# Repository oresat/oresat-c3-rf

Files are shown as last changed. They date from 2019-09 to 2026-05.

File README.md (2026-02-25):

# oresat-c3-rf
RF Sub systems for the C3 board.  This includes the transeiver ICs and all front-end components for the uplink and downlink radios.

## [AxSem_Profiles](AxSem_Profiles)
These are a bunch of profiles that initialize the AxSem RadioLab configuration program for testing and experiments.

## [KiCad](KiCad)
Evaluation board schematics and layouts in KiCad. Some of the older Eagle CAD boards are here converted to KiCAD.

## [block-diagrams](block-diagrams)
Block diagrams of the L band receiver and UHF transceiver hardware.

## [bom](bom)
Inventory and bill-of-materials (BOMs) for evaluation boards.

## [eagle](eagle)
Evaluation board schematics and layouts in EAGLE CAD.

## [link-models](link-models)
Complete link models for command/engineering channels, telemetry/public channels, and bulk mission data channels.

## [measurements](measurements)
Evaluation board measurements using lab tools.

## [simulations](simulations)
Evaluation board simulations using ADS and/or HFSS.

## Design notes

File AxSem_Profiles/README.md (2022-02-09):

# AxSem_Profiles
These are a bunch of AxSem RadioLab profiles, and they all run on the DVK-2 motherboard.
* NB: All EDL packets are "MSB first", otherwise "LSB first"
* **Be sure to scroll right to see all of profile detail**

| Profile name | Target | Conversion | Modulation | Bitrate | Traffic | Comments |
| --- | --- | --- | --- | --- | --- | --- |
| [AX_C3_L_RX](AX_C3_L_RX) | C3 board AX5043 | L band receive through pinheader | FSK | 60k | **Rx** / L band receiver side of BER test | Created |
| [AX_Radio_Board_L_TX_Send_EDL_TXEN](AX_Radio_Board_L_TX_Send_EDL_TXEN) | AxSem daughter board| L band upconverter | FSK | 60k | **Tx** / EDL "TXEN" packet | |
| [AX_Radio_Board_RX](AX_Radio_Board_RX) | AxSem daughter board | Direct UHF | FSK | 96k | **Rx** / Receiver side of BER test | Created |
| [AX_Radio_Board_TX](AX_Radio_Board_TX) | AxSem daughter board | Direct UHF | FSK | 96k | **Tx** / Transmitter side of BER test | Created |
| [AX_Radio_Board_TX_9600](AX_Radio_Board_TX_9600) | AxSem daughter board | Direct UHF | FSK / G3RUH | 9600 | **Tx** / Transmit AX.25 Packet with payload "Hi" | Created, configuration confirmed, tested working, **used frequently** |
| [AX_Radio_Board_TX_Send_EDL_FILEUP](AX_Radio_Board_TX_Send_EDL_FILEUP) | AxSem daughter board | Direct UHF | FSK | 60k | **Tx** / EDL "FILE UPLOAD" | Created, configuration confirmed, tested working, **used frequently**, small file |
| [AX_Radio_Board_TX_Send_EDL_TXDIS](AX_Radio_Board_TX_Send_EDL_TXDIS) | AxSem daughter board | Direct UHF | FSK | 60k | **Tx** / EDL "TXDIS" | |
| [AX_Radio_Board_TX_Send_EDL_TXEN](AX_Radio_Board_TX_Send_EDL_TXEN) | AxSem daughter board | Direct UHF | FSK | 60k | **Tx** / EDL "TXEN" | Created, configuration confirmed, tested working, **First successful EDL test** |
| [AX_Vigely_Dev_Board_L_RX](AX_Vigely_Dev_Board_L_RX) | Vigely's AX5043 dev board | L band downconverter | MSK | 120k | **Rx** / L band receiver side of BER test | Created, configuration confirmed, tested working, **This was also used with C3 board using pinheader** |
| [AX_Vigely_Dev_Board_L_TX](AX_Vigely_Dev_Board_L_TX) | Vigely's AX5043 dev board | L band upconverter | MSK | 120k | **Tx** / Transmitter side of BER test | Created, configuration confirmed, tested working |
| [AX_Vigely_Dev_Board_L_TX_Send_EDL_BIG_DATA](AX_Vigely_Dev_Board_L_TX_Send_EDL_BIG_DATA) | Vigely's AX5043 dev board | L band upconverter | FSK | 60k | **Tx** / EDL "FILE UPLOAD | 1k file; Fails |
| [AX_Vigely_Dev_Board_L_TX_Send_EDL_BIG_DATA_2](AX_Vigely_Dev_Board_L_TX_Send_EDL_BIG_DATA_2) | Vigely's AX5043 dev board | L band upconverter | FSK | 60k | **Tx** / EDL "FILE UPLOAD" | 240 byte EDL frame |
| [AX_Vigely_Dev_Board_L_TX_Send_EDL_TXDIS](AX_Vigely_Dev_Board_L_TX_Send_EDL_TXDIS) | Vigely's AX5043 dev board | L band upconverter | FSK | 60k | **Tx** / EDL "TXDIS" | Created, configuration confirmed, tested working, **Only works with external synth ref** |
| [AX_Vigely_Dev_Board_L_TX_Send_EDL_TXEN](AX_Vigely_Dev_Board_L_TX_Send_EDL_TXEN) | Vigely's AX5043 dev board | L band upconverter | FSK | 60k | **Tx** / EDL "TXEN" | |

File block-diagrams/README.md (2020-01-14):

## Block diagrams for the C3 communications channels

- The primary L band receiver on the satellite.<br>___L-band-receiver-vX.X.pdf___
  - 1260 to 1270 MHz uplink engineering channel
  - 1575 MHz GPS receiver

- The primary UHF transmitter and secondary receiver on the satellite.<br>___70cm-transceiver-vX.X.pdf___
  - 435 to 438 MHz downlink engineering and public channel
  - 435 to 438 MHz uplink engineering channel

## Power budget estimations

Power budget for the C3 card radios. Includes front-end components, AX5043 IC transceiver, and supply losses.  See Excel spreadsheet for more details: ___power-budget-c3-rf.xlsx___

### Summary:
| | <br><br>Power (mW) |  <br><br>Duty Cycle (%)  | Effective<br>Current (mA)<br>@ 7.2V | <br>Energy/period<br>(mWh) |
|---|:---:|:---:|:---:|:---:|
| <strong>L band Rx</strong> | 163 | 100 | 22.6 | 244 |
| <strong>UHF Rx</strong> | 70 | 98 | 9.6 | 104 |
| <strong>UHF Tx C.W. Beacon</strong> | 1260 | 1 | 1.7 | 19 |
| <strong>UHF Tx AX.25 Beacon</strong> | 2118 | 1 | 2.9 | 32 |
| | | <strong>TOTALS:</strong> | <strong>36.9</strong> | <strong>399</strong> |

#### Notes:
- L band Rx excludes GPS receiver
- UHF Tx C.W. beacon estimated for 0.1W PA output
- UHF Tx AX.25 beacon estimated for 1.0W PA output
- Period = LEO Orbit ~ 90 min

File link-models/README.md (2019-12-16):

## Link Budget Models for the C3 Channels

The source of these link model spreadsheets are from Jan King and are located at the [AMSAT-UK IARU website](http://www.amsatuk.me.uk/iaru/spreadsheet.htm).  The spreadsheets have been customized from revision 2.5.5 which are signified by a suffix letter.  In addition, for OreSat protocol information please visit our [GitHub protocol page](https://github.com/oresat/oresat-design/tree/gh-pages/protocol).  For OreSat's bulk-data mission uplink and downlink models using 802.11b please visit our [GitHub DxWiFi page](https://github.com/oresat/oresat-dxwifi-hardware).

- The primary engineering uplink and downlink using UniClOGS (University Class Open Ground Station)
  - ___OreSat1_link_model_v2.5.5a_eng_primary.xlsx  ([PDF summary](OreSat1_link_model_v2.5.5a_eng_primary.pdf))___
  - L band 1265 MHz GMSK uplink and UHF 436.5 MHz GMSK downlink

- The secondary engineering uplink using UniClOGS (University Class Open Ground Station)
  - ___OreSat1_link_model_v2.5.5a_eng_secondary.xlsx  ([PDF summary](OreSat1_link_model_v2.5.5a_eng_secondary.pdf))___
  - UHF 436.5 MHz GMSK uplink

- The amateur radio packet beacon, APRS downlink
  - ___OreSat1_link_model_v2.5.5a_packet_beacon.xlsx  ([PDF summary](OreSat1_link_model_v2.5.5a_packet_beacon.pdf))___
  - UHF 436.5 MHz G3RUH FSK w/ AX.25

- The amateur radio CW beacon
  - ___OreSat1_link_model_v2.5.5a_CW_beacon.xlsx  ([PDF summary](OreSat1_link_model_v2.5.5a_CW_beacon.pdf))___
  - UHF 436.5 MHz 20 WPM CW in 100Hz bandwidth

Notes:
- The 'Transmitters' and 'Receivers' sheets have been customized
  - Block diagrams reflect correct design
  - System noise temperature is more precise
- The 'System Performance Summary' sheet has been customized
  - Power levels in dBm
  - More link details

## Friis formula calculators
___Friis_noise_temp_calculators.xlsx___

The noise temperature calculators for the spacecraft and ground station receivers based on Friis formula.  The link model spreadsheets include Friis formula for use with an antenna as the source.  The calculator spreadsheet includes the following tabs for comparison.

- General: [Friis formula](https://en.wikipedia.org/wiki/Friis_formulas_for_noise)
- SME: A modified formula used for systems with an antenna as the source.  [Wertz, J., Everett, D., Puschell, J. (2011). Space Mission Engineering: The New SMAD (pp. 477). Hawthorne, CA: Microcosm Press.](http://www.sme-smad.com/)
- King: Jan King's formula based on SME. Assumes the effective temperature of the feed and passives prior to the first LNA is referenced from T<sub>0</sub>
- Subtotal: The Friis formula subtotal section used in the link model spreadsheets; Receivers sheet, T<sub>ComRcvr</sub> cell. Excludes the source (antenna) and passives prior to the first LNA

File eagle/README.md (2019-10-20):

## EAGLE CAD
Evaluation boards for the C3 board radios.

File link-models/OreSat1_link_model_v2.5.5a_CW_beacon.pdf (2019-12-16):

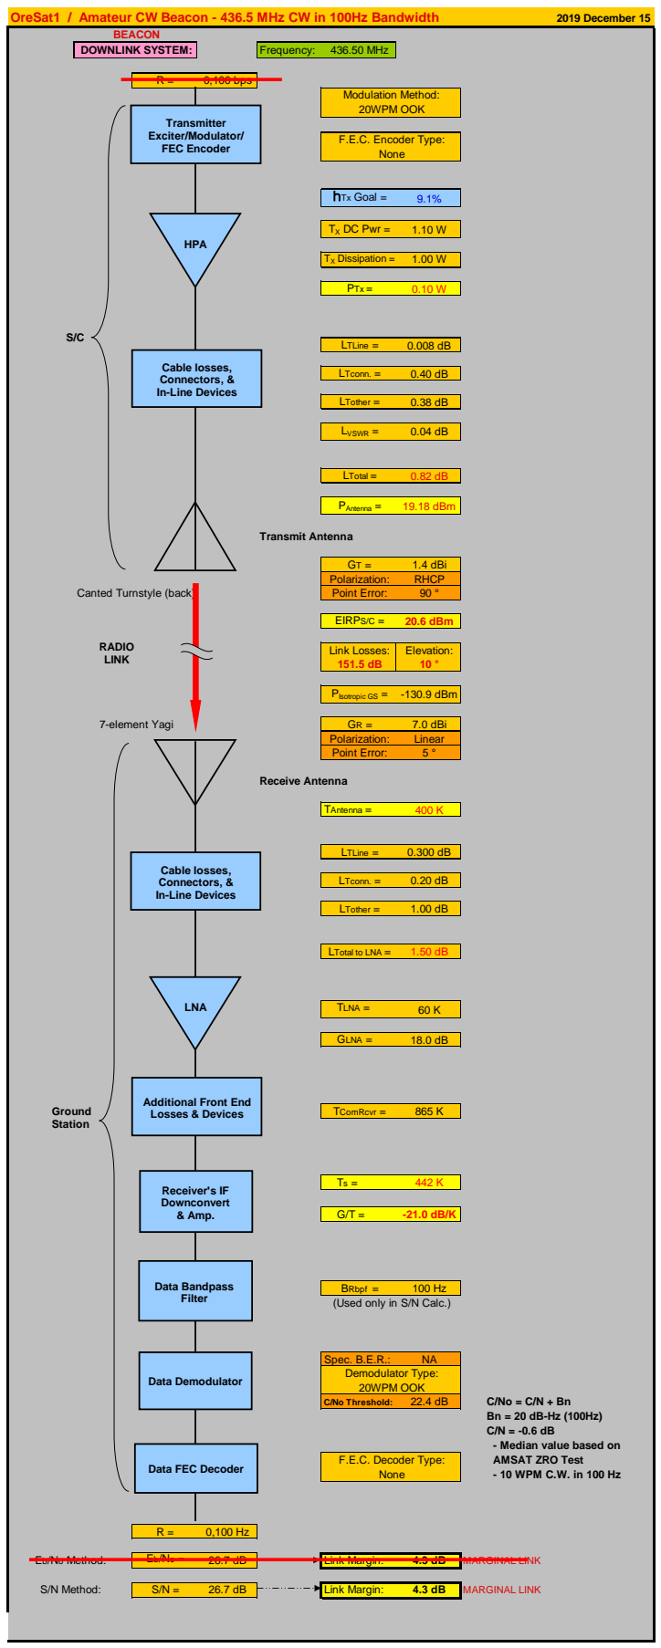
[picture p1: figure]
Frequency:; 436.50 MHz; 0,100 bps; hTx Goal =; TX DC Pwr =; TX Dissipation =; PTx =; LTLine =; LTconn. =; LTother =; LVSWR =; LTotal =; PAntenna =; 19.18 dBm; Transmit Antenna; 1.4 dBi; Polarization:; RHCP; Point Error:; EIRPS/C =; 20.6 dBm; Link Losses:; Elevation:; PIsotropic GS =; -130.9 dBm; 7.0 dBi; Linear; Receive Antenna; TAntenna =; LTotal to LNA =; TLNA =; GLNA =; TComRcvr =; BRbpf =; Spec. B.E.R.:; C/No Threshold:; Bn = 20 dB-Hz (100Hz) C/N = -0.6 dB - Median value based on AMSAT ZRO Test - 10 WPM C.W. in 100 Hz; Link Margin:; MARGINAL LINK; (Used only in S/N Calc.)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

OreSat1 / Amateur CW Beacon - 436.5 MHz CW in 100Hz Bandwidth | 2019 December 15

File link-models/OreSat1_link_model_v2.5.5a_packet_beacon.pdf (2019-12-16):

OreSat1 / Amateur Packet Beacon - 436.5 MHz G3RUH FSK via AX.25 | 2019 December 15
Frequency: | 436.50 MHz
R = | 9,600 bps
hTx Goal = | 51.3%
TX DC Pwr = | 1.95 W
TX Dissipation = | 0.95 W
PTx = | 1.00 W
LTLine = | 0.008 dB
LTconn. = | 0.40 dB
LTother = | 0.38 dB
LVSWR = | 0.04 dB
LTotal = | 0.82 dB
PAntenna = | 29.18 dBm

Transmit Antenna

GT = | 1.4 dBi
Polarization: | RHCP
Point Error: | 90 °
EIRPS/C = | 30.6 dBm
Link Losses: | Elevation:
152.4 dB | 10 °

PIsotropic GS = -120.9 dBm

GR = | 7.0 dBi
Polarization: | Linear
Point Error: | 20 °

Receive Antenna

TAntenna = | 400 K
LTLine = | 0.300 dB
LTconn. = | 0.20 dB
LTother = | 1.00 dB
LTotal to LNA = | 1.50 dB
TLNA = | 60 K
GLNA = | 18.0 dB
TComRcvr = | 865 K
Ts = | 442 K
G/T = | -21.0 dB/K
BRbpf = | 14400 Hz
Spec. B.E.R.: | 1.00E-04
Eb/No Threshold: | 10.7 dB
R = | 9,600 Hz
Eb/No = | 16.0 dB | Link Margin: | 5.3 dB | MARGINAL LINK
S/N = | 14.2 dB | Link Margin: | 3.5 dB | MARGINAL LINK

FSK, h=0.625, R.C.

BEACON
DOWNLINK SYSTEM:

Modulation Method:

F.E.C. Encoder Type:
None

Canted Turnstyle (back)

7-element Yagi

(Used only in S/N Calc.)

Demodulator Type:

S/N Method:

F.E.C. Decoder Type:
None

Eb/No Method:

FSK, h=0.625, R.C.

Ground
Station

S/C

RADIO
LINK

HPA

Transmitter
Exciter/Modulator/
FEC Encoder

Cable losses,
Connectors, &
In-Line Devices

Data FEC Decoder

Data Demodulator

Data Bandpass
Filter

LNA

Receiver's IF
Downconvert
& Amp.

Cable losses,
Connectors, &
In-Line | Devices
Additional | Front End
Losses & Devices

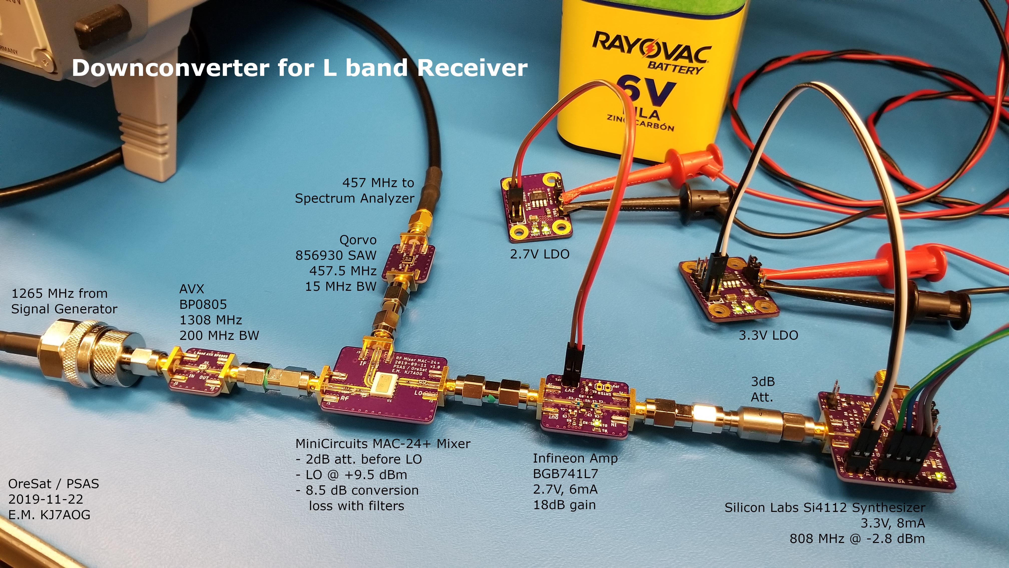
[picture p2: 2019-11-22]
photos/L-band-Downconverter.jpg

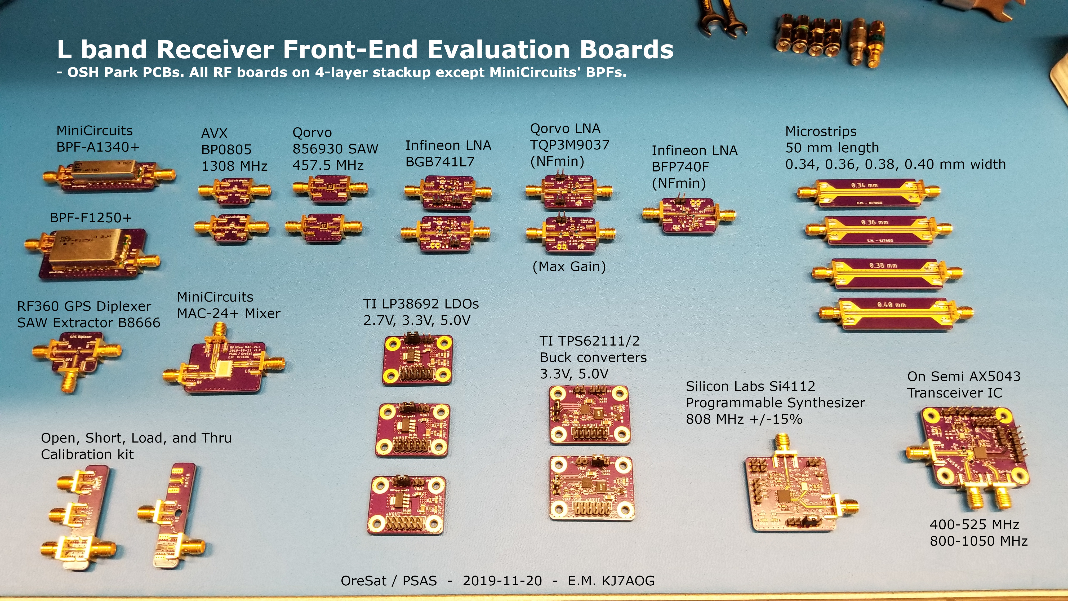
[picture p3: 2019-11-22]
photos/L-band-Eval-Boards.jpg

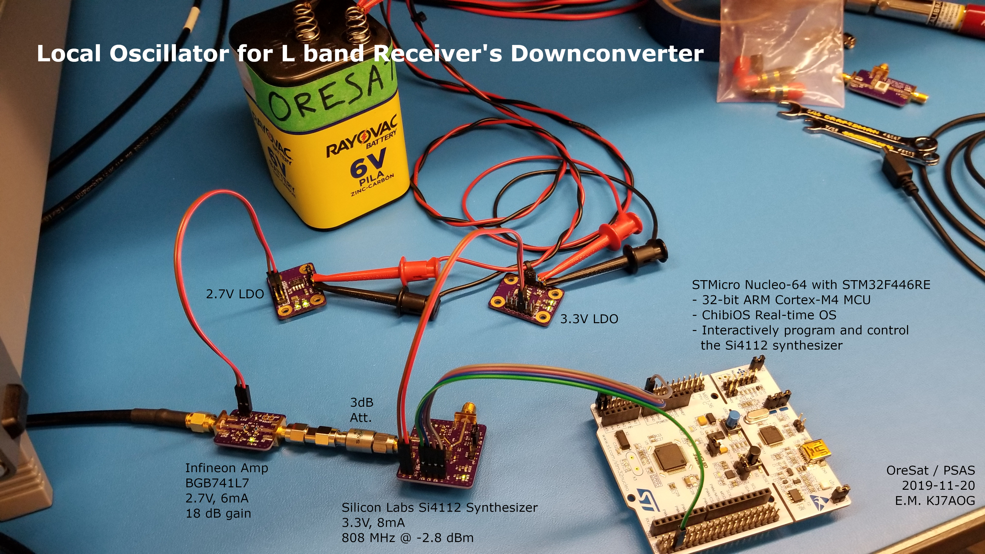
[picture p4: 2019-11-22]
photos/L-band-LO.jpg

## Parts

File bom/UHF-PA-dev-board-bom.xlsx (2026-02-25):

Bill Of Materials for OreSat UHF PA Evaluation Board
source file: amp-PA-GRF5504-with-detect.sch
Last modified: 02/24/2026
PCB version: 1.0 |  |  | P/DNP = | Place/Do Not Place (DNP is for final production boards)
BOM revision: 1 |  |  | Generic = | Any generic part with the same characteristics are OK (e.g., bypass cap)
Cnt | Part References | P/DNP | Mfg | Mfg PN | Description | Generic | Dist | Dist Part Number
1 | AT1 | P | Susumu | PAT1220-C-10DB-T5 | AT, 0805, 100mW, 10dB | N | Digikey | PAT1210CT-ND
3 | AT2, AT3, AT4 | P | Susumu | PAT0816-C-10DB-T5 | AT, 0603, 64mW, 10dB | N | Digikey | 408-2208-1-ND
3 | C12, C13 | DNP |  |  | C - 0603 | Y
2 | C9 | P | Samsung | CL10B104KA8NNNC | C - 0603, 100n, 25V, X7R | Y | Digikey | 1276-1006-1-ND
2 | C10 | P | Yageo | CC0603JRNPO9BN101 | C - 0603, 100p, 50V, C0G | Y | Digikey | 311-1069-1-ND
2 | C11 | P | Samsung | CL05C102JB5NNNC | C - 0402, 1n, C0G, 50V | Y | Digikey | 1276-1635-1-ND
1 | C16 | P | Murata | GJM1555C1H200FB01D | C - 0402, 20pF, | N | Digikey
1 | C17 | P | Murata | GJM1555C1H220FB01D | C - 0402, 22pF | N | Digikey
1 | C18 | P | Murata | GJM1555C1H3R0CB01J | C - 0402, 3pF, 50V | N | Digikey
2 | C19, C20 | P | Murata | GRM1555C1H101JA01J | C - 0402, 100pF, 50V | N | Digikey
2 | C21, C22 | P | Murata | GRM155R70J104KA01D | C - 0402, 0.1uF, 6.3V | Y | Digikey
1 | D1 | P | ROHM Semi. | SML-D13M8WT86 | LED - 0603, GREEN, Diffused | Y | Digikey | ‎846-1198-1-ND‎
2 | J1, J2 | P | Cinch | 142-0701-851 | SMA Jack Conn, 50ohm, edge mount | N | Mouser | 530-142-0701-851
1 | JP1, JP2, JP3, JP4, JP5 (1x14 req.) | P | Harwin | M20-9994045 | 2.54mm header, vertical strip, 1x40 | Y | Digikey | 952-3307-ND
1 | L1 | P | Murata | LQG15HS8N2J02D | L - 0402, 8.2nH, 5%, 550mA | N | Digikey
1 | L2 | P | Coilcraft | 0603DC-2N7XJRW | L - 0603, 2.7nH, 5%, 3.34A | N | Digikey
1 | L3 | P | Coilcraft | 0908SQ-23NJLC | L - 23n, 5%, 4.4A | N | Mouser
1 | L4 | P | Delta Electronics | 0402HP-5N6EHTS | L - 0402, 5.6nH, 3%, 1.6A | N | Digikey
1 | Q1 | P | Diodes Inc. | DMP2120U-7 | MOSFET, P-Chan, 20V, SOT23 | Y | Digikey | DMP2120U-7DICT-ND
1 | Q2 | P | Diodes Inc. | DMG2302UK-7 | MOSFET, N-Chan, 20V, SOT23 | Y | Digikey | DMG2302UK-7DICT-ND
1 | R1 | P | Stackpole | RMCF0603FT5K60 | R - 0603, 5.6k, 1%, 100ppm | Y | Digikey | RMCF0603FT5K60CT-ND
1 | R2 | P | Yageo | RC0402JR-073K3L | R - 0402, 4.4k, 5%, 100ppm | Y | Digikey
3 | R7, R8, R10 | P | Stackpole | RMCF0402FT47K0‎ | R - 0402, 47k, 1%, 100ppm | Y | Digikey | ‎RMCF0402FT47K0CT-ND‎
1 | R11 | P | Yageo | RC0402JR-076K8L | R - 0402, 6.8k, 5%, 100ppm | Y | Digikey
2 | R3, R4 | P | Stackpole | RNCF0402DTE47R0 | R - 0402, 47, 0.5%, 25ppm | Y | Digikey | RNCF0402DTE47R0CT-ND
3 | R5, R6, JP6 | P | Stackpole | RMCF0603ZT0R00‎ | R - 0603, 0, jumper | Y | Digikey | RMCF0603ZT0R00CT-ND‎
1 | U1 | P | Guerrilla | GRF5504 | PA -100 - 500MHz, 3.5W | N | Mouser
1 | U2 | P | Mini-Circuits | BDCN-20-13+ | Coupler - Bi-directional | N | Mouser | 139-BDCN-20-13
2 | U3, U4 | P | Analog Devices | LT5534ESC6#TRPBF | IC, RF Detect, 50MHz-3GHz | N | Digikey | LT5534ESC6#TRPBFCT-ND
VERSION INFO
Rev | Date | Notes
2 | 2026-02-24

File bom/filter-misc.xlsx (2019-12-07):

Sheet: bpf-L-band-BPF-F1250+
Bill Of Materials
Source: bpf-L-band-F1250+.sch |  |  | P/DNP = | Place/Do Not Place (DNP is for final production boards)
Modified: 2019-09-25 |  |  | Generic = | Any generic part with the same characteristics are OK (e.g., bypass cap)
Revision: 1
Cnt | Status | Part References | P/DNP | Mfg | Mfg PN | Description | Distributor | Dist. PN | Generic | Notes | URL
2 | USED | J1, J2 | P | Cinch | 142-0701-851 | SMA Jack Conn, 50ohm, edge mount | Dig / Mou | J658-ND / 530-142-0701-851 | N
1 | USED | U1 | P | Mini-Circuits | BPF-F1250+ | Filter - BPF, 1050 - 1450 MHz | Mini-Circuits |  | N
Revision History
Rev | Date | Notes
1 | 2019-09-25 | Initial BOM.
 | 2019-10-26 | Assembled 1x board

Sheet: bpf-L-band-BPF-A1340+
Bill Of Materials
Source: bpf-L-band-A1340+.sch |  |  | P/DNP = | Place/Do Not Place (DNP is for final production boards)
Modified: 2019-09-25 |  |  | Generic = | Any generic part with the same characteristics are OK (e.g., bypass cap)
Revision: 1
Cnt | Status | Part References | P/DNP | Mfg | Mfg PN | Description | Distributor | Dist. PN | Generic | Notes | URL
2 | USED | J1, J2 | P | Cinch | 142-0701-851 | SMA Jack Conn, 50ohm, edge mount | Dig / Mou | J658-ND / 530-142-0701-851 | N
1 | USED | U1 | P | Mini-Circuits | BPF-A1340+ | Filter - BPF, 1000 - 1800 MHz | Mini-Circuits |  | N
Revision History
Rev | Date | Notes
1 | 2019-09-25 | Initial BOM.
 | 2019-11-01 | Assembled 1x board

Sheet: bpf-IF-SAW-856930
Bill Of Materials
Source: bpf-IF-SAW-856930.sch |  |  | P/DNP = | Place/Do Not Place (DNP is for final production boards)
Modified: 2019-09-25 |  |  | Generic = | Any generic part with the same characteristics are OK (e.g., bypass cap)
Revision: 1
Cnt | Status | Part References | P/DNP | Mfg | Mfg PN | Description | Distributor | Dist. PN | Generic | Notes | URL
4 | USED | J1, J2 | P | Cinch | 142-0701-851 | SMA Jack Conn, 50ohm, edge mount | Dig / Mou | J658-ND / 530-142-0701-851 | N
2 | USED | U1 | P | Qorvo | 856930 | Filter - SAW, 457.5 MHz, 15 MHz | Mouser | 772-856930 | N | EOL
Revision History
Rev | Date | Notes
1 | 2019-09-25 | Initial BOM.
 | 2019-10-02 | Assembled 1x board
 | 2019-11-13 | Assembled 1x board

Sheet: bpf-L-band-BP0805
Bill Of Materials
Source: bpf-L-band-BP0805.sch |  |  | P/DNP = | Place/Do Not Place (DNP is for final production boards)
Modified: 2019-09-25 |  |  | Generic = | Any generic part with the same characteristics are OK (e.g., bypass cap)
Revision: 1
Cnt | Status | Part References | P/DNP | Mfg | Mfg PN | Description | Distributor | Dist. PN | Generic | Notes | URL
4 | USED | J1, J2 | P | Cinch | 142-0701-851 | SMA Jack Conn, 50ohm, edge mount | Dig / Mou | J658-ND / 530-142-0701-851 | N
2 | USED | U1 | P | AVX Corp | BP0805A1308ASTR | Filter, thin-film 0805, 1220 - 1420 MHz | Digikey | 478-12187-1-ND | N
Revision History
Rev | Date | Notes
1 | 2019-09-25 | Initial BOM.
 | 2019-10-19 | Assembled 1x board
 | 2019-10-26 | Assembled 1x board
 | 2019-12-06 | Assembled 1x board

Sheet: diplexer-GPS-RF360-B8666
Bill Of Materials
Source: diplexer-GPS-RF360-B8666.sch |  |  | P/DNP = | Place/Do Not Place (DNP is for final production boards)
Modified: 2019-09-25 |  |  | Generic = | Any generic part with the same characteristics are OK (e.g., bypass cap)
Revision: 1
Cnt | Status | Part References | P/DNP | Mfg | Mfg PN | Description | Distributor | Dist. PN | Generic | Notes | URL
3 | USED | J1, J2, J3 | P | Cinch | 142-0701-851 | SMA Jack Conn, 50ohm, edge mount | Dig / Mou | J658-ND / 530-142-0701-851 | N
1 | USED | U1 | P | RF360 | B39162B8666L210 | Diplexer, GPS SAW extractor | Digikey | B39162B8666L210CT-ND | N
Revision History
Rev | Date | Notes
1 | 2019-09-25 | Initial BOM.
 | 2019-10-19 | Assembled 1x board

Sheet: mixer-MAC-24+
Bill Of Materials
Source: mixer-MAC-24+.sch |  |  | P/DNP = | Place/Do Not Place (DNP is for final production boards)
Modified: 2019-09-25 |  |  | Generic = | Any generic part with the same characteristics are OK (e.g., bypass cap)
Revision: 1
Cnt | Status | Part References | P/DNP | Mfg | Mfg PN | Description | Distributor | Dist. PN | Generic | Notes | URL
3 | USED | J1, J2, J3 | P | Cinch | 142-0701-851 | SMA Jack Conn, 50ohm, edge mount | Dig / Mou | J658-ND / 530-142-0701-851 | N
1 | USED | U1 | P | Mini-Circuits | MAC-24+ | Mixer - double balanced | Mini-Circuits |  | N
1 | USED | AT1, AT2, AT3 | DNP | Susumu | PAT1220-C-2DB-T5 | AT, 0805, 100mW, 2dB | Digikey | PAT122CT-ND | Y | On LO
3 | USED | Z1, Z2, Z3 | P | Stackpole | RMCF0402ZT0R00‎ | R - 0402, 0, jumper | Digikey | RMCF0402ZT0R00CT-ND‎ | Y
3 | USED | AT1, AT2, AT3 | P | Stackpole | RMCF0603ZT0R00‎ | R - 0603, 0, jumper | Digikey | RMCF0603ZT0R00CT-ND‎ | Y
Revision History
Rev | Date | Notes
1 | 2019-09-25 | Initial BOM.
 | 2019-09-30 | Assembled 1x board w/ all 0 ohm
 | 2019-10-26 | Added 2dB att to LO
 | 2019-12-06 | Assembled 1x board w/ matching networks

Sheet: quad-hybrid-QCN-xxx+
Bill Of Materials
Source: quad-hybrid-QCN-xxx+.sch |  |  | P/DNP = | Place/Do Not Place (DNP is for final production boards)
Modified: 2019-11-10 |  |  | Generic = | Any generic part with the same characteristics are OK (e.g., bypass cap)
Revision: 1
Cnt | Status | Part References | P/DNP | Mfg | Mfg PN | Description | Distributor | Dist. PN | Generic | Notes | URL
3 | INV | J1, J2, J3 | P | Cinch | 142-0701-851 | SMA Jack Conn, 50ohm, edge mount | Dig / Mou | J658-ND / 530-142-0701-851 | N
 | - | J4 | DNP | Cinch | 142-0701-851 | SMA Jack Conn, 50ohm, edge mount | Dig / Mou | J658-ND / 530-142-0701-851 | N
2 | INV | R1, R2 | P | Yageo | RT0402BRD07100RL | R - 0402, 100, 0.1%, 25ppm | Digikey | YAG2301CT-ND | Y | Precision 100 ohm resistor
Revision History
Rev | Date | Notes
1 | 2019-11-10 | Initial BOM.

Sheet: template
Bill Of Materials
Source: schematic-name.sch |  |  | P/DNP = | Place/Do Not Place (DNP is for final production boards)
Modified: yyyy-mm-dd |  |  | Generic = | Any generic part with the same characteristics are OK (e.g., bypass cap)
Revision: 1
Cnt | Status | Part References | P/DNP | Mfg | Mfg PN | Description | Distributor | Dist. PN | Generic | Notes | URL
Revision History
Rev | Date | Notes
1 | yyyy-mm-dd | Initial BOM.

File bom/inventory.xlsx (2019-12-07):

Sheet: Inventory
Inventory of parts for all boards
Cnt | Status | Mfg | Mfg PN | Description | Distributor | Dist. PN | Notes
0 | C3-RF Box | Harwin | M20-9980645 | 2.54mm header, vertical strip, 12 pos (2x6) | Digikey | 952-2125-ND
69 | C3-RF Box | Harwin | M20-9994045 | 2.54mm header, vertical strip, 1x40 (by x1) | Digikey | 952-3307-ND
24 | C3-RF Box | Harwin | M20-1060200 | 2.54mm housing, 2 position | Digikey | 952-2227-ND
9 | C3-RF Box | Harwin | M20-1060400 | 2.54mm housing, 4 position | Digikey | 952-2229-ND
4 | C3-RF Box | Susumu | PAT1220-C-2DB-T5 | AT, 0805, 100mW, 2dB | Digikey | PAT122CT-ND
1 | C3-RF Box | Susumu | PAT1220-C-4DB-T5 | AT, 0805, 100mW, 4dB | Digikey | PAT124CT-ND
2 | C3-RF Box | Susumu | PAT1220-C-6DB-T5 | AT, 0805, 100mW, 6dB | Digikey | PAT126CT-ND
2 | C3-RF Box | Susumu | PAT1220-C-8DB-T5 | AT, 0805, 100mW, 8dB | Digikey | PAT128CT-ND
1 | C3-RF Box | MPD | SBH431-1AS | Battery holder, 3x AAA, cover, 6" leads, switch | Digikey | SBH431-1AS-ND
1 | C3-RF Box | TI | TPS62112RSAR | Buck Reg, 5.0V, 1.5A | Digikey | ‎296-39444-1-ND‎
6 | C3-RF Box | Samsung | CL05C8R2CB5NNNC | C - 0402 8.2p, C0G, 50V | Digikey | ‎1276-1729-1-ND
6 | C3-RF Box | Samsung | CL05C102JB5NNNC | C - 0402, 1n, C0G, 50V | Digikey | 1276-1635-1-ND
10 | C3-RF Box | Kemet | C0402C222J3GACTU | C - 0402, 2.2n, C0G, 25V | Digikey | 399-8957-1-ND
88 | C3-RF Box | Samsung | CL05C220JB5NNNC‎ | C - 0402, 22p, C0G, 50V | Digikey | ‎1276-1116-1-ND
96 | C3-RF Box | Samsung | CL05C561JB5NNNC | C - 0402, 560p, C0G, 50V | Digikey | 1276-1709-1-ND
8 | C3-RF Box | Samsung | CL05C060CB5NNNC | C - 0402, 6.0p, C0G, 50V | Digikey | 1276-1607-1-ND
6 | C3-RF Box | Samsung | CL05C820JB5NNNC | C - 0402, 82p, C0G, 50V | Digikey | ‎1276-1726-1-ND
8 | C3-RF Box | Samsung | CL10C103JA8NNNC | C - 0603, 10n, C0G, 25V | Digikey | 1276-2172-1-ND
86 | C3-RF Box | Samsung | CL10A105KA8NNNC | C - 0603, 1u, X5R, 25V | Digikey | 1276-1102-1-ND
87 | C3-RF Box | Samsung | CL10B223KA8NNNC | C - 0603, 22n, X7R, 25V | Digikey | 1276-1999-1-ND
6 | C3-RF Box | Samsung | CL10A475KO8NNNC | C - 0603, 4.7u, X5R, 16V | Digikey | 1276-1784-1-ND
92 | C3-RF Box | Samsung | CL10B473KB8NNNC | C - 0603, 47n, X7R, 50V | Digikey | 1276-1063-1-ND
95 | C3-RF Box | Samsung | CL21A106KOQNNNG | C - 0805, 10u, X5R, 16V | Digikey | 1276-6455-1-ND
3 | C3-RF Box | Samsung | CL31A226KOHNNNE | C - 1206, 22u, X5R, 16V | Digikey | 1276-3048-1-ND
1+ | Glenn? | Mini-Circuits | BDCN-20-13+ | Coupler - Bi-directional | Mini-Circuits
1 | C3-RF Box | On Semi | BAS16XV2T1G | Diode, Gen Purp, 200mA, SOD523 | Digikey | BAS16XV2T1GOSCT-ND
1 | C3-RF Box | RF360 | B39162B8666L210 | Diplexer, GPS SAW extractor | Digikey | B39162B8666L210CT-ND
0 | C3-RF Box | Mini-Circuits | BPF-A1340+ | Filter - BPF, 1000 - 1800 MHz | Mini-Circuits
2 | C3-RF Box | Mini-Circuits | BPF-F1250+ | Filter - BPF, 1050 - 1450 MHz | Mini-Circuits
6 | C3-RF Box | Mini-Circuits | BPF-C450+ | Filter - BPF, 400 - 510 MHz | Mini-Circuits
8 | C3-RF Box | Qorvo | 856930 | Filter - SAW, 457.5 MHz, 15 MHz | Mouser | 772-856930 | EOL
0 | C3-RF Box | AVX Corp | BP0805A1308ASTR | Filter, thin-film 0805, 1220 - 1420 MHz | Digikey | 478-12187-1-ND
2 | C3-RF Box | Coilcraft | 0402CS-1N8XGL | L - 0402, 1.8n | Mouser | 994-0402CS-1N8XGLU
0 | C3-RF Box | Coilcraft | 0402HP-18NXGL | L - 0402, 18n | Mouser | 994-0402HP-18NXGLU
1 | C3-RF Box | Coilcraft | 0402CS-2N0XGL | L - 0402, 2.0n | Mouser | 994-0402CS-2N0XGLW
1 | C3-RF Box | Coilcraft | 0402CS-3N9XGL | L - 0402, 3.9n | Mouser | 994-0402CS-3N9XGLW
6 | C3-RF Box | Murata | LQW15AN43NG8ZD | L - 0402, 43n, 515mA, 516mohm, +/-2% | Digikey | 490-15447-1-ND
2 | C3-RF Box | Coilcraft | 0402HP-47NXGL | L - 0402, 47n | Mouser | 994-0402HP-47NXGLU
5 | C3-RF Box | Murata | LQW18AN10NG00D‎ | L - 0603, 10n, 650mA, 110mohm, +/-2% | Digikey | 490-6856-1-ND
0 | C3-RF Box | Murata | LQW18AN27NG00D | L - 0603, 27n, 440mA, 210mohm, +/-2% | Digikey | 490-6879-1-ND
5 | C3-RF Box | Murata | LQW18AN91NG8ZD | L - 0603, 91n, 520mA, 540mohm, +/-2% | Digikey | 490-15756-1-ND
8 | C3-RF Box | TI | LP2985IM5-1.8/NOPB | LDO Voltage Regulator, 150mA, EN, 1.8V Fixed | Digikey | LP2985IM5-1.8/NOPBCT-ND
1 | C3-RF Box | TI | LP38692MP-3.3/NOPB | LDO Voltage Regulator, 1A, EN, 3.3V Fixed | Digikey | LP38692MP-3.3/NOPBCT-ND
2 | C3-RF Box | TI | LP38692MP-5.0/NOPB | LDO Voltage Regulator, 1A, EN, 5.0V Fixed | Digikey | ‎LP38692MP-5.0/NOPBCT-ND
2 | C3-RF Box | TI | LP38692MP-ADJ/NOPB | LDO Voltage Regulator, 1A, EN, Adjustable | Digikey | LP38692MP-ADJ/NOPBCT-ND
10 | C3-RF Box | ROHM Semi. | SML-D13M8WT86 | LED - 0603, GREEN, Diffused | Digikey | ‎846-1198-1-ND‎
5 | C3-RF Box | ROHM Semi. | SML-D12U8WT86‎ | LED - 0603, RED, Diffused | Digikey | 511-1580-1-ND‎
4 | C3-RF Box | Infineon | BGB707L7ESDE6327XTSA1 | LNA, general purpose | Mouser | 726-SP000531308
1 | C3-RF Box | Infineon | BGB741L7ESDE6327XTSA1‎ | LNA, general purpose | Digikey | ‎BGB741L7ESDE6327XTSA1CT-ND
4 | C3-RF Box | Qorvo | TQP3M9036 | LNA, high performance | Mouser | 772-TQP3M9036
1 | C3-RF Box | Qorvo | TQP3M9037 | LNA, high performance | Mouser | 772-TQP3M9037
0 | C3-RF Box | Infineon | BFP740FH6327XTSA1 | LNA, RF Transistor, NPN, 42GHz, TSFP4 | Digikey | BFP740FH6327XTSA1CT-ND
1 | C3-RF Box | Mini-Circuits | MAC-24+ | Mixer - double balanced | Mini-Circuits
5 | C3-RF Box | Diodes Inc. | DMP2120U-7 | MOSFET, P-Chan, 20V, SOT23 | Digikey | DMP2120U-7DICT-ND
3 | C3-RF Box | Qorvo | TQP7M9105 | PA, 50 - 1500 MHz, 1W, 5V | Mouser | 772-TQP7M9105
3 | C3-RF Box | Silicon Labs | SI4123-D-GM | PLL RF Synthesizer, dual out, RF1 & IF | Mouser | 634-SI4123-D-GM
2 | C3-RF Box | Silicon Labs | SI4112-D-GM | PLL RF Synthesizer, single out, IF | Mouser | 634-SI4112-D-GM
3 | C3-RF Box | Mini-Circuits | QCN-19+ | Quadrature hybrid, 1100 - 1925 MHz | Mini-Circuits
107 | C3-RF Box | Stackpole | RMCF0402ZT0R00‎ | R - 0402, 0, jumper | Digikey | RMCF0402ZT0R00CT-ND‎
9 | C3-RF Box | Stackpole | RMCF0402FT1K00CT-ND | R - 0402, 1.0k, 1%, 100ppm | Digikey | RMCF0402FT1K00CT-ND
10 | C3-RF Box | Yageo | RT0402BRD07100RL | R - 0402, 100, 0.1%, 25ppm | Digikey | YAG2301CT-ND
2 | C3-RF Box | Yageo | RT0402BRD0711K8L‎ | R - 0402, 11.8k, 0.1%, 25ppm | Digikey | ‎YAG4166CT-ND‎
2 | C3-RF Box | Yageo | RT0402BRD0713K7L‎ | R - 0402, 13.7k, 0.1%, 25ppm | Digikey | ‎YAG4172CT-ND
83 | C3-RF Box | Stackpole | RMCF0402FT47K0‎ | R - 0402, 47k, 1%, 100ppm | Digikey | ‎RMCF0402FT47K0CT-ND‎
79 | C3-RF Box | Stackpole | RMCF0603ZT0R00‎ | R - 0603, 0, jumper | Digikey | RMCF0603ZT0R00CT-ND‎
4 | C3-RF Box | Stackpole | RMCF0603FT1K50‎ | R - 0603, 1.5k, 1%, 100ppm | Digikey | ‎RMCF0603FT1K50CT-ND
8 | C3-RF Box | Stackpole | RMCF0603FT10K0‎ | R - 0603, 10k, 1%, 100ppm | Digikey | ‎RMCF0603FT10K0CT-ND
90 | C3-RF Box | Stackpole | RMCF0603FT2K70‎ | R - 0603, 2.7k, 1%, 100ppm | Digikey | RMCF0603FT2K70CT-ND‎
9 | C3-RF Box | Stackpole | RMCF0603FT220R | R - 0603, 220, 1%, 100ppm | Digikey | RMCF0603FT220RCT-ND
9 | C3-RF Box | Stackpole | RMCF0603FT27R0 | R - 0603, 27, 1%, 100ppm | Digikey | RMCF0603FT27R0CT-ND
8 | C3-RF Box | Stackpole | RMCF0603FT27K0‎ | R - 0603, 27k, 1%, 100ppm | Digikey | RMCF0603FT27K0CT-ND
9 | C3-RF Box | Stackpole | RMCF0603FT39R0 | R - 0603, 39, 1%, 100ppm | Digikey | RMCF0603FT39R0CT-ND
9 | C3-RF Box | Stackpole | RMCF0603FT45K3 | R - 0603, 45.3k, 1%, 100ppm | Digikey | RMCF0603FT45K3CT-ND
3 | C3-RF Box | Stackpole | RMCF0603FT5K60 | R - 0603, 5.6k, 1%, 100ppm | Digikey | RMCF0603FT5K60CT-ND
8 | C3-RF Box | On Semi | AX5043-1-TW30 | RF Transceiver, 1GHz max | Digikey | AX5043-1-TW30OSCT-ND
11 | C3-RF Box | Cinch | 142-0701-851 | SMA Jack Conn, 50ohm, edge mount | Digikey/Mouser | J658-ND / 530-142-0701-851
10 | C3-RF Box | Amphenol | 132360 | SMA Male Terminator, 50 ohm | Digikey | ACX1251-ND
94 | C3-RF Box | Harwin | M20-1160042 | Socket contact, gold, crimp, 22-30 AWG | Digikey | 952-2157-1-ND
8 | C3-RF Box | Taitien | TYKTBLSANF-16.000000 | TCXO, 16.000 MHz, 1.8V, Clipped SW, 1ppm | Digikey | 1664-1323-1-ND
7 | C3-RF Box | ECS | ECS-TXO-3225-160-TR | TCXO, 16.000 MHz, 3.3V, HCMOS, 2.5ppm | Mouser | 520-TXO-3225-16.0T
History
Date | Notes
- | Initial Inventory
2019-07-29 | Assembled 2x microstrip-test-4-layer-sma-34-40
2019-08-23 | Assembled 1x synthesizer-Si4123
2019-09-30 | Assembled 1x mixer-MAC-24+ w/ all 0 ohm
2019-10-02 | Assembled 1x LP38692-adj-2.7, LP38692-3.3, and SAW-856930 boards
2019-10-04 | Assembled 1x TPS62111-3.3, and 2x microstrip-text-4-layer-sma-36-38
2019-10-05 | Assembled 1x TPS62112-5.0, and LP38692-5.0
2019-10-06 | Assembled 1x sythesizer-Si4112
2019-10-07 | Assembled 1x LNA-TQP3M9037
2019-10-19 | Assembled 1x Diplexer-B8666, 1x AVX BPF BP0805, and 1x LNA-BGB741L7ESD
2019-10-26 | Assembled 1x AVX BPF BP0805, and added 2dB att to mixer LO
2019-10-26 | Assembled 1x BPF-F1250+
2019-11-01 | Received MiniCircuits samples, 1x BPF-A1340+, 2x MAC-24+
2019-11-01 | Assembled 1x BPF-A1340+
2019-11-13 | Assembled 1x SAW-856930, 1x LNA-TQP3M9037, 1x LNA-BGB741L7ESD
2019-11-17 | Assembled 1x transceiver-AX5043
2019-11-18 | Assembled 1x LNA-BFP740F
2019-12-06 | Assembled 1x synthesizer-Si4112, transceiver-AX5043, mixer-MAC-24+ w/ matching, AVX BPF BP0805

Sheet: Boards
Inventory of evaluation boards
Name | Board | Available | Assembled | Stencil | BOM | BOM File | Notes
amp-LNA-BFP740Fxxx | RCVD | 2 | 1 | REORD ? | RCVD | amps | Stencil fixed tCream on BFP7xxF
amp-LNA-BGB741L7ESD | RCVD | 1 | 2 | RCVD | RCVD | amps
amp-LNA-L-band-TQP3M9037 | RCVD | 3 |  | RCVD |  | amps
amp-LNA-S-band-TQP3M9037 | RCVD | 1 | 2 | RCVD | RCVD | amps | Used for L and S band; new name amp-LNA-TQP3M9037
amp-LNA-UHF-TQP3M9036 | RCVD | 3 |  | RCVD |  | amps
bpf-IF-SAW-856930 | RCVD | 1 | 2 | RCVD | RCVD | filter-misc
bpf-L-band-BP0805 | RCVD | 0 | 3 | RCVD | RCVD | filter-misc
bpf-L-band-BPF-A1340+ | RCVD | 2 | 1 | NA | RCVD | filter-misc
bpf-L-band-BPF-F1250+ | RCVD | 2 | 1 | NA | RCVD | filter-misc
diplexer-GPS-RF360-B8666 | RCVD | 2 | 1 | RCVD | RCVD | filter-misc
microstrip-test-4-layer-sma-34-40 | RCVD | 1 | 2 | NA | RCVD | test-boards
microstrip-test-4-layer-sma-36-38 | RCVD | 2 | 2 | NA | RCVD | test-boards
mixer-MAC-24+ | RCVD | 2 | 1 | REORD ? | RCVD | filter-misc | Stencil fixed tCream on MAC-24+
power-linear-LP38692 | RCVD | 0 | 3 | RCVD | RCVD | power | Variations: 3.3V fix, 2.7V adj, 5.0V fix
power-switching-TPS6211x | RCVD | 1 | 2 | RCVD | RCVD | power | Variations: 3.3V fix, 5.0V fix
quad-hybrid-QCN-xxx+ | ORDRD |  |  | RCVD | RCVD | filter-misc
synthesizer-IF-Si4112 | RCVD | 1 | 2 | RCVD | RCVD | synthesizers
synthesizer-RF-Si4123 | RCVD | 2 | 1 | RCVD | RCVD | synthesizers
transceiver-AX5043 | RCVD | 4 | 2 | RCVD | RCVD | radio
calibration-thru-reflect-match-sma | RCVD | 1 | 2 | NA | RCVD | test-boards | microstrip-test-38 used for line standard, thru can be cut for open standard

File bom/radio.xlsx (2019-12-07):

Bill Of Materials
Source: transceiver-AX5043.sch |  |  | P/DNP = | Place/Do Not Place (DNP is for final production boards)
Modified: 2019-11-10 |  |  | Generic = | Any generic part with the same characteristics are OK (e.g., bypass cap)
Revision: 1
Cnt | Status | Part References | P/DNP | Mfg | Mfg PN | Description | Distributor | Dist. PN | Generic | Notes | URL
2 | USED | JP1, JP5 |  | Harwin | M20-9994045 | 2.54mm header, vertical strip, 1x40 (by x1) | Digikey | 952-3307-ND
2 | USED | JP2, JP6 |  | Harwin | M20-9994045 | 2.54mm header, vertical strip, 1x40 (by x1) | Digikey | 952-3307-ND
1 | USED | JP3 |  | Harwin | M20-9994045 | 2.54mm header, vertical strip, 1x40 (by x1) | Digikey | 952-3307-ND
1 | USED | JP4 |  | Harwin | M20-9994045 | 2.54mm header, vertical strip, 1x40 (by x1) | Digikey | 952-3307-ND
2 | USED | C1, C2 |  | Samsung | CL05C8R2CB5NNNC | C - 0402 8.2p, C0G, 50V | Digikey | ‎1276-1729-1-ND
2 | USED | C3, C4 |  | Samsung | CL05C102JB5NNNC | C - 0402, 1n, C0G, 50V | Digikey | 1276-1635-1-ND
2 | USED | C7, C8 |  | Samsung | CL05C220JB5NNNC‎ | C - 0402, 22p, C0G, 50V | Digikey | ‎1276-1116-1-ND
2 | USED | C5, C6 |  | Samsung | CL05C820JB5NNNC | C - 0402, 82p, C0G, 50V | Digikey | ‎1276-1726-1-ND
3 | - | C9, C11, C14 | NP |  |  | C - 0603
1 | USED | C16 |  | Samsung | CL10C103JA8NNNC | C - 0603, 10n, C0G, 25V | Digikey | 1276-2172-1-ND
1 | USED | C17 |  | Samsung | CL10A105KA8NNNC | C - 0603, 1u, X5R, 25V | Digikey | 1276-1102-1-ND
2 | USED | C10, C13 |  | Samsung | CL10B223KA8NNNC | C - 0603, 22n, X7R, 25V | Digikey | 1276-1999-1-ND
2 | USED | C12, C15 |  | Samsung | CL10A475KO8NNNC | C - 0603, 4.7u, X5R, 16V | Digikey | 1276-1784-1-ND
2 | USED | L1, L2 |  | Murata | LQW15AN43NG8ZD | L - 0402, 43n, 515mA, 516mohm, +/-2% | Digikey | 490-15447-1-ND
2 | USED | L3, L4 |  | Murata | LQW18AN91NG8ZD | L - 0603, 91n, 520mA, 540mohm, +/-2% | Digikey | 490-15756-1-ND
1 | USED | U2 |  | TI | LP2985IM5-1.8/NOPB | LDO Voltage Regulator, 150mA, EN, 1.8V Fixed | Digikey | LP2985IM5-1.8/NOPBCT-ND | Y
1 | USED | D1 |  | ROHM Semi. | SML-D13M8WT86 | LED - 0603, GREEN, Diffused | Digikey | ‎846-1198-1-ND‎
1 | - | R3 | NP |  |  | R - 0402
3 | USED | R2, R8, R9 |  | Stackpole | RMCF0402ZT0R00‎ | R - 0402, 0, jumper | Digikey | RMCF0402ZT0R00CT-ND‎
1 | USED | R1 |  | Stackpole | ?? | R - 0402, 150 ohm | Digikey | ?? |  | Updated to 150 ohm from 1k
2 | - | R4, R5 | NP |  |  | R - 0603
1 | USED | R7 |  | Stackpole | RMCF0603ZT0R00‎ | R - 0603, 0, jumper | Digikey | RMCF0603ZT0R00CT-ND‎
1 | USED | R6 |  | Stackpole | RMCF0603FT1K50‎ | R - 0603, 1.5k, 1%, 100ppm | Digikey | ‎RMCF0603FT1K50CT-ND
1 | USED | U1 |  | On Semi | AX5043-1-TW30 | RF Transceiver, 1GHz max | Digikey | AX5043-1-TW30OSCT-ND
3 | USED | J1, J2, J3 |  | Cinch | 142-0701-851 | SMA Jack Conn, 50ohm, edge mount | Digikey/Mouser | J658-ND / 530-142-0701-851
1 | USED | X1 |  | Taitien | TYKTBLSANF-16.000000 | TCXO, 16.000 MHz, 1.8V, Clipped SW, 1ppm | Digikey | 1664-1323-1-ND | N
Revision History
Rev | Date | Notes
1 | 2019-11-10 | Initial BOM.
 | 2019-11-17 | Assembled 1x transceiver-AX5043
 | 2019-12-06 | Assembled 1x transceiver-AX5043

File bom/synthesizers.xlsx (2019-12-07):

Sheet: synthesizer-IF-Si4112
Bill Of Materials
Source: synthesizer-IF-Si4112.sch |  |  | P/DNP = | Place/Do Not Place
Modified: 2019-09-25 |  |  | Generic = | Any generic part with the same characteristics
Revision: 1
Cnt | Status | Part References | P/DNP | Mfg | Mfg PN | Description | Distributor | Dist. PN | Generic | Notes | URL
4 | USED | JP1, JP3, JP4, JP7 | P | Harwin | M20-9994045 | 2.54mm header, vertical strip, 2 pos (1x40) | Digikey | 952-3307-ND | Y | 1x40 strip
1 | USED | JP2 | P | Harwin | M20-9994045 | 2.54mm header, vertical strip, 3 pos (1x40) | Digikey | 952-3307-ND | Y | 1x40 strip
1 | USED | JP5 | P | Harwin | M20-9994045 | 2.54mm header, vertical strip, 4 pos (1x40) | Digikey | 952-3307-ND | Y | 1x40 strip
1 | USED | C5 | P | Samsung | CL05C561JB5NNNC | C - 0402, 560p, C0G, 50V | Digikey | 1276-1709-1-ND | Y
- | - | C2, C3, C6, C7, C9 | DNP |  |  | C - 0603
2 | USED | C8, C10 | P | Samsung | CL10A105KA8NNNC | C - 0603, 1u, X5R, 25V | Digikey | 1276-1102-1-ND | Y
3 | USED | C1, C4, C7 | P | Samsung | CL10B223KA8NNNC | C - 0603, 22n, X7R, 25V | Digikey | 1276-1999-1-ND | Y
1 | USED | D3 | P | On Semi | BAS16XV2T1G | Diode, Gen Purp, 200mA, SOD523 | Digikey | BAS16XV2T1GOSCT-ND | Y
1 | USED | L2 | P | Coilcraft | 0402HP-18NXGL | L - 0402, 18n | Mouser | 994-0402HP-18NXGLU | N | U or W packaging
1 | USED | L1 | P | Coilcraft | 0402CS-3N9XGL | L - 0402, 3.9n | Mouser | 994-0402CS-3N9XGLW | N | U or W packaging
1 | USED | D1 | P | ROHM Semi. | SML-D13M8WT86 | LED - 0603, GREEN, Diffused | Digikey | ‎846-1198-1-ND‎ | Y
1 | USED | D2 | P | ROHM Semi. | SML-D12U8WT86‎ | LED - 0603, RED, Diffused | Digikey | 511-1580-1-ND‎ | Y
1 | USED | Q1 | P | Diodes Inc. | DMP2120U-7 | MOSFET, P-Chan, 20V, SOT23 | Digikey | DMP2120U-7DICT-ND | Y
1 | USED | U1 | P | Silicon Labs | SI4112-D-GM | PLL RF Synthesizer, single out, IF | Mouser | 634-SI4112-D-GM | N
- | - | R11 | DNP |  |  | R - 0402
1 | USED | JP6 | P | Stackpole | RMCF0402ZT0R00‎ | R - 0402, 0, jumper | Digikey | RMCF0402ZT0R00CT-ND‎ | N
5 | USED | R3, R4, R5, R6, R10 | P | Stackpole | RMCF0402FT47K0‎ | R - 0402, 47k, 1%, 100ppm | Digikey | ‎RMCF0402FT47K0CT-ND‎ | Y
- | - | R7, R8 | DNP |  |  | R - 0603
2 | USED | R2, R9 | P | Stackpole | RMCF0603ZT0R00‎ | R - 0603, 0, jumper | Digikey | RMCF0603ZT0R00CT-ND‎ | Y
2 | USED | R1, R12 | P | Stackpole | RMCF0603FT2K70‎ | R - 0603, 2.7k, 1%, 100ppm | Digikey | RMCF0603FT2K70CT-ND‎ | Y
2 | USED | J1, J3 | P | Cinch | 142-0701-851 | SMA Jack Conn, 50ohm, edge mount | Dig / Mou | J658-ND / 530-142-0701-851 | N
1 | USED | X1 | P | ECS | ECS-TXO-3225-160-TR | TCXO, 16.000 MHz, 3.3V, HCMOS, 2.5ppm | Mouser | 520-TXO-3225-16.0T | N
Revision History
Rev | Date | Notes
1 | 2019-09-25 | Initial BOM.
 | 2019-10-06 | Assembled 1x sythesizer-Si4112
 | 2019-12-06 | Assembled 1x sythesizer-Si4112

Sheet: synthesizer-RF-Si4123
Bill Of Materials
Source: synthesizer-RF-Si4123.sch |  |  | P/DNP = | Place/Do Not Place
Modified: 2019-08-01 |  |  | Generic = | Any generic part with the same characteristics
Revision: 1
Cnt | Status | Part References | P/DNP | Mfg | Mfg PN | Description | Distributor | Dist. PN | Generic | Notes | URL
3 | USED | JP1-4, 6 | P | Harwin | M20-9994045 | 2.54mm header, vertical strip, 2 pos (1x40) | Digikey | 952-3307-ND | Y | 1x40 strip
1 | USED | JP5 | P | Harwin | M20-9994045 | 2.54mm header, vertical strip, 4 pos (1x40) | Digikey | 952-3307-ND | Y | 1x40 strip
1 | USED | JP6 | P | Harwin | M20-1060200 | 2.54mm housing, 2 position | Digikey | 952-2227-ND | Y | only battery
1 | USED | JP5 | P | Harwin | M20-1060400 | 2.54mm housing, 4 position | Digikey | 952-2229-ND | Y
1 | USED | JP6 | P | MPD | SBH431-1AS | Battery holder, 3x AAA, cover, 6" leads, switch | Digikey | SBH431-1AS-ND | Y
2 | USED | C8, C9 | P | Samsung | CL05C561JB5NNNC | C - 0402, 560p, C0G, 50V | Digikey | 1276-1709-1-ND | Y
- | - | C1, C2, C5, C6, C11, C12, C16 | DNP |  |  | C - 0603
2 | USED | C10, C14 | P | Samsung | CL10A105KA8NNNC | C - 0603, 1u, X5R, 25V | Digikey | 1276-1102-1-ND | Y
3 | USED | C3, C4, C7 | P | Samsung | CL10B223KA8NNNC | C - 0603, 22n, X7R, 25V | Digikey | 1276-1999-1-ND | Y
1 | USED | C13 | P | Samsung | CL21A106KOQNNNG | C - 0805, 10u, X5R, 16V | Digikey | 1276-6455-1-ND | Y
1 | USED | L1 | P | Coilcraft | 0402CS-1N8XGL | L - 0402, 1.8n | Mouser | 994-0402CS-1N8XGLU | N | U or W packaging
1 | USED | L2 | P | Coilcraft | 0402HP-18NXGL | L - 0402, 18n | Mouser | 994-0402HP-18NXGLU | N | U or W packaging
1 | USED | L3 | P | Coilcraft | 0402CS-2N0XGL | L - 0402, 2.0n | Mouser | 994-0402CS-2N0XGLW | N | U or W packaging
1 | USED | L4 | P | Coilcraft | 0402HP-47NXGL | L - 0402, 47n | Mouser | 994-0402HP-47NXGLU | N | U or W packaging
1 | USED | U1 | P | TI | LP38692MP-3.3/NOPB | LDO Voltage Regulator, 1A, EN, 3.3V Fixed | Digikey | LP38692MP-3.3/NOPBCT-ND | N
1 | USED | D1 | P | ROHM Semi. | SML-D13M8WT86 | LED - 0603, GREEN, Diffused | Digikey | ‎846-1198-1-ND‎ | Y
1 | USED | D2 | P | ROHM Semi. | SML-D12U8WT86‎ | LED - 0603, RED, Diffused | Digikey | 511-1580-1-ND‎ | Y
1 | USED | U2 | P | Silicon Labs | SI4123-D-GM | PLL RF Synthesizer, dual out, RF1 & IF | Mouser | 634-SI4123-D-GM | N
2 | USED | R9, R10 | P | Stackpole | RMCF0402ZT0R00‎ | R - 0402, 0, jumper | Digikey | RMCF0402ZT0R00CT-ND‎ | N
4 | USED | R3, R4, R5, R6 | P | Stackpole | RMCF0402FT47K0‎ | R - 0402, 47k, 1%, 100ppm | Digikey | ‎RMCF0402FT47K0CT-ND‎ | Y
- | - | R7, R8 | DNP |  |  | R - 0603
4 | USED | R1, R2, R13, JMP1 | P | Stackpole | RMCF0603ZT0R00‎ | R - 0603, 0, jumper | Digikey | RMCF0603ZT0R00CT-ND‎ | Y | JMP1 can be 0805 too
2 | USED | R11, R12 | P | Stackpole | RMCF0603FT2K70‎ | R - 0603, 2.7k, 1%, 100ppm | Digikey | RMCF0603FT2K70CT-ND‎ | Y
2 | USED | J1, J2, J3 | P | Cinch | 142-0701-851 | SMA Jack Conn, 50ohm, edge mount | Dig / Mou | J658-ND / 530-142-0701-851 | N | J3 (ref-in) not required
6 | USED | JP5, JP6 | P | Harwin | M20-1160042 | Socket contact, gold, crimp, 22-30 AWG | Digikey | 952-2157-1-ND | Y
1 | USED | X1 | P | ECS | ECS-TXO-3225-160-TR | TCXO, 16.000 MHz, 3.3V, HCMOS, 2.5ppm | Mouser | 520-TXO-3225-16.0T | N
Revision History
Rev | Date | Notes
1 | 2019-08-01 | Initial BOM for 3x boards, excludes some connectors
2 | 2019-08-23 | Assembled 1x dual-synthesizer

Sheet: template
Bill Of Materials
Source: schematic-name.sch |  |  | P/DNP = | Place/Do Not Place
Modified: yyyy-mm-dd |  |  | Generic = | Any generic part with the same characteristics
Revision: 1
Cnt | Status | Part References | P/DNP | Mfg | Mfg PN | Description | Distributor | Dist. PN | Generic | Notes | URL
Revision History
Rev | Date | Notes
1 | yyyy-mm-dd | Initial BOM.

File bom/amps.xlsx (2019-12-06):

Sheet: amp-LNA-BFP740Fxxx
Bill Of Materials
Source: amp-LNA-BFP740Fxxx.sch |  |  | P/DNP = | Place/Do Not Place (DNP is for final production boards)
Modified: 2019-11-10 |  |  | Generic = | Any generic part with the same characteristics are OK (e.g., bypass cap)
Revision: 1
Cnt | Status | Part References | P/DNP | Mfg | Mfg PN | Description | Distributor | Dist. PN | Generic | Notes | URL
2 | USED | JP1, JP2 |  | Harwin | M20-9994045 | 2.54mm header, vertical strip, 2 pos, 1x40 (by x1) | Digikey | 952-3307-ND
1 | - | C6 | NP |  |  | C - 0402
2 | USED | C1, C2 |  | Samsung | CL05C220JB5NNNC‎ | C - 0402, 22p, C0G, 50V | Digikey | ‎1276-1116-1-ND
1 | - | C3 | NP |  |  | C - 0603
1 | USED | C5 |  | Samsung | CL10A105KA8NNNC | C - 0603, 1u, X5R, 25V | Digikey | 1276-1102-1-ND
2 | USED | C4, C8 |  | Samsung | CL10B473KB8NNNC | C - 0603, 47n, X7R, 50V | Digikey | 1276-1063-1-ND
1 | USED | L3 |  | Murata | LQW15 | L - 0402, 1.8n (around) |  |  |  | 2.0n used
1 | USED | L2 |  | Murata | LQW18AN10NG00D‎ | L - 0603, 10n, 650mA, 110mohm, +/-2% | Digikey | 490-6856-1-ND
1 | USED | L1 |  | Murata | LQW18AN47NG00D | L - 0603, 47n, 380mA, 290mohm, +/-2% | Digikey | 490-6894-1-ND |  | 91n used
1 | USED | D1 |  | ROHM Semi. | SML-D13M8WT86 | LED - 0603, GREEN, Diffused | Digikey | ‎846-1198-1-ND‎
1 | USED | Q2 |  | Infineon | BFP740FH6327XTSA1 | LNA, RF Transistor, NPN, 42GHz, TSFP4 | Digikey | BFP740FH6327XTSA1CT-ND
1 |  | Q1 | NP | Diodes Inc. | DMP2120U-7 | MOSFET, P-Chan, 20V, SOT23 | Digikey | DMP2120U-7DICT-ND |  | 0 ohm placed
1 |  | R3 | NP | Stackpole | RMCF0402FT47K0‎ | R - 0402, 47k, 1%, 100ppm | Digikey | ‎RMCF0402FT47K0CT-ND‎
1 | USED | R1 |  | Stackpole | RMCF0603FT1K50‎ | R - 0603, 1.5k, 1%, 100ppm | Digikey | ‎RMCF0603FT1K50CT-ND
1 | USED | R6 |  | Stackpole | RMCF0603FT220R | R - 0603, 220, 1%, 100ppm | Digikey | RMCF0603FT220RCT-ND
1 | USED | R5 |  | Stackpole | RMCF0603FT27R0 | R - 0603, 27, 1%, 100ppm | Digikey | RMCF0603FT27R0CT-ND
1 | USED | R4 |  | Stackpole | RMCF0603FT39R0 | R - 0603, 39, 1%, 100ppm | Digikey | RMCF0603FT39R0CT-ND
1 | USED | R2 |  | Stackpole | RMCF0603FT45K3 | R - 0603, 45.3k, 1%, 100ppm | Digikey | RMCF0603FT45K3CT-ND
2 | USED | J1, J2 |  | Cinch | 142-0701-851 | SMA Jack Conn, 50ohm, edge mount | Digikey/Mouser | J658-ND / 530-142-0701-851
Revision History
Rev | Date | Notes
1 | 2019-11-10 | Initial BOM.
 | 2019-11-18 | Assembled 1x LNA-BFP740F, 0603 jumper placed for Q1

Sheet: amp-LNA-BGB741L7ESD
Bill Of Materials
Source: amp-LNA-BGB741L7ESD.sch |  |  | P/DNP = | Place/Do Not Place (DNP is for final production boards)
Modified: 2019-09-28 |  |  | Generic = | Any generic part with the same characteristics are OK (e.g., bypass cap)
Revision: 1
Cnt | Status | Part References | P/DNP | Mfg | Mfg PN | Description | Distributor | Dist. PN | Generic | Notes | URL
3 | USED | JP1, JP2 | P | Harwin | M20-9994045 | 2.54mm header, vertical strip, 2 pos (1x40) | Digikey | 952-3307-ND | Y | 1x40 strip
4 | USED | C1, C2 | P | Samsung | CL05C220JB5NNNC‎ | C - 0402, 22p, C0G, 50V | Digikey | ‎1276-1116-1-ND | Y
- | - | C4 | DNP |  |  | C - 0603
2 | USED | C5 | P | Samsung | CL10A105KA8NNNC | C - 0603, 1u, X5R, 25V | Digikey | 1276-1102-1-ND | Y
4 | USED | C3, C6 | P | Samsung | CL10B473KB8NNNC | C - 0603, 47n, X7R, 50V | Digikey | 1276-1063-1-ND | Y
4 | USED | L1, L2 | P | Murata | LQW18AN27NG00D | L - 0603, 27n, 440mA, 210mohm, +/-2% | Digikey | 490-6879-1-ND | N
2 | USED | D1 | P | ROHM Semi. | SML-D13M8WT86 | LED - 0603, GREEN, Diffused | Digikey | ‎846-1198-1-ND‎ | Y
2 | USED | U1 | P | Infineon | BGB741L7ESDE6327XTSA1‎ | MMIC LNA, General purpose | Digikey | ‎BGB741L7ESDE6327XTSA1CT-ND | N
1 | USED | Q1 | P | Diodes Inc. | DMP2120U-7 | MOSFET, P-Chan, 20V, SOT23 | Digikey | DMP2120U-7DICT-ND | Y
1 | USED | R3 | P | Stackpole | RMCF0402FT47K0‎ | R - 0402, 47k, 1%, 100ppm | Digikey | ‎RMCF0402FT47K0CT-ND‎ | Y
3 | USED | R5 | P | Stackpole | RMCF0603ZT0R00‎ | R - 0603, 0, jumper | Digikey | RMCF0603ZT0R00CT-ND‎ | Y
2 | USED | R1 | P | Stackpole | RMCF0603FT1K50‎ | R - 0603, 1.5k, 1%, 100ppm | Digikey | ‎RMCF0603FT1K50CT-ND | Y
2 | USED | R2 | P | Stackpole | RMCF0603FT27K0‎ | R - 0603, 27k, 1%, 100ppm | Digikey | RMCF0603FT27K0CT-ND | Y
4 | USED | J1, J2 | P | Cinch | 142-0701-851 | SMA Jack Conn, 50ohm, edge mount | Digikey | J658-ND | N
Revision History
Rev | Date | Notes
1 | 2019-09-28 | Initial BOM.
 | 2019-10-19 | Assembled 1x board
 | 2019-11-13 | Assembled 1x board, 0603 jumper for Q1, NP R3, NP JP2

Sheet: amp-LNA-TQP3M9037
Bill Of Materials
Source: amp-LNA-TQP3M9037.sch |  |  | P/DNP = | Place/Do Not Place (DNP is for final production boards)
Modified: 2019-09-30 |  |  | Generic = | Any generic part with the same characteristics are OK (e.g., bypass cap)
Revision: 1
Cnt | Status | Part References | P/DNP | Mfg | Mfg PN | Description | Distributor | Dist. PN | Generic | Notes | URL
3 | USED | JP1, JP2 | P | Harwin | M20-9994045 | 2.54mm header, vertical strip, 2 pos (1x40) | Digikey | 952-3307-ND | Y | 1x40 strip
2 | USED | C1 | P | Samsung | CL05C220JB5NNNC‎ | C - 0402, 22p, C0G, 50V | Digikey | ‎1276-1116-1-ND | Y
2 | USED | C2 | P | Samsung | CL05C060CB5NNNC | C - 0402, 6.0p, C0G, 50V | Digikey | 1276-1607-1-ND | Y
- | - | C3, C5 | DNP |  |  | C - 0603
2 | USED | C6 | P | Samsung | CL10A105KA8NNNC | C - 0603, 1u, X5R, 25V | Digikey | 1276-1102-1-ND | Y
2 | USED | C4 | P | Samsung | CL10B473KB8NNNC | C - 0603, 47n, X7R, 50V | Digikey | 1276-1063-1-ND | Y
3 | USED | L1, L2 | P | Murata | LQW18AN10NG00D‎ | L - 0603, 10n, 650mA, 110mohm, +/-2% | Digikey | 490-6856-1-ND | N
2 | USED | D1 | P | ROHM Semi. | SML-D13M8WT86 | LED - 0603, GREEN, Diffused | Digikey | ‎846-1198-1-ND‎ | Y
2 | USED | U1 | P | Qorvo | TQP3M9037 | MMIC LNA, High performance | Mouser | 772-TQP3M9037 | N
- | - | R3, R4 | DNP |  |  | R - 0603
2 | USED | R2 | P | Stackpole | RMCF0603ZT0R00‎ | R - 0603, 0, jumper | Digikey | RMCF0603ZT0R00CT-ND‎ | Y
2 | USED | R1 | P | Stackpole | RMCF0603FT5K60 | R - 0603, 5.6k, 1%, 100ppm | Digikey | RMCF0603FT5K60CT-ND | Y
4 | USED | J1, J2 | P | Cinch | 142-0701-851 | SMA Jack Conn, 50ohm, edge mount | Digikey | J658-ND | N
Revision History
Rev | Date | Notes
1 | 2019-09-30 | Initial BOM. Input matching for NFmin and output matching for L and S band (wideband).
 | 2019-10-07 | Assembled 1x board for min NF
 | 2019-11-13 | Assembled 1x board, NP JP2, L1 placed for max gain

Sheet: template
Bill Of Materials
Source: schematic-name.sch |  |  | P/DNP = | Place/Do Not Place (DNP is for final production boards)
Modified: yyyy-mm-dd |  |  | Generic = | Any generic part with the same characteristics are OK (e.g., bypass cap)
Revision: 1
Cnt | Status | Part References | P/DNP | Mfg | Mfg PN | Description | Distributor | Dist. PN | Generic | Notes | URL
Revision History
Rev | Date | Notes
1 | yyyy-mm-dd | Initial BOM.

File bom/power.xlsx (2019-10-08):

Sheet: power-linear-LP38692-2.7V-adj
Bill Of Materials
Source: power-linear-LP38692.sch |  |  | P/DNP = | Place/Do Not Place
Modified: 2019-09-26 |  |  | Generic = | Any generic part with the same characteristics
Revision: 1
Cnt | Status | Part References | P/DNP | Mfg | Mfg PN | Description | Distributor | Dist. PN | Generic | Notes | URL
1 | USED | JP2 | P | Harwin | M20-9980645 | 2.54mm header, vertical strip, 12 pos (2x6) | Digikey | 952-2125-ND | Y
1 | USED | JP1 | P | Harwin | M20-9994045 | 2.54mm header, vertical strip, 2 pos (1x40) | Digikey | 952-3307-ND | Y | 1x40 strip
1 | USED | JP3 | P | Harwin | M20-9994045 | 2.54mm header, vertical strip, 3 pos (1x40) | Digikey | 952-3307-ND | Y | 1x40 strip
1 | USED | C1 | P | Samsung | CL21A106KOQNNNG | C - 0805, 10u, X5R, 16V | Digikey | 1276-6455-1-ND | Y
1 | USED | C2 | P | Samsung | CL31A226KOHNNNE | C - 1206, 22u, X5R, 16V | Digikey | 1276-3048-1-ND | Y
1 | USED | U1 | P | TI | LP38692MP-ADJ/NOPB | LDO Voltage Regulator, 1A, EN, Adjustable | Digikey | LP38692MP-ADJ/NOPBCT-ND | N
2 | USED | D1, D2 | P | ROHM Semi. | SML-D13M8WT86 | LED - 0603, GREEN, Diffused | Digikey | ‎846-1198-1-ND‎ | Y
- | - | R3, R4 | DNP |  |  | R - 0402
1 | USED | R6 | P | Yageo | RT0402BRD0711K8L‎ | R - 0402, 11.8k, 0.1%, 25ppm | Digikey | ‎YAG4166CT-ND‎ | Y | for Vadj
1 | USED | R5 | P | Yageo | RT0402BRD0713K7L‎ | R - 0402, 13.7k, 0.1%, 25ppm | Digikey | ‎YAG4172CT-ND | Y | for Vadj
1 | USED | R2 | P | Stackpole | RMCF0603FT1K50‎ | R - 0603, 1.5k, 1%, 100ppm | Digikey | ‎RMCF0603FT1K50CT-ND | Y
1 | USED | R1 | P | Stackpole | RMCF0603FT2K70‎ | R - 0603, 2.7k, 1%, 100ppm | Digikey | RMCF0603FT2K70CT-ND‎ | Y
Revision History
Rev | Date | Notes
1 | 2019-09-26 | Initial BOM.
 | 2019-10-02 | Assembled 1x board

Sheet: power-linear-LP38692-3.3V-fix
Bill Of Materials
Source: power-linear-LP38692.sch |  |  | P/DNP = | Place/Do Not Place
Modified: 2019-09-26 |  |  | Generic = | Any generic part with the same characteristics
Revision: 1
Cnt | Status | Part References | P/DNP | Mfg | Mfg PN | Description | Distributor | Dist. PN | Generic | Notes | URL
1 | USED | JP2 | P | Harwin | M20-9980645 | 2.54mm header, vertical strip, 12 pos (2x6) | Digikey | 952-2125-ND | Y
1 | USED | JP1 | P | Harwin | M20-9994045 | 2.54mm header, vertical strip, 2 pos (1x40) | Digikey | 952-3307-ND | Y | 1x40 strip
1 | USED | JP3 | P | Harwin | M20-9994045 | 2.54mm header, vertical strip, 3 pos (1x40) | Digikey | 952-3307-ND | Y | 1x40 strip
1 | USED | C1 | P | Samsung | CL21A106KOQNNNG | C - 0805, 10u, X5R, 16V | Digikey | 1276-6455-1-ND | Y
1 | USED | C2 | P | Samsung | CL31A226KOHNNNE | C - 1206, 22u, X5R, 16V | Digikey | 1276-3048-1-ND | Y
1 | USED | U1 | P | TI | LP38692MP-3.3/NOPB | LDO Voltage Regulator, 1A, EN, 3.3V Fixed | Digikey | LP38692MP-3.3/NOPBCT-ND | N
2 | USED | D1, D2 | P | ROHM Semi. | SML-D13M8WT86 | LED - 0603, GREEN, Diffused | Digikey | ‎846-1198-1-ND‎ | Y
- | - | R3, R4, R5, R6 | DNP |  |  | R - 0402
1 | USED | R2 | P | Stackpole | RMCF0603FT2K70‎ | R - 0603, 2.7k, 1%, 100ppm | Digikey | RMCF0603FT2K70CT-ND‎ | Y
1 | USED | R1 | P | Stackpole | RMCF0603FT5K60 | R - 0603, 5.6k, 1%, 100ppm | Digikey | RMCF0603FT5K60CT-ND | Y
Revision History
Rev | Date | Notes
1 | 2019-09-26 | Initial BOM.
 | 2019-10-02 | Assembled 1x board

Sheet: power-linear-LP38692-5.0V-fix
Bill Of Materials
Source: power-linear-LP38692.sch |  |  | P/DNP = | Place/Do Not Place
Modified: 2019-09-26 |  |  | Generic = | Any generic part with the same characteristics
Revision: 1
Cnt | Status | Part References | P/DNP | Mfg | Mfg PN | Description | Distributor | Dist. PN | Generic | Notes | URL
1 | USED | JP2 | P | Harwin | M20-9980645 | 2.54mm header, vertical strip, 12 pos (2x6) | Digikey | 952-2125-ND | Y
1 | USED | JP1 | P | Harwin | M20-9994045 | 2.54mm header, vertical strip, 2 pos (1x40) | Digikey | 952-3307-ND | Y | 1x40 strip
1 | USED | JP3 | P | Harwin | M20-9994045 | 2.54mm header, vertical strip, 3 pos (1x40) | Digikey | 952-3307-ND | Y | 1x40 strip
1 | USED | C1 | P | Samsung | CL21A106KOQNNNG | C - 0805, 10u, X5R, 16V | Digikey | 1276-6455-1-ND | Y
1 | USED | C2 | P | Samsung | CL31A226KOHNNNE | C - 1206, 22u, X5R, 16V | Digikey | 1276-3048-1-ND | Y
1 | USED | U1 | P | TI | LP38692MP-5.0/NOPB | LDO Voltage Regulator, 1A, EN, 5.0V Fixed | Digikey | ‎LP38692MP-5.0/NOPBCT-ND | N
2 | USED | D1, D2 | P | ROHM Semi. | SML-D13M8WT86 | LED - 0603, GREEN, Diffused | Digikey | ‎846-1198-1-ND‎ | Y
- | - | R3, R4, R5, R6 | DNP |  |  | R - 0402
1 | USED | R1 | P | Stackpole | RMCF0603FT10K0‎ | R - 0603, 10k, 1%, 100ppm | Digikey | ‎RMCF0603FT10K0CT-ND | Y
1 | USED | R2 | P | Stackpole | RMCF0603FT5K60 | R - 0603, 5.6k, 1%, 100ppm | Digikey | RMCF0603FT5K60CT-ND | Y
Revision History
Rev | Date | Notes
1 | 2019-09-26 | Initial BOM.
 | 2019-10-05 | Assembled 1x board

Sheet: power-switching-TPS62111-3.3V
Bill Of Materials
Source: power-switching-TPS6211x.sch |  |  | P/DNP = | Place/Do Not Place
Modified: 2019-09-26 |  |  | Generic = | Any generic part with the same characteristics
Revision: 1
Cnt | Status | Part References | P/DNP | Mfg | Mfg PN | Description | Distributor | Dist. PN | Generic | Notes | URL
1 | USED | JP2 | P | Harwin | M20-9980645 | 2.54mm header, vertical strip, 12 pos (2x6) | Digikey | 952-2125-ND | Y
1 | USED | JP1 | P | Harwin | M20-9994045 | 2.54mm header, vertical strip, 2 pos (1x40) | Digikey | 952-3307-ND | Y | 1x40 strip
2 | USED | JP3, JP4 | P | Harwin | M20-9994045 | 2.54mm header, vertical strip, 3 pos (1x40) | Digikey | 952-3307-ND | Y | 1x40 strip
1 | USED | U1 | P | TI | TPS62111RSAR | Buck Reg, 3.3V, 1.5A | Digikey | 296-37681-1-ND | Y
1 | USED | C2 | P | Samsung | CL10A105KA8NNNC | C - 0603, 1u, X5R, 25V | Digikey | 1276-1102-1-ND | Y
2 | USED | C1, C3 | P | Samsung | CL31A226KOHNNNE | C - 1206, 22u, X5R, 16V | Digikey | 1276-3048-1-ND | Y
1 | USED | L1 | P | ECS Inc. | ECS-MPI4040R4-6R8-R | L - 6.8u, 2.4A, 91mohm, smd | Digikey | XC2337CT-ND | N
2 | USED | D1, D2 | P | ROHM Semi. | SML-D13M8WT86 | LED - 0603, GREEN, Diffused | Digikey | ‎846-1198-1-ND‎ | Y
1 | USED | D3 | P | ROHM Semi. | SML-D12U8WT86‎ | LED - 0603, RED, Diffused | Digikey | 511-1580-1-ND‎ | Y
1 | USED | Q1 | P | Diodes Inc. | DMP2120U-7 | MOSFET, P-Chan, 20V, SOT23 | Digikey | DMP2120U-7DICT-ND | Y
- | - | R3, R4, R6 | DNP |  |  | R - 0402
1 | USED | R5 | P | Stackpole | RMCF0402ZT0R00‎ | R - 0402, 0, jumper | Digikey | RMCF0402ZT0R00CT-ND‎ | Y
1 | USED | R7 | P | Stackpole | RMCF0402FT47K0‎ | R - 0402, 47k, 1%, 100ppm | Digikey | ‎RMCF0402FT47K0CT-ND‎ | Y
2 | USED | R2, R8 | P | Stackpole | RMCF0603FT2K70‎ | R - 0603, 2.7k, 1%, 100ppm | Digikey | RMCF0603FT2K70CT-ND‎ | Y
1 | USED | R1 | P | Stackpole | RMCF0603FT5K60 | R - 0603, 5.6k, 1%, 100ppm | Digikey | RMCF0603FT5K60CT-ND | Y
Revision History
Rev | Date | Notes
1 | 2019-09-26 | Initial BOM.
 | 2019-10-04 | Assembled 1x board

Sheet: power-switching-TPS62112-5.0
Bill Of Materials
Source: power-switching-TPS6211x.sch |  |  | P/DNP = | Place/Do Not Place
Modified: 2019-09-26 |  |  | Generic = | Any generic part with the same characteristics
Revision: 1
Cnt | Status | Part References | P/DNP | Mfg | Mfg PN | Description | Distributor | Dist. PN | Generic | Notes | URL
1 | USED | JP2 | P | Harwin | M20-9980645 | 2.54mm header, vertical strip, 12 pos (2x6) | Digikey | 952-2125-ND | Y
1 | USED | JP1 | P | Harwin | M20-9994045 | 2.54mm header, vertical strip, 2 pos (1x40) | Digikey | 952-3307-ND | Y | 1x40 strip
2 | USED | JP3, JP4 | P | Harwin | M20-9994045 | 2.54mm header, vertical strip, 3 pos (1x40) | Digikey | 952-3307-ND | Y | 1x40 strip
1 | USED | U1 | P | TI | TPS62112RSAR | Buck Reg, 5.0V, 1.5A | Digikey | ‎296-39444-1-ND‎ | Y
1 | USED | C2 | P | Samsung | CL10A105KA8NNNC | C - 0603, 1u, X5R, 25V | Digikey | 1276-1102-1-ND | Y
2 | USED | C1, C3 | P | Samsung | CL31A226KOHNNNE | C - 1206, 22u, X5R, 16V | Digikey | 1276-3048-1-ND | Y
1 | USED | L1 | P | ECS Inc. | ECS-MPI4040R4-6R8-R | L - 6.8u, 2.4A, 91mohm, smd | Digikey | XC2337CT-ND | N
2 | USED | D1, D2 | P | ROHM Semi. | SML-D13M8WT86 | LED - 0603, GREEN, Diffused | Digikey | ‎846-1198-1-ND‎ | Y
1 | USED | D3 | P | ROHM Semi. | SML-D12U8WT86‎ | LED - 0603, RED, Diffused | Digikey | 511-1580-1-ND‎ | Y
1 | USED | Q1 | P | Diodes Inc. | DMP2120U-7 | MOSFET, P-Chan, 20V, SOT23 | Digikey | DMP2120U-7DICT-ND | Y
- | - | R3, R4, R6 | DNP |  |  | R - 0402
1 | USED | R5 | P | Stackpole | RMCF0402ZT0R00‎ | R - 0402, 0, jumper | Digikey | RMCF0402ZT0R00CT-ND‎ | Y
1 | USED | R7 | P | Stackpole | RMCF0402FT47K0‎ | R - 0402, 47k, 1%, 100ppm | Digikey | ‎RMCF0402FT47K0CT-ND‎ | Y
2 | USED | R2, R8 | P | Stackpole | RMCF0603FT5K60 | R - 0603, 5.6k, 1%, 100ppm | Digikey | RMCF0603FT5K60CT-ND | Y
1 | USED | R1 | P | Stackpole | RMCF0603FT10K0‎ | R - 0603, 10k, 1%, 100ppm | Digikey | ‎RMCF0603FT10K0CT-ND | Y
Revision History
Rev | Date | Notes
1 | 2019-09-26 | Initial BOM.
 | 2019-10-05 | Assembled 1x board

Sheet: template
Bill Of Materials
Source: schematic-name.sch |  |  | P/DNP = | Place/Do Not Place
Modified: yyyy-mm-dd |  |  | Generic = | Any generic part with the same characteristics
Revision: 1
Cnt | Status | Part References | P/DNP | Mfg | Mfg PN | Description | Distributor | Dist. PN | Generic | Notes | URL
Revision History
Rev | Date | Notes
1 | yyyy-mm-dd | Initial BOM.

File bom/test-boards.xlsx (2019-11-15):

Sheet: cal-thru-reflect-match-sma
Bill Of Materials
Source: calibration-thru-reflect-match-sma.sch |  |  | P/DNP = | Place/Do Not Place (DNP is for final production boards)
Modified: 2019-07-29 |  |  | Generic = | Any generic part with the same characteristics are OK (e.g., bypass cap)
Revision: 1
Cnt | Status | Part References | P/DNP | Mfg | Mfg PN | Description | Distributor | Dist. PN | Generic | Notes | URL
6 | USED | J1, J2, J3, J4 | P | Cinch | 142-0701-851 | SMA Jack Conn, 50ohm, edge mount | Digikey/Mouser | J658-ND / 530-142-0701-851 | N
2 | USED | R1, R2 | P | Yageo | RT0402BRD07100RL | R - 0402, 100, 0.1%, 25ppm | Digikey | YAG2301CT-ND | Y | Precision 100 ohm resistor
Revision History
Rev | Date | Notes
1 | 2019-11-09 | Assembled 1x all SMAs
 | 2019-11-09 | Assembled 1x only J2/3 SMAs, no R1/2

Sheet: microstrip-test-4-layer-sma
Bill Of Materials
Source: microstrip-test-4-layer-sma-xx-xx.sch |  |  | P/DNP = | Place/Do Not Place (DNP is for final production boards)
Modified: 2019-07-29 |  |  | Generic = | Any generic part with the same characteristics are OK (e.g., bypass cap)
Revision: 1
Cnt | Status | Part References | P/DNP | Mfg | Mfg PN | Description | Distributor | Dist. PN | Generic | Notes | URL
8 | USED | J1, J2 | P | Cinch | 142-0701-851 | SMA Jack Conn, 50ohm, edge mount | Digikey/Mouser | J658-ND / 530-142-0701-851 | N
Revision History
Rev | Date | Notes
1 | 2019-07-29 | Initial BOM. Assembled 2x boards for 34-40
 | 2019-10-04 | Assembled 2x boards for 36-38

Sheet: template
Bill Of Materials
Source: schematic-name.sch |  |  | P/DNP = | Place/Do Not Place (DNP is for final production boards)
Modified: yyyy-mm-dd |  |  | Generic = | Any generic part with the same characteristics are OK (e.g., bypass cap)
Revision: 1
Cnt | Status | Part References | P/DNP | Mfg | Mfg PN | Description | Distributor | Dist. PN | Generic | Notes | URL
Revision History
Rev | Date | Notes
1 | yyyy-mm-dd | Initial BOM.

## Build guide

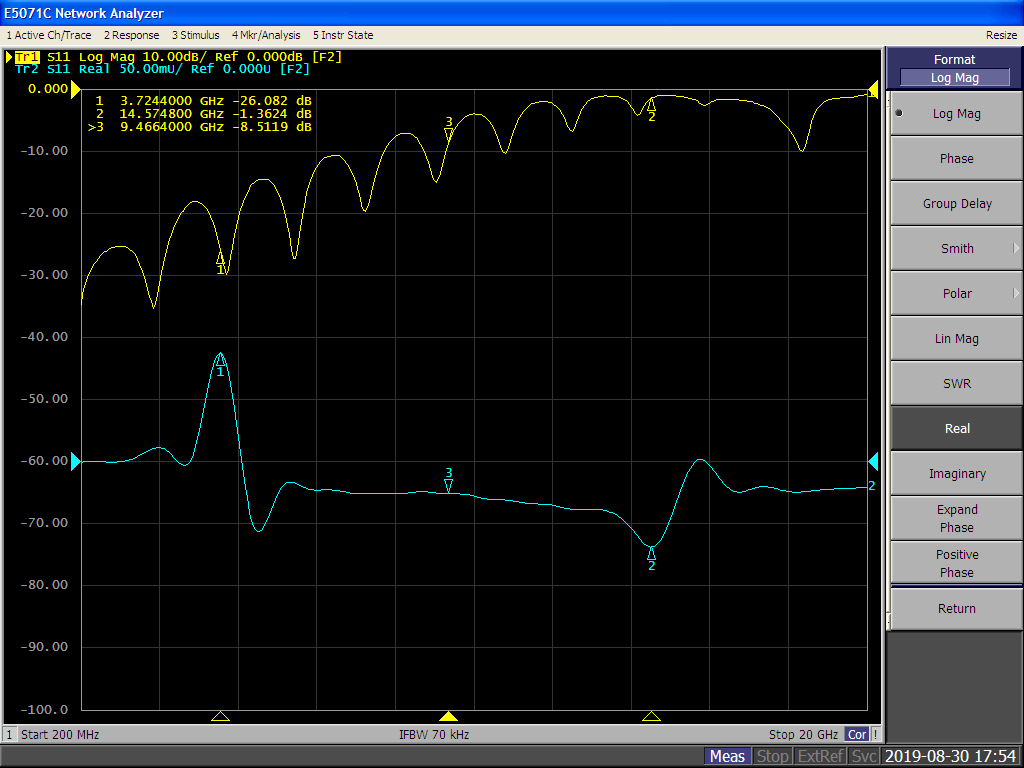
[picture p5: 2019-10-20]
measurements/microstrips/2019-08-30_E5071C-ENA/microstrip_0.40_TDR_STEP.PNG

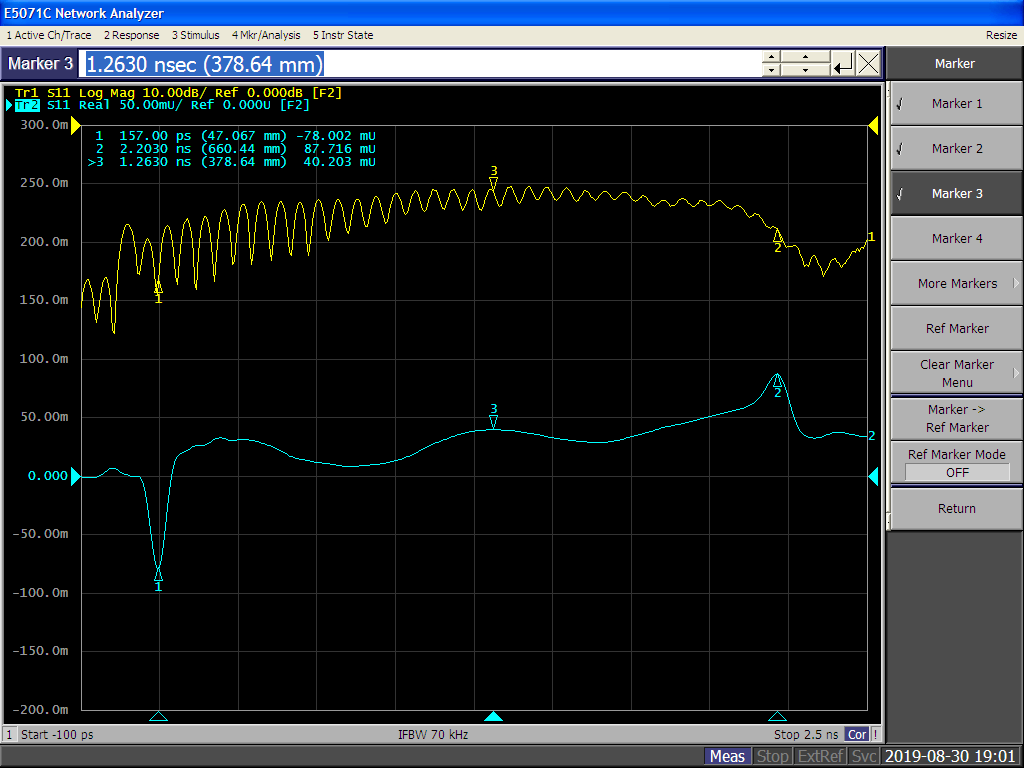
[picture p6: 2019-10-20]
measurements/microstrips/2019-08-30_E5071C-ENA/backplane_2-20_0.38_TDR_STEP.PNG

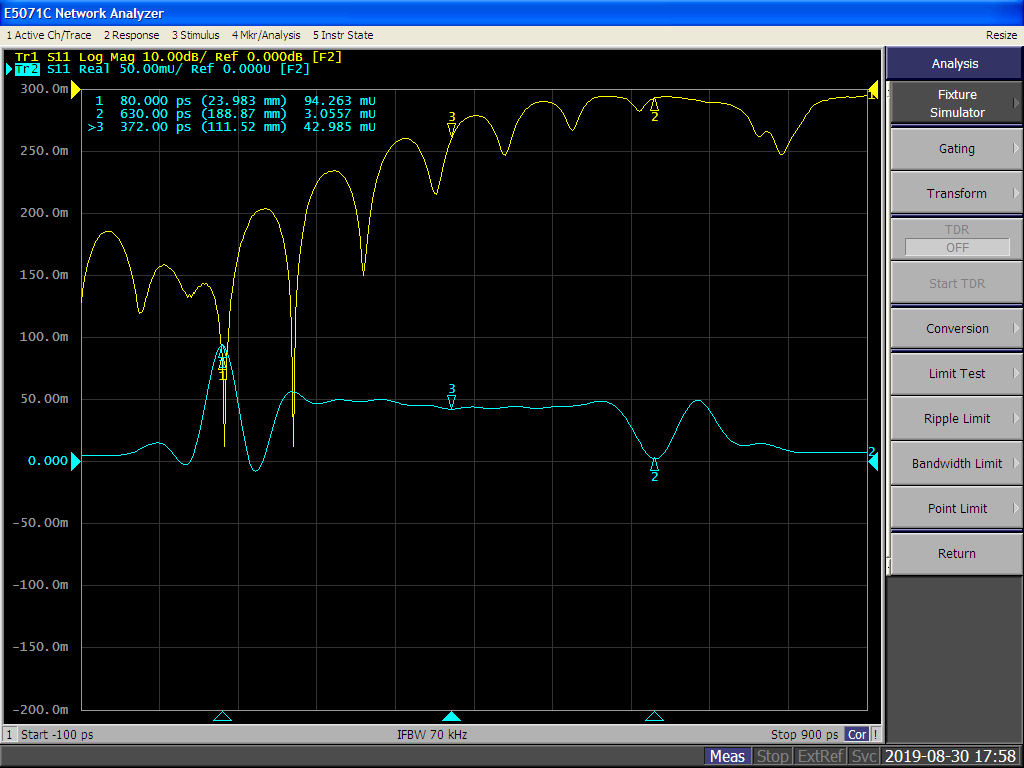
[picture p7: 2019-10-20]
measurements/microstrips/2019-08-30_E5071C-ENA/microstrip_0.34_TDR_STEP.PNG

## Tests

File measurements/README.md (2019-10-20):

## Measurements of Evaluation Boards

### [microstrips](microstrips)
Microstrip evaluation boards to determine the 50 ohm microstrip width using OSH Park's 4-layer stackup.

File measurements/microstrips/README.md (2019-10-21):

## Microstrip Boards

Microstrip evaluation boards to determine the 50 ohm microstrip width using OSH Park's 4-layer stackup for sub 3 GHz use.  Four 50 mm long microstrip boards with end-launch SMA connectors were designed; 0.34, 0.36, 0.38, and 0.40 mm widths.  The calculated 50 ohm width should be around 0.34 mm, however, the measured 50 ohm width is around 0.38 mm.  Phase velocity and effecitve permittivity was also measured using a very long microstrip on [OreSat's backplane](https://github.com/oresat/oresat-backplane).

### [EAGLE CAD Files](../../eagle/test/)
Four varying widths on two physical boards.  Two variations on each board; top and bottom.  OSH Park always ships a minimum of 3 boards per design.

    oresat-c3-rf/eagle/test/
      microstrip-test-4-layer-sma-34-40
      microstrip-test-4-layer-sma-36-38

### [2019-10-19 E5071C-ENA](2019-10-19_E5071C-ENA)
Measure and determine correct microstrip width for 50 ohm impedance on OSH Park's 4-layer stackup operating below 3 GHz.  Four 50 mm long microstrip test boards were measured; 0.34, 0.36, 0.38, and 0.40 mm.

### [2019-08-30 E5071C-ENA](2019-08-30_E5071C-ENA)
Measure and determine correct microstrip width for 50 ohm impedance on OSH Park's 4-layer stackup operating below 3 GHz.  Two 50 mm long microstrip test boards were measured with 0.34, and 0.40 mm widths, and a 180 mm long 0.38 mm width.  Phase velocity was also measured and effective permittivity was calculated by inducing discontinuties across the 180 mm long microstrip.

### References
- [OSH Park 4-layer stackup](https://docs.oshpark.com/services/four-layer/)

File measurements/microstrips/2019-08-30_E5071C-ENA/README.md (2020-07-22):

## 2019-08-30 E5071C-ENA
Measure and determine correct microstrip width for 50 ohm impedance on OSH Park's 4-layer stackup operating below 3 GHz.  Two 50 mm long microstrip test boards were measured with 0.34, and 0.40 mm widths, and a 180 mm long 0.38 mm width.  Phase velocity was also measured and effective permittivity was calculated by inducing discontinuties across the 180 mm long microstrip.

---

### Procedure

    1) Measure S11 and S21 for each board
    2) Analyze TDR from transformed S11
    3) Measure phase velocity and calculate effective permittivity

#### Equipment

    DUTs:
      - 50 mm long microstrip test boards; 0.34, 0.36, 0.38, and 0.40 mm widths
      - 180 mm long, 0.38 mm wide microstrip on OreSat's backplane
    VNA: Agilent E5071C ENA

#### Sweep Setup

    Start: 200 MHz
    Stop: 20 GHz
    Points: 401

#### Calibration

    Type: Full 2-port (open, short, load, thru)
    Kit:

#### TDR Setup
Simulated TDR based on the frequency domain transformation to time domain.  Time-domain reflectometry (TDR) uses input return loss scattering parameters (S11) in real format.

    Type: Low-pass mode
    Response: Step
    Window: Normal

#### Phase Velocity
The phase velocity of the microstrip can be calculated by using TDR to measure the time difference between two known discontinuties, and the physical difference distance.  From phase velocity the effective permittivity can be calculated.

    v_p = Δl / Δt = c / sqrt(ε_eff)
    ε_eff = ( Δt * c / Δl )^2

---

### Results

#### Impedance
- [TDR screen shot comparison](microstrips_TDR_compare.pdf)

#### Phase Velocity

The very long 0.38 mm wide microstrip on the backplane was used to measure the phase velocity.  Pieces of copper wire where placed over the microstrip to induce two known discontinuties.  While monitoring the TDR in real-time and pressing lightly on the copper pieces, markers were placed precisely on the induced discontinuties.

    Δl = 145.15 mm (avg)
    Δt = 795.5 ps

    v_p = 182.5e6 m/s
    ε_eff = 2.700

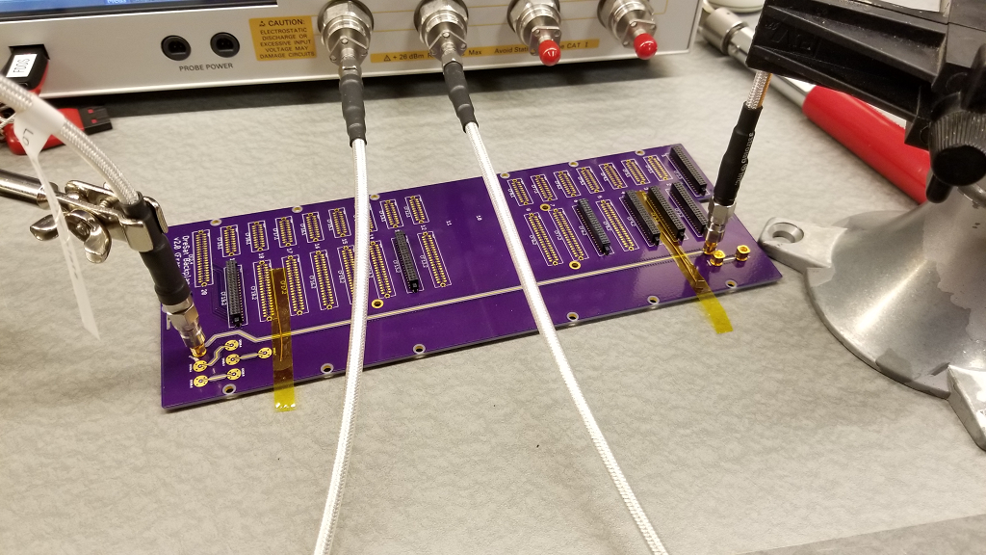
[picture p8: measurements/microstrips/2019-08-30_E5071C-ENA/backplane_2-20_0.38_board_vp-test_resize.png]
Backplane with discontinuties

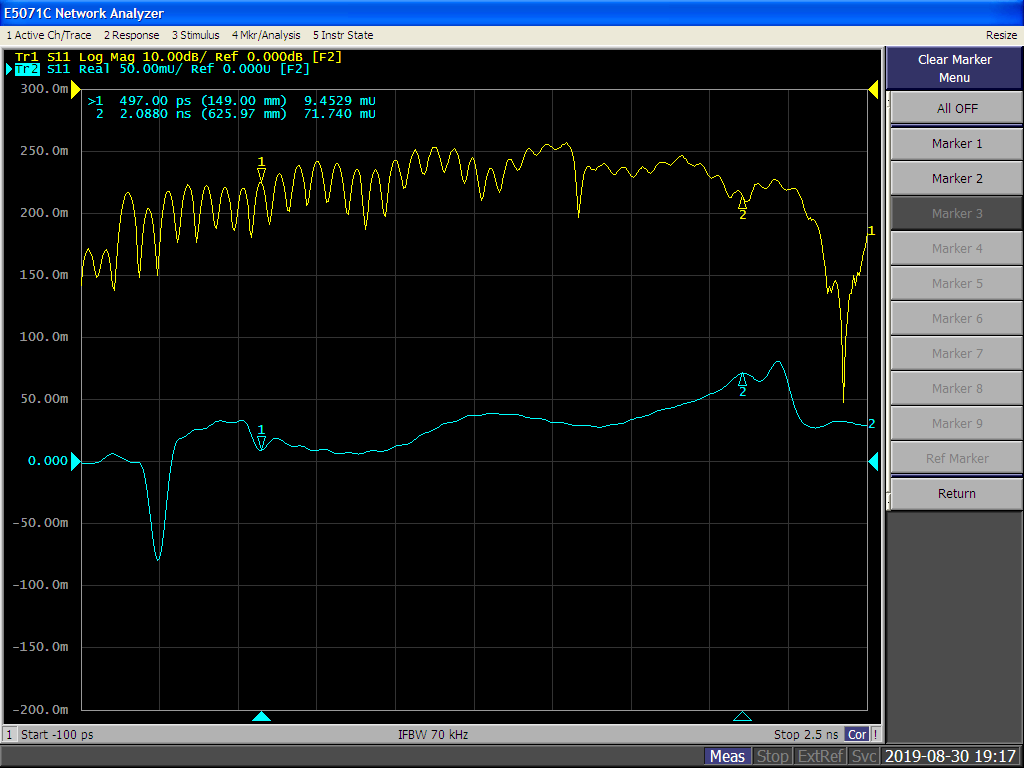
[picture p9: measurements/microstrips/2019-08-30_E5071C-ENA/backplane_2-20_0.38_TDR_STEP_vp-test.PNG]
TDR of backplane with discontinuties


---

### Conclusion
The correct 50 ohm microstrip impedance may be 0.38 mm for below 3 GHz operation on OSH Park's 4-layer stackup.  The phase velocity of a 0.38 mm wide microstrip is 182.5e6 m/s, and the effective permittivity is 2.700.

---

### Reference
- [Agilent E5071C Manual](http://ena.support.keysight.com/e5071c/manuals/webhelp/eng/index.htm)

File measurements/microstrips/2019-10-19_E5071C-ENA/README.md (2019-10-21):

## 2019-10-19 E5071C-ENA
Measure and determine correct microstrip width for 50 ohm impedance on OSH Park's 4-layer stackup operating below 3 GHz.  Four 50 mm long microstrip test boards were measured; 0.34, 0.36, 0.38, and 0.40 mm.

---

### Procedure

    1) Measure S11 and S21 for each board
    2) Analyze TDR from transformed S11

#### Equipment

    DUTs: 50 mm long microstrip test boards; 0.34, 0.36, 0.38, and 0.40 mm widths
    VNA: Agilent E5071C ENA

#### Sweep Setup

    Start: 200 MHz
    Stop: 20 GHz
    Points: 401

#### Calibration

    Type: Full 2-port (open, short, load, thru)
    Kit:

#### TDR Setup
Simulated TDR based on the frequency domain transformation to time domain.  Time-domain reflectometry (TDR) uses input return loss scattering parameters (S11) in real format.

    Type: Low-pass mode
    Response: Step
    Window: Normal

---

### Results
- [ADS schematic of imported S parameter data](microstrips_schematic.pdf)
- [S11 and S21, 200 MHz to 20 GHz](microstrips_S11_S21_200M-20G.pdf)
- [S11 and S21, 400 MHz to 4 GHz](microstrips_S11_S21_400M-4G.pdf)
- [TDR screen shot comparison](microstrips_TDR_compare.pdf)

---

### Conclusion
The correct 50 ohm microstrip impedance is 0.38 mm for below 3 GHz operation on OSH Park's 4-layer stackup.

---

### Reference
- [Agilent E5071C Manual](http://ena.support.keysight.com/e5071c/manuals/webhelp/eng/index.htm)

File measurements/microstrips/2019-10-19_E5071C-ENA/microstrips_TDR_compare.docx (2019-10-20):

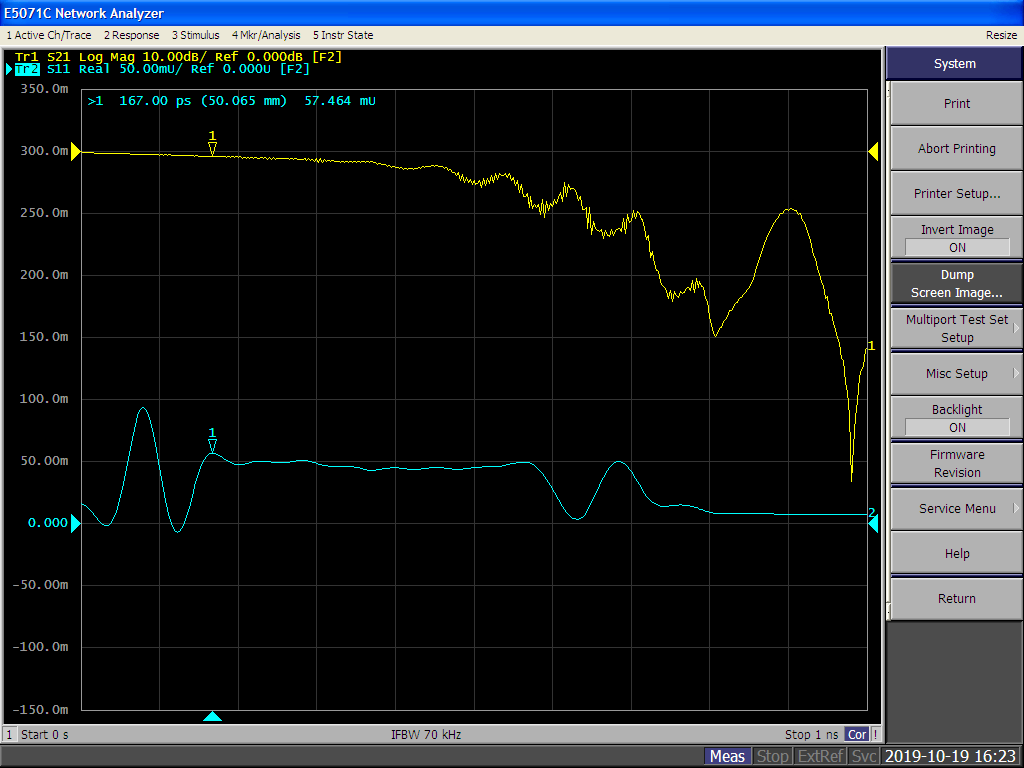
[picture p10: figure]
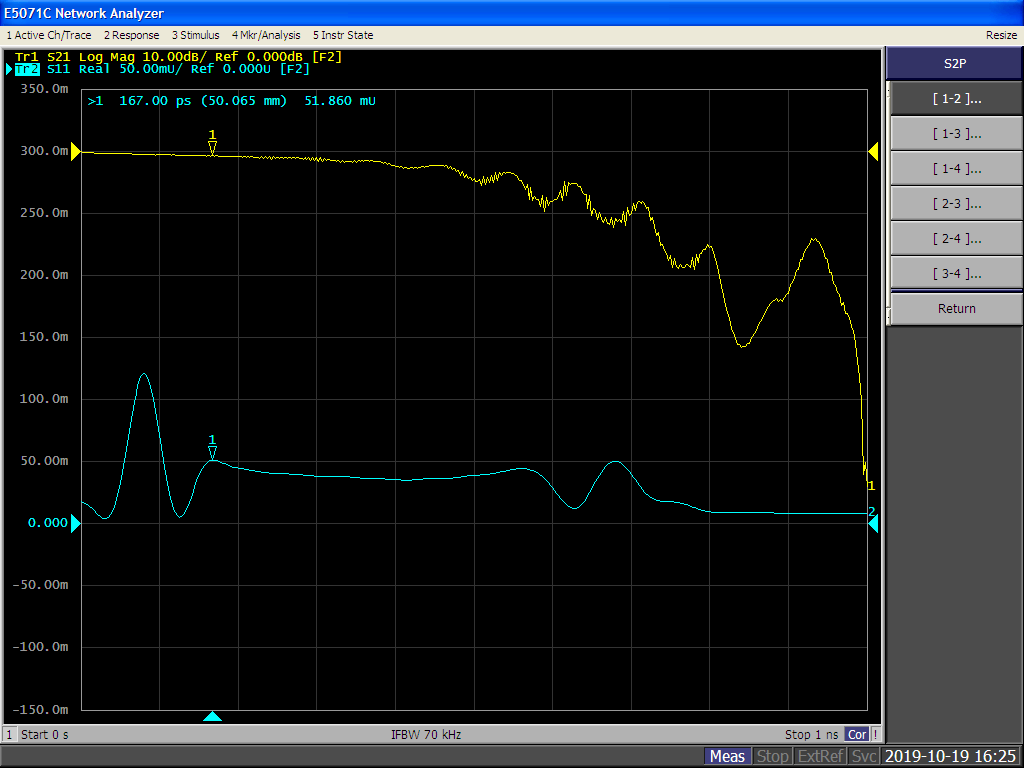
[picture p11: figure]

0.36 mm

0.34 mm

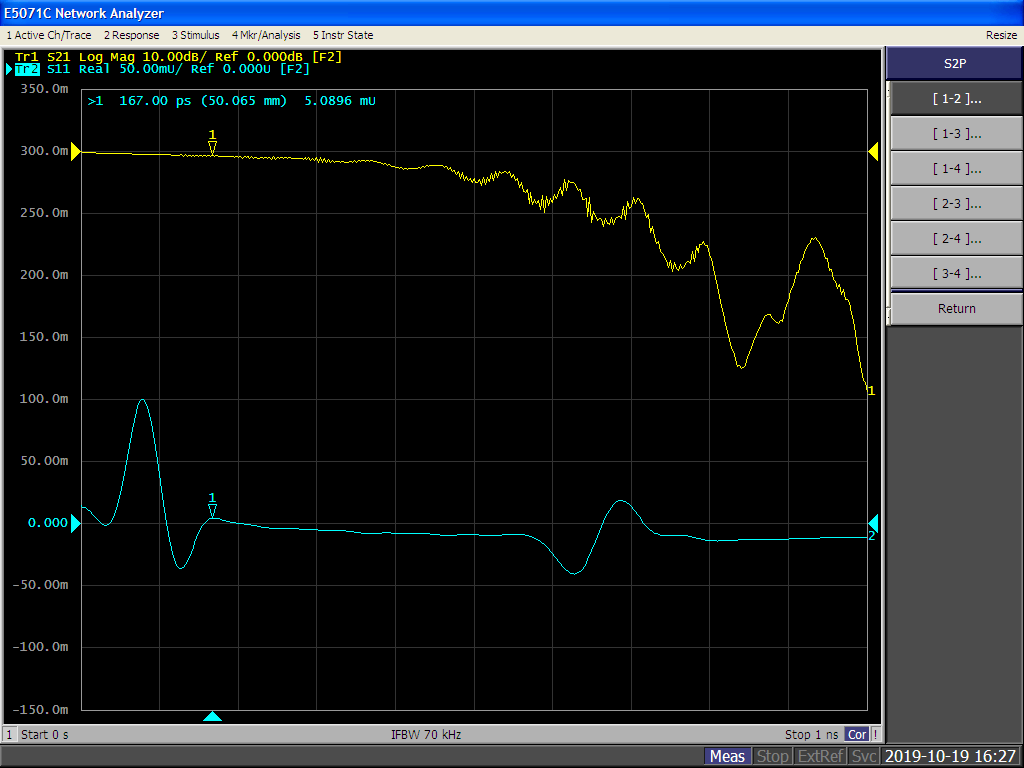
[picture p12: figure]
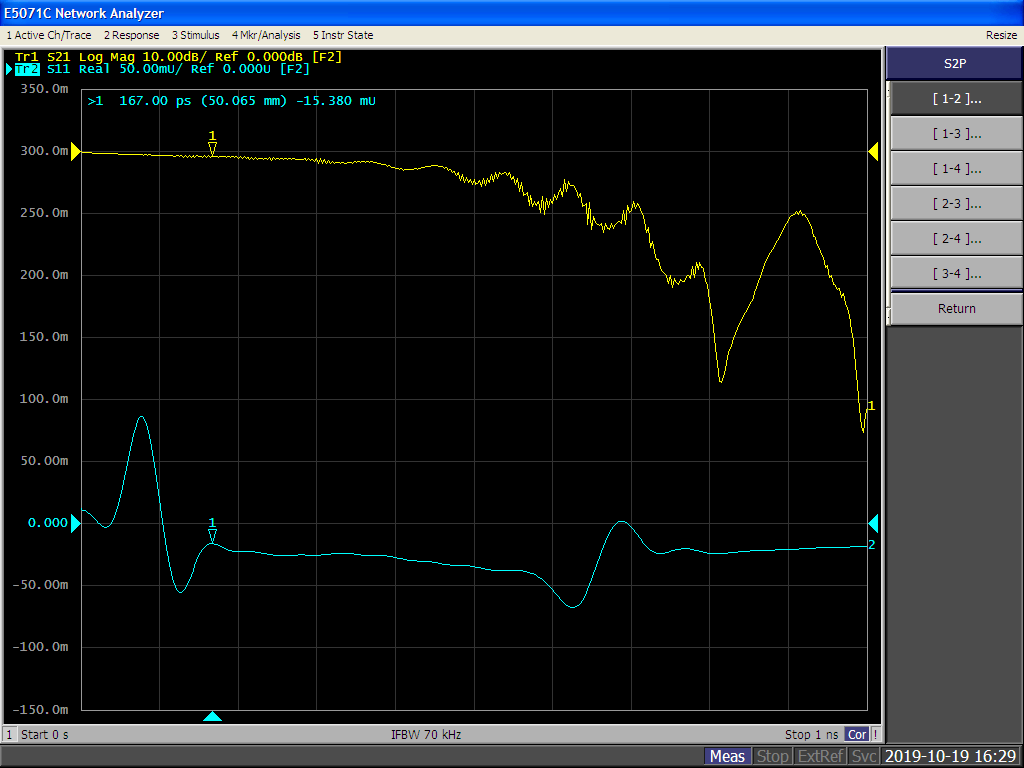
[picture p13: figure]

0.40 mm

0.38 mm


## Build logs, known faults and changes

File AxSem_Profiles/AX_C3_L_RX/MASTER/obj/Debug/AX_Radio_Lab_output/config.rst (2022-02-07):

                                      1 ;--------------------------------------------------------
                                      2 ; File Created by SDCC : free open source ANSI-C Compiler
                                      3 ; Version 3.6.0 #9615 (MINGW64)
                                      4 ;--------------------------------------------------------
                                      5 	.module config
                                      6 	.optsdcc -mmcs51 --model-small
                                      7 	
                                      8 ;--------------------------------------------------------
                                      9 ; Public variables in this module
                                     10 ;--------------------------------------------------------
                                     11 	.globl _axradio_fxtal
                                     12 	.globl _axradio_lposckfiltmax
                                     13 	.globl _axradio_sync_slave_rxtimeout
                                     14 	.globl _axradio_sync_slave_rxwindow
                                     15 	.globl _axradio_sync_slave_rxadvance
                                     16 	.globl _axradio_sync_slave_nrrx
                                     17 	.globl _axradio_sync_slave_resyncloss
                                     18 	.globl _axradio_sync_slave_maxperiod
                                     19 	.globl _axradio_sync_slave_syncpause
                                     20 	.globl _axradio_sync_slave_initialsyncwindow
                                     21 	.globl _axradio_sync_slave_syncwindow
                                     22 	.globl _axradio_sync_xoscstartup
                                     23 	.globl _axradio_sync_period
                                     24 	.globl _axradio_wor_period
                                     25 	.globl _axradio_framing_minpayloadlen
                                     26 	.globl _axradio_framing_ack_seqnrpos
                                     27 	.globl _axradio_framing_ack_retransmissions
                                     28 	.globl _axradio_framing_ack_delay
                                     29 	.globl _axradio_framing_ack_timeout
                                     30 	.globl _axradio_framing_enable_sfdcallback
                                     31 	.globl _axradio_framing_syncflags
                                     32 	.globl _axradio_framing_syncword
                                     33 	.globl _axradio_framing_synclen
                                     34 	.globl _axradio_framing_swcrclen
                                     35 	.globl _axradio_framing_lenmask
                                     36 	.globl _axradio_framing_lenoffs
                                     37 	.globl _axradio_framing_lenpos
                                     38 	.globl _axradio_framing_sourceaddrpos
                                     39 	.globl _axradio_framing_destaddrpos
                                     40 	.globl _axradio_framing_addrlen
                                     41 	.globl _axradio_framing_maclen
                                     42 	.globl _axradio_phy_preamble_appendpattern
                                     43 	.globl _axradio_phy_preamble_appendbits
                                     44 	.globl _axradio_phy_preamble_flags
                                     45 	.globl _axradio_phy_preamble_byte
                                     46 	.globl _axradio_phy_preamble_len
                                     47 	.globl _axradio_phy_preamble_longlen
                                     48 	.globl _axradio_phy_preamble_wor_len
                                     49 	.globl _axradio_phy_preamble_wor_longlen
                                     50 	.globl _axradio_phy_lbt_forcetx
                                     51 	.globl _axradio_phy_lbt_retries
                                     52 	.globl _axradio_phy_cs_enabled
                                     53 	.globl _axradio_phy_cs_period
                                     54 	.globl _axradio_phy_channelbusy
                                     55 	.globl _axradio_phy_rssireference
                                     56 	.globl _axradio_phy_rssioffset
                                     57 	.globl _axradio_phy_maxfreqoffset
                                     58 	.globl _axradio_phy_vcocalib
                                     59 	.globl _axradio_phy_chanvcoiinit
                                     60 	.globl _axradio_phy_chanpllrnginit
                                     61 	.globl _axradio_phy_chanfreq
                                     62 	.globl _axradio_phy_nrchannels
                                     63 	.globl _axradio_phy_pn9
                                     64 	.globl _axradio_phy_innerfreqloop
                                     65 	.globl _axradio_byteconv_buffer
                                     66 	.globl _axradio_byteconv
                                     67 	.globl _crc_ccitt
                                     68 	.globl _PORTC_7
                                     69 	.globl _PORTC_6
                                     70 	.globl _PORTC_5
                                     71 	.globl _PORTC_4
                                     72 	.globl _PORTC_3
                                     73 	.globl _PORTC_2
                                     74 	.globl _PORTC_1
                                     75 	.globl _PORTC_0
                                     76 	.globl _PORTB_7
                                     77 	.globl _PORTB_6
                                     78 	.globl _PORTB_5
                                     79 	.globl _PORTB_4
                                     80 	.globl _PORTB_3
                                     81 	.globl _PORTB_2
                                     82 	.globl _PORTB_1
                                     83 	.globl _PORTB_0
                                     84 	.globl _PORTA_7
                                     85 	.globl _PORTA_6
                                     86 	.globl _PORTA_5
                                     87 	.globl _PORTA_4
                                     88 	.globl _PORTA_3
                                     89 	.globl _PORTA_2
                                     90 	.globl _PORTA_1
                                     91 	.globl _PORTA_0
                                     92 	.globl _PINC_7
                                     93 	.globl _PINC_6
                                     94 	.globl _PINC_5
                                     95 	.globl _PINC_4
                                     96 	.globl _PINC_3
                                     97 	.globl _PINC_2
                                     98 	.globl _PINC_1
                                     99 	.globl _PINC_0
                                    100 	.globl _PINB_7
                                    101 	.globl _PINB_6
                                    102 	.globl _PINB_5
                                    103 	.globl _PINB_4
                                    104 	.globl _PINB_3
                                    105 	.globl _PINB_2
                                    106 	.globl _PINB_1
                                    107 	.globl _PINB_0
                                    108 	.globl _PINA_7
                                    109 	.globl _PINA_6
                                    110 	.globl _PINA_5
                                    111 	.globl _PINA_4
                                    112 	.globl _PINA_3
                                    113 	.globl _PINA_2
                                    114 	.globl _PINA_1
                                    115 	.globl _PINA_0
                                    116 	.globl _CY
                                    117 	.globl _AC
                                    118 	.globl _F0
                                    119 	.globl _RS1
                                    120 	.globl _RS0
                                    121 	.globl _OV
                                    122 	.globl _F1
                                    123 	.globl _P
                                    124 	.globl _IP_7
                                    125 	.globl _IP_6
                                    126 	.globl _IP_5
                                    127 	.globl _IP_4
                                    128 	.globl _IP_3
                                    129 	.globl _IP_2
                                    130 	.globl _IP_1
                                    131 	.globl _IP_0
                                    132 	.globl _EA
                                    133 	.globl _IE_7
                                    134 	.globl _IE_6
                                    135 	.globl _IE_5
                                    136 	.globl _IE_4
                                    137 	.globl _IE_3
                                    138 	.globl _IE_2
                                    139 	.globl _IE_1
                                    140 	.globl _IE_0
                                    141 	.globl _EIP_7
                                    142 	.globl _EIP_6
                                    143 	.globl _EIP_5
                                    144 	.globl _EIP_4
                                    145 	.globl _EIP_3
                                    146 	.globl _EIP_2
                                    147 	.globl _EIP_1
                                    148 	.globl _EIP_0
                                    149 	.globl _EIE_7
                                    150 	.globl _EIE_6
                                    151 	.globl _EIE_5
                                    152 	.globl _EIE_4
                                    153 	.globl _EIE_3
                                    154 	.globl _EIE_2
                                    155 	.globl _EIE_1
                                    156 	.globl _EIE_0
                                    157 	.globl _E2IP_7
                                    158 	.globl _E2IP_6
                                    159 	.globl _E2IP_5
                                    160 	.globl _E2IP_4
                                    161 	.globl _E2IP_3
                                    162 	.globl _E2IP_2
                                    163 	.globl _E2IP_1
                                    164 	.globl _E2IP_0
                                    165 	.globl _E2IE_7
                                    166 	.globl _E2IE_6
                                    167 	.globl _E2IE_5
                                    168 	.globl _E2IE_4
                                    169 	.globl _E2IE_3
                                    170 	.globl _E2IE_2
                                    171 	.globl _E2IE_1
                                    172 	.globl _E2IE_0
                                    173 	.globl _B_7
                                    174 	.globl _B_6
                                    175 	.globl _B_5
                                    176 	.globl _B_4
                                    177 	.globl _B_3
                                    178 	.globl _B_2
                                    179 	.globl _B_1
                                    180 	.globl _B_0
                                    181 	.globl _ACC_7
                                    182 	.globl _ACC_6
                                    183 	.globl _ACC_5
                                    184 	.globl _ACC_4
                                    185 	.globl _ACC_3
                                    186 	.globl _ACC_2
                                    187 	.globl _ACC_1
                                    188 	.globl _ACC_0
                                    189 	.globl _WTSTAT
                                    190 	.globl _WTIRQEN
                                    191 	.globl _WTEVTD
                                    192 	.globl _WTEVTD1
                                    193 	.globl _WTEVTD0
                                    194 	.globl _WTEVTC
                                    195 	.globl _WTEVTC1
                                    196 	.globl _WTEVTC0
                                    197 	.globl _WTEVTB
                                    198 	.globl _WTEVTB1
                                    199 	.globl _WTEVTB0
                                    200 	.globl _WTEVTA
                                    201 	.globl _WTEVTA1
                                    202 	.globl _WTEVTA0
                                    203 	.globl _WTCNTR1
                                    204 	.globl _WTCNTB
                                    205 	.globl _WTCNTB1
                                    206 	.globl _WTCNTB0
                                    207 	.globl _WTCNTA
                                    208 	.globl _WTCNTA1
                                    209 	.globl _WTCNTA0
                                    210 	.globl _WTCFGB
                                    211 	.globl _WTCFGA
                                    212 	.globl _WDTRESET
                                    213 	.globl _WDTCFG
                                    214 	.globl _U1STATUS
                                    215 	.globl _U1SHREG
                                    216 	.globl _U1MODE
                                    217 	.globl _U1CTRL
                                    218 	.globl _U0STATUS
                                    219 	.globl _U0SHREG
                                    220 	.globl _U0MODE
                                    221 	.globl _U0CTRL
                                    222 	.globl _T2STATUS
                                    223 	.globl _T2PERIOD
                                    224 	.globl _T2PERIOD1
                                    225 	.globl _T2PERIOD0
                                    226 	.globl _T2MODE
                                    227 	.globl _T2CNT
                                    228 	.globl _T2CNT1
                                    229 	.globl _T2CNT0
                                    230 	.globl _T2CLKSRC
                                    231 	.globl _T1STATUS
                                    232 	.globl _T1PERIOD
                                    233 	.globl _T1PERIOD1
                                    234 	.globl _T1PERIOD0
                                    235 	.globl _T1MODE
                                    236 	.globl _T1CNT
                                    237 	.globl _T1CNT1
                                    238 	.globl _T1CNT0
                                    239 	.globl _T1CLKSRC
                                    240 	.globl _T0STATUS
                                    241 	.globl _T0PERIOD
                                    242 	.globl _T0PERIOD1
                                    243 	.globl _T0PERIOD0
                                    244 	.globl _T0MODE
                                    245 	.globl _T0CNT
                                    246 	.globl _T0CNT1
                                    247 	.globl _T0CNT0
                                    248 	.globl _T0CLKSRC
                                    249 	.globl _SPSTATUS
                                    250 	.globl _SPSHREG
                                    251 	.globl _SPMODE
                                    252 	.globl _SPCLKSRC
                                    253 	.globl _RADIOSTAT
                                    254 	.globl _RADIOSTAT1
                                    255 	.globl _RADIOSTAT0
                                    256 	.globl _RADIODATA
                                    257 	.globl _RADIODATA3
                                    258 	.globl _RADIODATA2
                                    259 	.globl _RADIODATA1
                                    260 	.globl _RADIODATA0
                                    261 	.globl _RADIOADDR
                                    262 	.globl _RADIOADDR1
                                    263 	.globl _RADIOADDR0
                                    264 	.globl _RADIOACC
                                    265 	.globl _OC1STATUS
                                    266 	.globl _OC1PIN
                                    267 	.globl _OC1MODE
                                    268 	.globl _OC1COMP
                                    269 	.globl _OC1COMP1
                                    270 	.globl _OC1COMP0
                                    271 	.globl _OC0STATUS
                                    272 	.globl _OC0PIN
                                    273 	.globl _OC0MODE
                                    274 	.globl _OC0COMP
                                    275 	.globl _OC0COMP1
                                    276 	.globl _OC0COMP0
                                    277 	.globl _NVSTATUS
                                    278 	.globl _NVKEY
                                    279 	.globl _NVDATA
                                    280 	.globl _NVDATA1
                                    281 	.globl _NVDATA0
                                    282 	.globl _NVADDR
                                    283 	.globl _NVADDR1
                                    284 	.globl _NVADDR0
                                    285 	.globl _IC1STATUS
                                    286 	.globl _IC1MODE
                                    287 	.globl _IC1CAPT
                                    288 	.globl _IC1CAPT1
                                    289 	.globl _IC1CAPT0
                                    290 	.globl _IC0STATUS
                                    291 	.globl _IC0MODE
                                    292 	.globl _IC0CAPT
                                    293 	.globl _IC0CAPT1
                                    294 	.globl _IC0CAPT0
                                    295 	.globl _PORTR
                                    296 	.globl _PORTC
                                    297 	.globl _PORTB
                                    298 	.globl _PORTA
                                    299 	.globl _PINR
                                    300 	.globl _PINC
                                    301 	.globl _PINB
                                    302 	.globl _PINA
                                    303 	.globl _DIRR
                                    304 	.globl _DIRC
                                    305 	.globl _DIRB
                                    306 	.globl _DIRA
                                    307 	.globl _DBGLNKSTAT
                                    308 	.globl _DBGLNKBUF
                                    309 	.globl _CODECONFIG
                                    310 	.globl _CLKSTAT
                                    311 	.globl _CLKCON
                                    312 	.globl _ANALOGCOMP
                                    313 	.globl _ADCCONV
                                    314 	.globl _ADCCLKSRC
                                    315 	.globl _ADCCH3CONFIG
                                    316 	.globl _ADCCH2CONFIG
                                    317 	.globl _ADCCH1CONFIG
                                    318 	.globl _ADCCH0CONFIG
                                    319 	.globl __XPAGE
                                    320 	.globl _XPAGE
                                    321 	.globl _SP
                                    322 	.globl _PSW
                                    323 	.globl _PCON
                                    324 	.globl _IP
                                    325 	.globl _IE
                                    326 	.globl _EIP
                                    327 	.globl _EIE
                                    328 	.globl _E2IP
                                    329 	.globl _E2IE
                                    330 	.globl _DPS
                                    331 	.globl _DPTR1
                                    332 	.globl _DPTR0
                                    333 	.globl _DPL1
                                    334 	.globl _DPL
                                    335 	.globl _DPH1
                                    336 	.globl _DPH
                                    337 	.globl _B
                                    338 	.globl _ACC
                                    339 	.globl _axradio_phy_chanvcoi
                                    340 	.globl _axradio_phy_chanpllrng
                                    341 	.globl _AX5043_TIMEGAIN3NB
                                    342 	.globl _AX5043_TIMEGAIN2NB
                                    343 	.globl _AX5043_TIMEGAIN1NB
                                    344 	.globl _AX5043_TIMEGAIN0NB
                                    345 	.globl _AX5043_RXPARAMSETSNB
                                    346 	.globl _AX5043_RXPARAMCURSETNB
                                    347 	.globl _AX5043_PKTMAXLENNB
                                    348 	.globl _AX5043_PKTLENOFFSETNB
                                    349 	.globl _AX5043_PKTLENCFGNB
                                    350 	.globl _AX5043_PKTADDRMASK3NB
                                    351 	.globl _AX5043_PKTADDRMASK2NB
                                    352 	.globl _AX5043_PKTADDRMASK1NB
                                    353 	.globl _AX5043_PKTADDRMASK0NB
                                    354 	.globl _AX5043_PKTADDRCFGNB
                                    355 	.globl _AX5043_PKTADDR3NB
                                    356 	.globl _AX5043_PKTADDR2NB
                                    357 	.globl _AX5043_PKTADDR1NB
                                    358 	.globl _AX5043_PKTADDR0NB
                                    359 	.globl _AX5043_PHASEGAIN3NB
                                    360 	.globl _AX5043_PHASEGAIN2NB
                                    361 	.globl _AX5043_PHASEGAIN1NB
                                    362 	.globl _AX5043_PHASEGAIN0NB
                                    363 	.globl _AX5043_FREQUENCYLEAKNB
                                    364 	.globl _AX5043_FREQUENCYGAIND3NB
                                    365 	.globl _AX5043_FREQUENCYGAIND2NB
                                    366 	.globl _AX5043_FREQUENCYGAIND1NB
                                    367 	.globl _AX5043_FREQUENCYGAIND0NB
                                    368 	.globl _AX5043_FREQUENCYGAINC3NB
                                    369 	.globl _AX5043_FREQUENCYGAINC2NB
                                    370 	.globl _AX5043_FREQUENCYGAINC1NB
                                    371 	.globl _AX5043_FREQUENCYGAINC0NB
                                    372 	.globl _AX5043_FREQUENCYGAINB3NB
                                    373 	.globl _AX5043_FREQUENCYGAINB2NB
                                    374 	.globl _AX5043_FREQUENCYGAINB1NB
                                    375 	.globl _AX5043_FREQUENCYGAINB0NB
                                    376 	.globl _AX5043_FREQUENCYGAINA3NB
                                    377 	.globl _AX5043_FREQUENCYGAINA2NB
                                    378 	.globl _AX5043_FREQUENCYGAINA1NB
                                    379 	.globl _AX5043_FREQUENCYGAINA0NB
                                    380 	.globl _AX5043_FREQDEV13NB
                                    381 	.globl _AX5043_FREQDEV12NB
                                    382 	.globl _AX5043_FREQDEV11NB
                                    383 	.globl _AX5043_FREQDEV10NB
                                    384 	.globl _AX5043_FREQDEV03NB
                                    385 	.globl _AX5043_FREQDEV02NB
                                    386 	.globl _AX5043_FREQDEV01NB
                                    387 	.globl _AX5043_FREQDEV00NB
                                    388 	.globl _AX5043_FOURFSK3NB
                                    389 	.globl _AX5043_FOURFSK2NB
                                    390 	.globl _AX5043_FOURFSK1NB
                                    391 	.globl _AX5043_FOURFSK0NB
                                    392 	.globl _AX5043_DRGAIN3NB
                                    393 	.globl _AX5043_DRGAIN2NB
                                    394 	.globl _AX5043_DRGAIN1NB
                                    395 	.globl _AX5043_DRGAIN0NB
                                    396 	.globl _AX5043_BBOFFSRES3NB
                                    397 	.globl _AX5043_BBOFFSRES2NB
                                    398 	.globl _AX5043_BBOFFSRES1NB
                                    399 	.globl _AX5043_BBOFFSRES0NB
                                    400 	.globl _AX5043_AMPLITUDEGAIN3NB
                                    401 	.globl _AX5043_AMPLITUDEGAIN2NB
                                    402 	.globl _AX5043_AMPLITUDEGAIN1NB
                                    403 	.globl _AX5043_AMPLITUDEGAIN0NB
                                    404 	.globl _AX5043_AGCTARGET3NB
                                    405 	.globl _AX5043_AGCTARGET2NB
                                    406 	.globl _AX5043_AGCTARGET1NB
                                    407 	.globl _AX5043_AGCTARGET0NB
                                    408 	.globl _AX5043_AGCMINMAX3NB
                                    409 	.globl _AX5043_AGCMINMAX2NB
                                    410 	.globl _AX5043_AGCMINMAX1NB
                                    411 	.globl _AX5043_AGCMINMAX0NB
                                    412 	.globl _AX5043_AGCGAIN3NB
                                    413 	.globl _AX5043_AGCGAIN2NB
                                    414 	.globl _AX5043_AGCGAIN1NB
                                    415 	.globl _AX5043_AGCGAIN0NB
                                    416 	.globl _AX5043_AGCAHYST3NB
                                    417 	.globl _AX5043_AGCAHYST2NB
                                    418 	.globl _AX5043_AGCAHYST1NB
                                    419 	.globl _AX5043_AGCAHYST0NB
                                    420 	.globl _AX5043_0xF44NB
                                    421 	.globl _AX5043_0xF35NB
                                    422 	.globl _AX5043_0xF34NB
                                    423 	.globl _AX5043_0xF33NB
                                    424 	.globl _AX5043_0xF32NB
                                    425 	.globl _AX5043_0xF31NB
                                    426 	.globl _AX5043_0xF30NB
                                    427 	.globl _AX5043_0xF26NB
                                    428 	.globl _AX5043_0xF23NB
                                    429 	.globl _AX5043_0xF22NB
                                    430 	.globl _AX5043_0xF21NB
                                    431 	.globl _AX5043_0xF1CNB
                                    432 	.globl _AX5043_0xF18NB
                                    433 	.globl _AX5043_0xF0CNB
                                    434 	.globl _AX5043_0xF00NB
                                    435 	.globl _AX5043_XTALSTATUSNB
                                    436 	.globl _AX5043_XTALOSCNB
                                    437 	.globl _AX5043_XTALCAPNB
                                    438 	.globl _AX5043_XTALAMPLNB
                                    439 	.globl _AX5043_WAKEUPXOEARLYNB
                                    440 	.globl _AX5043_WAKEUPTIMER1NB
                                    441 	.globl _AX5043_WAKEUPTIMER0NB
                                    442 	.globl _AX5043_WAKEUPFREQ1NB
                                    443 	.globl _AX5043_WAKEUPFREQ0NB
                                    444 	.globl _AX5043_WAKEUP1NB
                                    445 	.globl _AX5043_WAKEUP0NB
                                    446 	.globl _AX5043_TXRATE2NB
                                    447 	.globl _AX5043_TXRATE1NB
                                    448 	.globl _AX5043_TXRATE0NB
                                    449 	.globl _AX5043_TXPWRCOEFFE1NB
                                    450 	.globl _AX5043_TXPWRCOEFFE0NB
                                    451 	.globl _AX5043_TXPWRCOEFFD1NB
                                    452 	.globl _AX5043_TXPWRCOEFFD0NB
                                    453 	.globl _AX5043_TXPWRCOEFFC1NB
                                    454 	.globl _AX5043_TXPWRCOEFFC0NB
                                    455 	.globl _AX5043_TXPWRCOEFFB1NB
                                    456 	.globl _AX5043_TXPWRCOEFFB0NB
                                    457 	.globl _AX5043_TXPWRCOEFFA1NB
                                    458 	.globl _AX5043_TXPWRCOEFFA0NB
                                    459 	.globl _AX5043_TRKRFFREQ2NB
                                    460 	.globl _AX5043_TRKRFFREQ1NB
                                    461 	.globl _AX5043_TRKRFFREQ0NB
                                    462 	.globl _AX5043_TRKPHASE1NB
                                    463 	.globl _AX5043_TRKPHASE0NB
                                    464 	.globl _AX5043_TRKFSKDEMOD1NB
                                    465 	.globl _AX5043_TRKFSKDEMOD0NB
                                    466 	.globl _AX5043_TRKFREQ1NB
                                    467 	.globl _AX5043_TRKFREQ0NB
                                    468 	.globl _AX5043_TRKDATARATE2NB
                                    469 	.globl _AX5043_TRKDATARATE1NB
                                    470 	.globl _AX5043_TRKDATARATE0NB
                                    471 	.globl _AX5043_TRKAMPLITUDE1NB
                                    472 	.globl _AX5043_TRKAMPLITUDE0NB
                                    473 	.globl _AX5043_TRKAFSKDEMOD1NB
                                    474 	.globl _AX5043_TRKAFSKDEMOD0NB
                                    475 	.globl _AX5043_TMGTXSETTLENB
                                    476 	.globl _AX5043_TMGTXBOOSTNB
                                    477 	.globl _AX5043_TMGRXSETTLENB
                                    478 	.globl _AX5043_TMGRXRSSINB
                                    479 	.globl _AX5043_TMGRXPREAMBLE3NB
                                    480 	.globl _AX5043_TMGRXPREAMBLE2NB
                                    481 	.globl _AX5043_TMGRXPREAMBLE1NB
                                    482 	.globl _AX5043_TMGRXOFFSACQNB
                                    483 	.globl _AX5043_TMGRXCOARSEAGCNB
                                    484 	.globl _AX5043_TMGRXBOOSTNB
                                    485 	.globl _AX5043_TMGRXAGCNB
                                    486 	.globl _AX5043_TIMER2NB
                                    487 	.globl _AX5043_TIMER1NB
                                    488 	.globl _AX5043_TIMER0NB
                                    489 	.globl _AX5043_SILICONREVISIONNB
                                    490 	.globl _AX5043_SCRATCHNB
                                    491 	.globl _AX5043_RXDATARATE2NB
                                    492 	.globl _AX5043_RXDATARATE1NB
                                    493 	.globl _AX5043_RXDATARATE0NB
                                    494 	.globl _AX5043_RSSIREFERENCENB
                                    495 	.globl _AX5043_RSSIABSTHRNB
                                    496 	.globl _AX5043_RSSINB
                                    497 	.globl _AX5043_REFNB
                                    498 	.globl _AX5043_RADIOSTATENB
                                    499 	.globl _AX5043_RADIOEVENTREQ1NB
                                    500 	.globl _AX5043_RADIOEVENTREQ0NB
                                    501 	.globl _AX5043_RADIOEVENTMASK1NB
                                    502 	.globl _AX5043_RADIOEVENTMASK0NB
                                    503 	.globl _AX5043_PWRMODENB
                                    504 	.globl _AX5043_PWRAMPNB
                                    505 	.globl _AX5043_POWSTICKYSTATNB
                                    506 	.globl _AX5043_POWSTATNB
                                    507 	.globl _AX5043_POWIRQMASKNB
                                    508 	.globl _AX5043_POWCTRL1NB
                                    509 	.globl _AX5043_PLLVCOIRNB
                                    510 	.globl _AX5043_PLLVCOINB
                                    511 	.globl _AX5043_PLLVCODIVNB
                                    512 	.globl _AX5043_PLLRNGCLKNB
                                    513 	.globl _AX5043_PLLRANGINGBNB
                                    514 	.globl _AX5043_PLLRANGINGANB
                                    515 	.globl _AX5043_PLLLOOPBOOSTNB
                                    516 	.globl _AX5043_PLLLOOPNB
                                    517 	.globl _AX5043_PLLLOCKDETNB
                                    518 	.globl _AX5043_PLLCPIBOOSTNB
                                    519 	.globl _AX5043_PLLCPINB
                                    520 	.globl _AX5043_PKTSTOREFLAGSNB
                                    521 	.globl _AX5043_PKTMISCFLAGSNB
                                    522 	.globl _AX5043_PKTCHUNKSIZENB
                                    523 	.globl _AX5043_PKTACCEPTFLAGSNB
                                    524 	.globl _AX5043_PINSTATENB
                                    525 	.globl _AX5043_PINFUNCSYSCLKNB
                                    526 	.globl _AX5043_PINFUNCPWRAMPNB
                                    527 	.globl _AX5043_PINFUNCIRQNB
                                    528 	.globl _AX5043_PINFUNCDCLKNB
                                    529 	.globl _AX5043_PINFUNCDATANB
                                    530 	.globl _AX5043_PINFUNCANTSELNB
                                    531 	.globl _AX5043_MODULATIONNB
                                    532 	.globl _AX5043_MODCFGPNB
                                    533 	.globl _AX5043_MODCFGFNB
                                    534 	.globl _AX5043_MODCFGANB
                                    535 	.globl _AX5043_MAXRFOFFSET2NB
                                    536 	.globl _AX5043_MAXRFOFFSET1NB
                                    537 	.globl _AX5043_MAXRFOFFSET0NB
                                    538 	.globl _AX5043_MAXDROFFSET2NB
                                    539 	.globl _AX5043_MAXDROFFSET1NB
                                    540 	.globl _AX5043_MAXDROFFSET0NB
                                    541 	.globl _AX5043_MATCH1PAT1NB
                                    542 	.globl _AX5043_MATCH1PAT0NB
                                    543 	.globl _AX5043_MATCH1MINNB
                                    544 	.globl _AX5043_MATCH1MAXNB
                                    545 	.globl _AX5043_MATCH1LENNB
                                    546 	.globl _AX5043_MATCH0PAT3NB
                                    547 	.globl _AX5043_MATCH0PAT2NB
                                    548 	.globl _AX5043_MATCH0PAT1NB
                                    549 	.globl _AX5043_MATCH0PAT0NB
                                    550 	.globl _AX5043_MATCH0MINNB
                                    551 	.globl _AX5043_MATCH0MAXNB
                                    552 	.globl _AX5043_MATCH0LENNB
                                    553 	.globl _AX5043_LPOSCSTATUSNB
                                    554 	.globl _AX5043_LPOSCREF1NB
                                    555 	.globl _AX5043_LPOSCREF0NB
                                    556 	.globl _AX5043_LPOSCPER1NB
                                    557 	.globl _AX5043_LPOSCPER0NB
                                    558 	.globl _AX5043_LPOSCKFILT1NB
                                    559 	.globl _AX5043_LPOSCKFILT0NB
                                    560 	.globl _AX5043_LPOSCFREQ1NB
                                    561 	.globl _AX5043_LPOSCFREQ0NB
                                    562 	.globl _AX5043_LPOSCCONFIGNB
                                    563 	.globl _AX5043_IRQREQUEST1NB
                                    564 	.globl _AX5043_IRQREQUEST0NB
                                    565 	.globl _AX5043_IRQMASK1NB
                                    566 	.globl _AX5043_IRQMASK0NB
                                    567 	.globl _AX5043_IRQINVERSION1NB
                                    568 	.globl _AX5043_IRQINVERSION0NB
                                    569 	.globl _AX5043_IFFREQ1NB
                                    570 	.globl _AX5043_IFFREQ0NB
                                    571 	.globl _AX5043_GPADCPERIODNB
                                    572 	.globl _AX5043_GPADCCTRLNB
                                    573 	.globl _AX5043_GPADC13VALUE1NB
                                    574 	.globl _AX5043_GPADC13VALUE0NB
                                    575 	.globl _AX5043_FSKDMIN1NB
                                    576 	.globl _AX5043_FSKDMIN0NB
                                    577 	.globl _AX5043_FSKDMAX1NB
                                    578 	.globl _AX5043_FSKDMAX0NB
                                    579 	.globl _AX5043_FSKDEV2NB
                                    580 	.globl _AX5043_FSKDEV1NB
                                    581 	.globl _AX5043_FSKDEV0NB
                                    582 	.globl _AX5043_FREQB3NB
                                    583 	.globl _AX5043_FREQB2NB
                                    584 	.globl _AX5043_FREQB1NB
                                    585 	.globl _AX5043_FREQB0NB
                                    586 	.globl _AX5043_FREQA3NB
                                    587 	.globl _AX5043_FREQA2NB
                                    588 	.globl _AX5043_FREQA1NB
                                    589 	.globl _AX5043_FREQA0NB
                                    590 	.globl _AX5043_FRAMINGNB
                                    591 	.globl _AX5043_FIFOTHRESH1NB
                                    592 	.globl _AX5043_FIFOTHRESH0NB
                                    593 	.globl _AX5043_FIFOSTATNB
                                    594 	.globl _AX5043_FIFOFREE1NB
                                    595 	.globl _AX5043_FIFOFREE0NB
                                    596 	.globl _AX5043_FIFODATANB
                                    597 	.globl _AX5043_FIFOCOUNT1NB
                                    598 	.globl _AX5043_FIFOCOUNT0NB
                                    599 	.globl _AX5043_FECSYNCNB
                                    600 	.globl _AX5043_FECSTATUSNB
                                    601 	.globl _AX5043_FECNB
                                    602 	.globl _AX5043_ENCODINGNB
                                    603 	.globl _AX5043_DIVERSITYNB
                                    604 	.globl _AX5043_DECIMATIONNB
                                    605 	.globl _AX5043_DACVALUE1NB
                                    606 	.globl _AX5043_DACVALUE0NB
                                    607 	.globl _AX5043_DACCONFIGNB
                                    608 	.globl _AX5043_CRCINIT3NB
                                    609 	.globl _AX5043_CRCINIT2NB
                                    610 	.globl _AX5043_CRCINIT1NB
                                    611 	.globl _AX5043_CRCINIT0NB
                                    612 	.globl _AX5043_BGNDRSSITHRNB
                                    613 	.globl _AX5043_BGNDRSSIGAINNB
                                    614 	.globl _AX5043_BGNDRSSINB
                                    615 	.globl _AX5043_BBTUNENB
                                    616 	.globl _AX5043_BBOFFSCAPNB
                                    617 	.globl _AX5043_AMPLFILTERNB
                                    618 	.globl _AX5043_AGCCOUNTERNB
                                    619 	.globl _AX5043_AFSKSPACE1NB
                                    620 	.globl _AX5043_AFSKSPACE0NB
                                    621 	.globl _AX5043_AFSKMARK1NB
                                    622 	.globl _AX5043_AFSKMARK0NB
                                    623 	.globl _AX5043_AFSKCTRLNB
                                    624 	.globl _AX5043_TIMEGAIN3
                                    625 	.globl _AX5043_TIMEGAIN2
                                    626 	.globl _AX5043_TIMEGAIN1
                                    627 	.globl _AX5043_TIMEGAIN0
                                    628 	.globl _AX5043_RXPARAMSETS
                                    629 	.globl _AX5043_RXPARAMCURSET
                                    630 	.globl _AX5043_PKTMAXLEN
                                    631 	.globl _AX5043_PKTLENOFFSET
                                    632 	.globl _AX5043_PKTLENCFG
                                    633 	.globl _AX5043_PKTADDRMASK3
                                    634 	.globl _AX5043_PKTADDRMASK2
                                    635 	.globl _AX5043_PKTADDRMASK1
                                    636 	.globl _AX5043_PKTADDRMASK0
                                    637 	.globl _AX5043_PKTADDRCFG
                                    638 	.globl _AX5043_PKTADDR3
                                    639 	.globl _AX5043_PKTADDR2
                                    640 	.globl _AX5043_PKTADDR1
                                    641 	.globl _AX5043_PKTADDR0
                                    642 	.globl _AX5043_PHASEGAIN3
                                    643 	.globl _AX5043_PHASEGAIN2
                                    644 	.globl _AX5043_PHASEGAIN1
                                    645 	.globl _AX5043_PHASEGAIN0
                                    646 	.globl _AX5043_FREQUENCYLEAK
                                    647 	.globl _AX5043_FREQUENCYGAIND3
                                    648 	.globl _AX5043_FREQUENCYGAIND2
                                    649 	.globl _AX5043_FREQUENCYGAIND1
                                    650 	.globl _AX5043_FREQUENCYGAIND0
                                    651 	.globl _AX5043_FREQUENCYGAINC3
                                    652 	.globl _AX5043_FREQUENCYGAINC2
                                    653 	.globl _AX5043_FREQUENCYGAINC1
                                    654 	.globl _AX5043_FREQUENCYGAINC0
                                    655 	.globl _AX5043_FREQUENCYGAINB3
                                    656 	.globl _AX5043_FREQUENCYGAINB2
                                    657 	.globl _AX5043_FREQUENCYGAINB1
                                    658 	.globl _AX5043_FREQUENCYGAINB0
                                    659 	.globl _AX5043_FREQUENCYGAINA3
                                    660 	.globl _AX5043_FREQUENCYGAINA2
                                    661 	.globl _AX5043_FREQUENCYGAINA1
                                    662 	.globl _AX5043_FREQUENCYGAINA0
                                    663 	.globl _AX5043_FREQDEV13
                                    664 	.globl _AX5043_FREQDEV12
                                    665 	.globl _AX5043_FREQDEV11
                                    666 	.globl _AX5043_FREQDEV10
                                    667 	.globl _AX5043_FREQDEV03
                                    668 	.globl _AX5043_FREQDEV02
                                    669 	.globl _AX5043_FREQDEV01
                                    670 	.globl _AX5043_FREQDEV00
                                    671 	.globl _AX5043_FOURFSK3
                                    672 	.globl _AX5043_FOURFSK2
                                    673 	.globl _AX5043_FOURFSK1
                                    674 	.globl _AX5043_FOURFSK0
                                    675 	.globl _AX5043_DRGAIN3
                                    676 	.globl _AX5043_DRGAIN2
                                    677 	.globl _AX5043_DRGAIN1
                                    678 	.globl _AX5043_DRGAIN0
                                    679 	.globl _AX5043_BBOFFSRES3
                                    680 	.globl _AX5043_BBOFFSRES2
                                    681 	.globl _AX5043_BBOFFSRES1
                                    682 	.globl _AX5043_BBOFFSRES0
                                    683 	.globl _AX5043_AMPLITUDEGAIN3
                                    684 	.globl _AX5043_AMPLITUDEGAIN2
                                    685 	.globl _AX5043_AMPLITUDEGAIN1
                                    686 	.globl _AX5043_AMPLITUDEGAIN0
                                    687 	.globl _AX5043_AGCTARGET3
                                    688 	.globl _AX5043_AGCTARGET2
                                    689 	.globl _AX5043_AGCTARGET1
                                    690 	.globl _AX5043_AGCTARGET0
                                    691 	.globl _AX5043_AGCMINMAX3
                                    692 	.globl _AX5043_AGCMINMAX2
                                    693 	.globl _AX5043_AGCMINMAX1
                                    694 	.globl _AX5043_AGCMINMAX0
                                    695 	.globl _AX5043_AGCGAIN3
                                    696 	.globl _AX5043_AGCGAIN2
                                    697 	.globl _AX5043_AGCGAIN1
                                    698 	.globl _AX5043_AGCGAIN0
                                    699 	.globl _AX5043_AGCAHYST3
                                    700 	.globl _AX5043_AGCAHYST2
                                    701 	.globl _AX5043_AGCAHYST1
                                    702 	.globl _AX5043_AGCAHYST0
                                    703 	.globl _AX5043_0xF44
                                    704 	.globl _AX5043_0xF35
                                    705 	.globl _AX5043_0xF34
                                    706 	.globl _AX5043_0xF33
                                    707 	.globl _AX5043_0xF32
                                    708 	.globl _AX5043_0xF31
                                    709 	.globl _AX5043_0xF30
                                    710 	.globl _AX5043_0xF26
                                    711 	.globl _AX5043_0xF23
                                    712 	.globl _AX5043_0xF22
                                    713 	.globl _AX5043_0xF21
                                    714 	.globl _AX5043_0xF1C
                                    715 	.globl _AX5043_0xF18
                                    716 	.globl _AX5043_0xF0C
                                    717 	.globl _AX5043_0xF00
                                    718 	.globl _AX5043_XTALSTATUS
                                    719 	.globl _AX5043_XTALOSC
                                    720 	.globl _AX5043_XTALCAP
                                    721 	.globl _AX5043_XTALAMPL
                                    722 	.globl _AX5043_WAKEUPXOEARLY
                                    723 	.globl _AX5043_WAKEUPTIMER1
                                    724 	.globl _AX5043_WAKEUPTIMER0
                                    725 	.globl _AX5043_WAKEUPFREQ1
                                    726 	.globl _AX5043_WAKEUPFREQ0
                                    727 	.globl _AX5043_WAKEUP1
                                    728 	.globl _AX5043_WAKEUP0
                                    729 	.globl _AX5043_TXRATE2
                                    730 	.globl _AX5043_TXRATE1
                                    731 	.globl _AX5043_TXRATE0
                                    732 	.globl _AX5043_TXPWRCOEFFE1
                                    733 	.globl _AX5043_TXPWRCOEFFE0
                                    734 	.globl _AX5043_TXPWRCOEFFD1
                                    735 	.globl _AX5043_TXPWRCOEFFD0
                                    736 	.globl _AX5043_TXPWRCOEFFC1
                                    737 	.globl _AX5043_TXPWRCOEFFC0
                                    738 	.globl _AX5043_TXPWRCOEFFB1
                                    739 	.globl _AX5043_TXPWRCOEFFB0
                                    740 	.globl _AX5043_TXPWRCOEFFA1
                                    741 	.globl _AX5043_TXPWRCOEFFA0
                                    742 	.globl _AX5043_TRKRFFREQ2
                                    743 	.globl _AX5043_TRKRFFREQ1
                                    744 	.globl _AX5043_TRKRFFREQ0
                                    745 	.globl _AX5043_TRKPHASE1
                                    746 	.globl _AX5043_TRKPHASE0
                                    747 	.globl _AX5043_TRKFSKDEMOD1
                                    748 	.globl _AX5043_TRKFSKDEMOD0
                                    749 	.globl _AX5043_TRKFREQ1
                                    750 	.globl _AX5043_TRKFREQ0
                                    751 	.globl _AX5043_TRKDATARATE2
                                    752 	.globl _AX5043_TRKDATARATE1
                                    753 	.globl _AX5043_TRKDATARATE0
                                    754 	.globl _AX5043_TRKAMPLITUDE1
                                    755 	.globl _AX5043_TRKAMPLITUDE0
                                    756 	.globl _AX5043_TRKAFSKDEMOD1
                                    757 	.globl _AX5043_TRKAFSKDEMOD0
                                    758 	.globl _AX5043_TMGTXSETTLE
                                    759 	.globl _AX5043_TMGTXBOOST
                                    760 	.globl _AX5043_TMGRXSETTLE
                                    761 	.globl _AX5043_TMGRXRSSI
                                    762 	.globl _AX5043_TMGRXPREAMBLE3
                                    763 	.globl _AX5043_TMGRXPREAMBLE2
                                    764 	.globl _AX5043_TMGRXPREAMBLE1
                                    765 	.globl _AX5043_TMGRXOFFSACQ
                                    766 	.globl _AX5043_TMGRXCOARSEAGC
                                    767 	.globl _AX5043_TMGRXBOOST
                                    768 	.globl _AX5043_TMGRXAGC
                                    769 	.globl _AX5043_TIMER2
                                    770 	.globl _AX5043_TIMER1
                                    771 	.globl _AX5043_TIMER0
                                    772 	.globl _AX5043_SILICONREVISION
                                    773 	.globl _AX5043_SCRATCH
                                    774 	.globl _AX5043_RXDATARATE2
                                    775 	.globl _AX5043_RXDATARATE1
                                    776 	.globl _AX5043_RXDATARATE0
                                    777 	.globl _AX5043_RSSIREFERENCE
                                    778 	.globl _AX5043_RSSIABSTHR
                                    779 	.globl _AX5043_RSSI
                                    780 	.globl _AX5043_REF
                                    781 	.globl _AX5043_RADIOSTATE
                                    782 	.globl _AX5043_RADIOEVENTREQ1
                                    783 	.globl _AX5043_RADIOEVENTREQ0
                                    784 	.globl _AX5043_RADIOEVENTMASK1
                                    785 	.globl _AX5043_RADIOEVENTMASK0
                                    786 	.globl _AX5043_PWRMODE
                                    787 	.globl _AX5043_PWRAMP
                                    788 	.globl _AX5043_POWSTICKYSTAT
                                    789 	.globl _AX5043_POWSTAT
                                    790 	.globl _AX5043_POWIRQMASK
                                    791 	.globl _AX5043_POWCTRL1
                                    792 	.globl _AX5043_PLLVCOIR
                                    793 	.globl _AX5043_PLLVCOI
                                    794 	.globl _AX5043_PLLVCODIV
                                    795 	.globl _AX5043_PLLRNGCLK
                                    796 	.globl _AX5043_PLLRANGINGB
                                    797 	.globl _AX5043_PLLRANGINGA
                                    798 	.globl _AX5043_PLLLOOPBOOST
                                    799 	.globl _AX5043_PLLLOOP
                                    800 	.globl _AX5043_PLLLOCKDET
                                    801 	.globl _AX5043_PLLCPIBOOST
                                    802 	.globl _AX5043_PLLCPI
                                    803 	.globl _AX5043_PKTSTOREFLAGS
                                    804 	.globl _AX5043_PKTMISCFLAGS
                                    805 	.globl _AX5043_PKTCHUNKSIZE
                                    806 	.globl _AX5043_PKTACCEPTFLAGS
                                    807 	.globl _AX5043_PINSTATE
                                    808 	.globl _AX5043_PINFUNCSYSCLK
                                    809 	.globl _AX5043_PINFUNCPWRAMP
                                    810 	.globl _AX5043_PINFUNCIRQ
                                    811 	.globl _AX5043_PINFUNCDCLK
                                    812 	.globl _AX5043_PINFUNCDATA
                                    813 	.globl _AX5043_PINFUNCANTSEL
                                    814 	.globl _AX5043_MODULATION
                                    815 	.globl _AX5043_MODCFGP
                                    816 	.globl _AX5043_MODCFGF
                                    817 	.globl _AX5043_MODCFGA
                                    818 	.globl _AX5043_MAXRFOFFSET2
                                    819 	.globl _AX5043_MAXRFOFFSET1
                                    820 	.globl _AX5043_MAXRFOFFSET0
                                    821 	.globl _AX5043_MAXDROFFSET2
                                    822 	.globl _AX5043_MAXDROFFSET1
                                    823 	.globl _AX5043_MAXDROFFSET0
                                    824 	.globl _AX5043_MATCH1PAT1
                                    825 	.globl _AX5043_MATCH1PAT0
                                    826 	.globl _AX5043_MATCH1MIN
                                    827 	.globl _AX5043_MATCH1MAX
                                    828 	.globl _AX5043_MATCH1LEN
                                    829 	.globl _AX5043_MATCH0PAT3
                                    830 	.globl _AX5043_MATCH0PAT2
                                    831 	.globl _AX5043_MATCH0PAT1
                                    832 	.globl _AX5043_MATCH0PAT0
                                    833 	.globl _AX5043_MATCH0MIN
                                    834 	.globl _AX5043_MATCH0MAX
                                    835 	.globl _AX5043_MATCH0LEN
                                    836 	.globl _AX5043_LPOSCSTATUS
                                    837 	.globl _AX5043_LPOSCREF1
                                    838 	.globl _AX5043_LPOSCREF0
                                    839 	.globl _AX5043_LPOSCPER1
                                    840 	.globl _AX5043_LPOSCPER0
                                    841 	.globl _AX5043_LPOSCKFILT1
                                    842 	.globl _AX5043_LPOSCKFILT0
                                    843 	.globl _AX5043_LPOSCFREQ1
                                    844 	.globl _AX5043_LPOSCFREQ0
                                    845 	.globl _AX5043_LPOSCCONFIG
                                    846 	.globl _AX5043_IRQREQUEST1
                                    847 	.globl _AX5043_IRQREQUEST0
                                    848 	.globl _AX5043_IRQMASK1
                                    849 	.globl _AX5043_IRQMASK0
                                    850 	.globl _AX5043_IRQINVERSION1
                                    851 	.globl _AX5043_IRQINVERSION0
                                    852 	.globl _AX5043_IFFREQ1
                                    853 	.globl _AX5043_IFFREQ0
                                    854 	.globl _AX5043_GPADCPERIOD
                                    855 	.globl _AX5043_GPADCCTRL
                                    856 	.globl _AX5043_GPADC13VALUE1
                                    857 	.globl _AX5043_GPADC13VALUE0
                                    858 	.globl _AX5043_FSKDMIN1
                                    859 	.globl _AX5043_FSKDMIN0
                                    860 	.globl _AX5043_FSKDMAX1
                                    861 	.globl _AX5043_FSKDMAX0
                                    862 	.globl _AX5043_FSKDEV2
                                    863 	.globl _AX5043_FSKDEV1
                                    864 	.globl _AX5043_FSKDEV0
                                    865 	.globl _AX5043_FREQB3
                                    866 	.globl _AX5043_FREQB2
                                    867 	.globl _AX5043_FREQB1
                                    868 	.globl _AX5043_FREQB0
                                    869 	.globl _AX5043_FREQA3
                                    870 	.globl _AX5043_FREQA2
                                    871 	.globl _AX5043_FREQA1
                                    872 	.globl _AX5043_FREQA0
                                    873 	.globl _AX5043_FRAMING
                                    874 	.globl _AX5043_FIFOTHRESH1
                                    875 	.globl _AX5043_FIFOTHRESH0
                                    876 	.globl _AX5043_FIFOSTAT
                                    877 	.globl _AX5043_FIFOFREE1
                                    878 	.globl _AX5043_FIFOFREE0
                                    879 	.globl _AX5043_FIFODATA
                                    880 	.globl _AX5043_FIFOCOUNT1
                                    881 	.globl _AX5043_FIFOCOUNT0
                                    882 	.globl _AX5043_FECSYNC
                                    883 	.globl _AX5043_FECSTATUS
                                    884 	.globl _AX5043_FEC
                                    885 	.globl _AX5043_ENCODING
                                    886 	.globl _AX5043_DIVERSITY
                                    887 	.globl _AX5043_DECIMATION
                                    888 	.globl _AX5043_DACVALUE1
                                    889 	.globl _AX5043_DACVALUE0
                                    890 	.globl _AX5043_DACCONFIG
                                    891 	.globl _AX5043_CRCINIT3
                                    892 	.globl _AX5043_CRCINIT2
                                    893 	.globl _AX5043_CRCINIT1
                                    894 	.globl _AX5043_CRCINIT0
                                    895 	.globl _AX5043_BGNDRSSITHR
                                    896 	.globl _AX5043_BGNDRSSIGAIN
                                    897 	.globl _AX5043_BGNDRSSI
                                    898 	.globl _AX5043_BBTUNE
                                    899 	.globl _AX5043_BBOFFSCAP
                                    900 	.globl _AX5043_AMPLFILTER
                                    901 	.globl _AX5043_AGCCOUNTER
                                    902 	.globl _AX5043_AFSKSPACE1
                                    903 	.globl _AX5043_AFSKSPACE0
                                    904 	.globl _AX5043_AFSKMARK1
                                    905 	.globl _AX5043_AFSKMARK0
                                    906 	.globl _AX5043_AFSKCTRL
                                    907 	.globl _XTALREADY
                                    908 	.globl _XTALOSC
                                    909 	.globl _XTALAMPL
                                    910 	.globl _SILICONREV
                                    911 	.globl _SCRATCH3
                                    912 	.globl _SCRATCH2
                                    913 	.globl _SCRATCH1
                                    914 	.globl _SCRATCH0
                                    915 	.globl _RADIOMUX
                                    916 	.globl _RADIOFSTATADDR
                                    917 	.globl _RADIOFSTATADDR1
                                    918 	.globl _RADIOFSTATADDR0
                                    919 	.globl _RADIOFDATAADDR
                                    920 	.globl _RADIOFDATAADDR1
                                    921 	.globl _RADIOFDATAADDR0
                                    922 	.globl _OSCRUN
                                    923 	.globl _OSCREADY
                                    924 	.globl _OSCFORCERUN
                                    925 	.globl _OSCCALIB
                                    926 	.globl _MISCCTRL
                                    927 	.globl _LPXOSCGM
                                    928 	.globl _LPOSCREF
                                    929 	.globl _LPOSCREF1
                                    930 	.globl _LPOSCREF0
                                    931 	.globl _LPOSCPER
                                    932 	.globl _LPOSCPER1
                                    933 	.globl _LPOSCPER0
                                    934 	.globl _LPOSCKFILT
                                    935 	.globl _LPOSCKFILT1
                                    936 	.globl _LPOSCKFILT0
                                    937 	.globl _LPOSCFREQ
                                    938 	.globl _LPOSCFREQ1
                                    939 	.globl _LPOSCFREQ0
                                    940 	.globl _LPOSCCONFIG
                                    941 	.globl _PINSEL
                                    942 	.globl _PINCHGC
                                    943 	.globl _PINCHGB
                                    944 	.globl _PINCHGA
                                    945 	.globl _PALTRADIO
                                    946 	.globl _PALTC
                                    947 	.globl _PALTB
                                    948 	.globl _PALTA
                                    949 	.globl _INTCHGC
                                    950 	.globl _INTCHGB
                                    951 	.globl _INTCHGA
                                    952 	.globl _EXTIRQ
                                    953 	.globl _GPIOENABLE
                                    954 	.globl _ANALOGA
                                    955 	.globl _FRCOSCREF
                                    956 	.globl _FRCOSCREF1
                                    957 	.globl _FRCOSCREF0
                                    958 	.globl _FRCOSCPER
                                    959 	.globl _FRCOSCPER1
                                    960 	.globl _FRCOSCPER0
                                    961 	.globl _FRCOSCKFILT
                                    962 	.globl _FRCOSCKFILT1
                                    963 	.globl _FRCOSCKFILT0
                                    964 	.globl _FRCOSCFREQ
                                    965 	.globl _FRCOSCFREQ1
                                    966 	.globl _FRCOSCFREQ0
                                    967 	.globl _FRCOSCCTRL
                                    968 	.globl _FRCOSCCONFIG
                                    969 	.globl _DMA1CONFIG
                                    970 	.globl _DMA1ADDR
                                    971 	.globl _DMA1ADDR1
                                    972 	.globl _DMA1ADDR0
                                    973 	.globl _DMA0CONFIG
                                    974 	.globl _DMA0ADDR
                                    975 	.globl _DMA0ADDR1
                                    976 	.globl _DMA0ADDR0
                                    977 	.globl _ADCTUNE2
                                    978 	.globl _ADCTUNE1
                                    979 	.globl _ADCTUNE0
                                    980 	.globl _ADCCH3VAL
                                    981 	.globl _ADCCH3VAL1
                                    982 	.globl _ADCCH3VAL0
                                    983 	.globl _ADCCH2VAL
                                    984 	.globl _ADCCH2VAL1
                                    985 	.globl _ADCCH2VAL0
                                    986 	.globl _ADCCH1VAL
                                    987 	.globl _ADCCH1VAL1
                                    988 	.globl _ADCCH1VAL0
                                    989 	.globl _ADCCH0VAL
                                    990 	.globl _ADCCH0VAL1
                                    991 	.globl _ADCCH0VAL0
                                    992 	.globl _ax5043_set_registers
                                    993 	.globl _ax5043_set_registers_tx
                                    994 	.globl _ax5043_set_registers_rx
                                    995 	.globl _ax5043_set_registers_rxwor
                                    996 	.globl _ax5043_set_registers_rxcont
                                    997 	.globl _ax5043_set_registers_rxcont_singleparamset
                                    998 	.globl _axradio_setup_pincfg1
                                    999 	.globl _axradio_setup_pincfg2
                                   1000 	.globl _axradio_conv_freq_fromhz
                                   1001 	.globl _axradio_conv_freq_tohz
                                   1002 	.globl _axradio_conv_freq_fromreg
                                   1003 	.globl _axradio_conv_timeinterval_totimer0
                                   1004 	.globl _axradio_framing_check_crc
                                   1005 	.globl _axradio_framing_append_crc
                                   1006 ;--------------------------------------------------------
                                   1007 ; special function registers
                                   1008 ;--------------------------------------------------------
                                   1009 	.area RSEG    (ABS,DATA)
      000000                       1010 	.org 0x0000
                           0000E0  1011 G$ACC$0$0 == 0x00e0
                           0000E0  1012 _ACC	=	0x00e0
                           0000F0  1013 G$B$0$0 == 0x00f0
                           0000F0  1014 _B	=	0x00f0
                           000083  1015 G$DPH$0$0 == 0x0083
                           000083  1016 _DPH	=	0x0083
                           000085  1017 G$DPH1$0$0 == 0x0085
                           000085  1018 _DPH1	=	0x0085
                           000082  1019 G$DPL$0$0 == 0x0082
                           000082  1020 _DPL	=	0x0082
                           000084  1021 G$DPL1$0$0 == 0x0084
                           000084  1022 _DPL1	=	0x0084
                           008382  1023 G$DPTR0$0$0 == 0x8382
                           008382  1024 _DPTR0	=	0x8382
                           008584  1025 G$DPTR1$0$0 == 0x8584
                           008584  1026 _DPTR1	=	0x8584
                           000086  1027 G$DPS$0$0 == 0x0086
                           000086  1028 _DPS	=	0x0086
                           0000A0  1029 G$E2IE$0$0 == 0x00a0
                           0000A0  1030 _E2IE	=	0x00a0
                           0000C0  1031 G$E2IP$0$0 == 0x00c0
                           0000C0  1032 _E2IP	=	0x00c0
                           000098  1033 G$EIE$0$0 == 0x0098
                           000098  1034 _EIE	=	0x0098
                           0000B0  1035 G$EIP$0$0 == 0x00b0
                           0000B0  1036 _EIP	=	0x00b0
                           0000A8  1037 G$IE$0$0 == 0x00a8
                           0000A8  1038 _IE	=	0x00a8
                           0000B8  1039 G$IP$0$0 == 0x00b8
                           0000B8  1040 _IP	=	0x00b8
                           000087  1041 G$PCON$0$0 == 0x0087
                           000087  1042 _PCON	=	0x0087
                           0000D0  1043 G$PSW$0$0 == 0x00d0
                           0000D0  1044 _PSW	=	0x00d0
                           000081  1045 G$SP$0$0 == 0x0081
                           000081  1046 _SP	=	0x0081
                           0000D9  1047 G$XPAGE$0$0 == 0x00d9
                           0000D9  1048 _XPAGE	=	0x00d9
                           0000D9  1049 G$_XPAGE$0$0 == 0x00d9
                           0000D9  1050 __XPAGE	=	0x00d9
                           0000CA  1051 G$ADCCH0CONFIG$0$0 == 0x00ca
                           0000CA  1052 _ADCCH0CONFIG	=	0x00ca
                           0000CB  1053 G$ADCCH1CONFIG$0$0 == 0x00cb
                           0000CB  1054 _ADCCH1CONFIG	=	0x00cb
                           0000D2  1055 G$ADCCH2CONFIG$0$0 == 0x00d2
                           0000D2  1056 _ADCCH2CONFIG	=	0x00d2
                           0000D3  1057 G$ADCCH3CONFIG$0$0 == 0x00d3
                           0000D3  1058 _ADCCH3CONFIG	=	0x00d3
                           0000D1  1059 G$ADCCLKSRC$0$0 == 0x00d1
                           0000D1  1060 _ADCCLKSRC	=	0x00d1
                           0000C9  1061 G$ADCCONV$0$0 == 0x00c9
                           0000C9  1062 _ADCCONV	=	0x00c9
                           0000E1  1063 G$ANALOGCOMP$0$0 == 0x00e1
                           0000E1  1064 _ANALOGCOMP	=	0x00e1
                           0000C6  1065 G$CLKCON$0$0 == 0x00c6
                           0000C6  1066 _CLKCON	=	0x00c6
                           0000C7  1067 G$CLKSTAT$0$0 == 0x00c7
                           0000C7  1068 _CLKSTAT	=	0x00c7
                           000097  1069 G$CODECONFIG$0$0 == 0x0097
                           000097  1070 _CODECONFIG	=	0x0097
                           0000E3  1071 G$DBGLNKBUF$0$0 == 0x00e3
                           0000E3  1072 _DBGLNKBUF	=	0x00e3
                           0000E2  1073 G$DBGLNKSTAT$0$0 == 0x00e2
                           0000E2  1074 _DBGLNKSTAT	=	0x00e2
                           000089  1075 G$DIRA$0$0 == 0x0089
                           000089  1076 _DIRA	=	0x0089
                           00008A  1077 G$DIRB$0$0 == 0x008a
                           00008A  1078 _DIRB	=	0x008a
                           00008B  1079 G$DIRC$0$0 == 0x008b
                           00008B  1080 _DIRC	=	0x008b
                           00008E  1081 G$DIRR$0$0 == 0x008e
                           00008E  1082 _DIRR	=	0x008e
                           0000C8  1083 G$PINA$0$0 == 0x00c8
                           0000C8  1084 _PINA	=	0x00c8
                           0000E8  1085 G$PINB$0$0 == 0x00e8
                           0000E8  1086 _PINB	=	0x00e8
                           0000F8  1087 G$PINC$0$0 == 0x00f8
                           0000F8  1088 _PINC	=	0x00f8
                           00008D  1089 G$PINR$0$0 == 0x008d
                           00008D  1090 _PINR	=	0x008d
                           000080  1091 G$PORTA$0$0 == 0x0080
                           000080  1092 _PORTA	=	0x0080
                           000088  1093 G$PORTB$0$0 == 0x0088
                           000088  1094 _PORTB	=	0x0088
                           000090  1095 G$PORTC$0$0 == 0x0090
                           000090  1096 _PORTC	=	0x0090
                           00008C  1097 G$PORTR$0$0 == 0x008c
                           00008C  1098 _PORTR	=	0x008c
                           0000CE  1099 G$IC0CAPT0$0$0 == 0x00ce
                           0000CE  1100 _IC0CAPT0	=	0x00ce
                           0000CF  1101 G$IC0CAPT1$0$0 == 0x00cf
                           0000CF  1102 _IC0CAPT1	=	0x00cf
                           00CFCE  1103 G$IC0CAPT$0$0 == 0xcfce
                           00CFCE  1104 _IC0CAPT	=	0xcfce
                           0000CC  1105 G$IC0MODE$0$0 == 0x00cc
                           0000CC  1106 _IC0MODE	=	0x00cc
                           0000CD  1107 G$IC0STATUS$0$0 == 0x00cd
                           0000CD  1108 _IC0STATUS	=	0x00cd
                           0000D6  1109 G$IC1CAPT0$0$0 == 0x00d6
                           0000D6  1110 _IC1CAPT0	=	0x00d6
                           0000D7  1111 G$IC1CAPT1$0$0 == 0x00d7
                           0000D7  1112 _IC1CAPT1	=	0x00d7
                           00D7D6  1113 G$IC1CAPT$0$0 == 0xd7d6
                           00D7D6  1114 _IC1CAPT	=	0xd7d6
                           0000D4  1115 G$IC1MODE$0$0 == 0x00d4
                           0000D4  1116 _IC1MODE	=	0x00d4
                           0000D5  1117 G$IC1STATUS$0$0 == 0x00d5
                           0000D5  1118 _IC1STATUS	=	0x00d5
                           000092  1119 G$NVADDR0$0$0 == 0x0092
                           000092  1120 _NVADDR0	=	0x0092
                           000093  1121 G$NVADDR1$0$0 == 0x0093
                           000093  1122 _NVADDR1	=	0x0093
                           009392  1123 G$NVADDR$0$0 == 0x9392
                           009392  1124 _NVADDR	=	0x9392
                           000094  1125 G$NVDATA0$0$0 == 0x0094
                           000094  1126 _NVDATA0	=	0x0094
                           000095  1127 G$NVDATA1$0$0 == 0x0095
                           000095  1128 _NVDATA1	=	0x0095
                           009594  1129 G$NVDATA$0$0 == 0x9594
                           009594  1130 _NVDATA	=	0x9594
                           000096  1131 G$NVKEY$0$0 == 0x0096
                           000096  1132 _NVKEY	=	0x0096
                           000091  1133 G$NVSTATUS$0$0 == 0x0091
                           000091  1134 _NVSTATUS	=	0x0091
                           0000BC  1135 G$OC0COMP0$0$0 == 0x00bc
                           0000BC  1136 _OC0COMP0	=	0x00bc
                           0000BD  1137 G$OC0COMP1$0$0 == 0x00bd
                           0000BD  1138 _OC0COMP1	=	0x00bd
                           00BDBC  1139 G$OC0COMP$0$0 == 0xbdbc
                           00BDBC  1140 _OC0COMP	=	0xbdbc
                           0000B9  1141 G$OC0MODE$0$0 == 0x00b9
                           0000B9  1142 _OC0MODE	=	0x00b9
                           0000BA  1143 G$OC0PIN$0$0 == 0x00ba
                           0000BA  1144 _OC0PIN	=	0x00ba
                           0000BB  1145 G$OC0STATUS$0$0 == 0x00bb
                           0000BB  1146 _OC0STATUS	=	0x00bb
                           0000C4  1147 G$OC1COMP0$0$0 == 0x00c4
                           0000C4  1148 _OC1COMP0	=	0x00c4
                           0000C5  1149 G$OC1COMP1$0$0 == 0x00c5
                           0000C5  1150 _OC1COMP1	=	0x00c5
                           00C5C4  1151 G$OC1COMP$0$0 == 0xc5c4
                           00C5C4  1152 _OC1COMP	=	0xc5c4
                           0000C1  1153 G$OC1MODE$0$0 == 0x00c1
                           0000C1  1154 _OC1MODE	=	0x00c1
                           0000C2  1155 G$OC1PIN$0$0 == 0x00c2
                           0000C2  1156 _OC1PIN	=	0x00c2
                           0000C3  1157 G$OC1STATUS$0$0 == 0x00c3
                           0000C3  1158 _OC1STATUS	=	0x00c3
                           0000B1  1159 G$RADIOACC$0$0 == 0x00b1
                           0000B1  1160 _RADIOACC	=	0x00b1
                           0000B3  1161 G$RADIOADDR0$0$0 == 0x00b3
                           0000B3  1162 _RADIOADDR0	=	0x00b3
                           0000B2  1163 G$RADIOADDR1$0$0 == 0x00b2
                           0000B2  1164 _RADIOADDR1	=	0x00b2
                           00B2B3  1165 G$RADIOADDR$0$0 == 0xb2b3
                           00B2B3  1166 _RADIOADDR	=	0xb2b3
                           0000B7  1167 G$RADIODATA0$0$0 == 0x00b7
                           0000B7  1168 _RADIODATA0	=	0x00b7
                           0000B6  1169 G$RADIODATA1$0$0 == 0x00b6
                           0000B6  1170 _RADIODATA1	=	0x00b6
                           0000B5  1171 G$RADIODATA2$0$0 == 0x00b5
                           0000B5  1172 _RADIODATA2	=	0x00b5
                           0000B4  1173 G$RADIODATA3$0$0 == 0x00b4
                           0000B4  1174 _RADIODATA3	=	0x00b4
                           B4B5B6B7  1175 G$RADIODATA$0$0 == 0xb4b5b6b7
                           B4B5B6B7  1176 _RADIODATA	=	0xb4b5b6b7
                           0000BE  1177 G$RADIOSTAT0$0$0 == 0x00be
                           0000BE  1178 _RADIOSTAT0	=	0x00be
                           0000BF  1179 G$RADIOSTAT1$0$0 == 0x00bf
                           0000BF  1180 _RADIOSTAT1	=	0x00bf
                           00BFBE  1181 G$RADIOSTAT$0$0 == 0xbfbe
                           00BFBE  1182 _RADIOSTAT	=	0xbfbe
                           0000DF  1183 G$SPCLKSRC$0$0 == 0x00df
                           0000DF  1184 _SPCLKSRC	=	0x00df
                           0000DC  1185 G$SPMODE$0$0 == 0x00dc
                           0000DC  1186 _SPMODE	=	0x00dc
                           0000DE  1187 G$SPSHREG$0$0 == 0x00de
                           0000DE  1188 _SPSHREG	=	0x00de
                           0000DD  1189 G$SPSTATUS$0$0 == 0x00dd
                           0000DD  1190 _SPSTATUS	=	0x00dd
                           00009A  1191 G$T0CLKSRC$0$0 == 0x009a
                           00009A  1192 _T0CLKSRC	=	0x009a
                           00009C  1193 G$T0CNT0$0$0 == 0x009c
                           00009C  1194 _T0CNT0	=	0x009c
                           00009D  1195 G$T0CNT1$0$0 == 0x009d
                           00009D  1196 _T0CNT1	=	0x009d
                           009D9C  1197 G$T0CNT$0$0 == 0x9d9c
                           009D9C  1198 _T0CNT	=	0x9d9c
                           000099  1199 G$T0MODE$0$0 == 0x0099
                           000099  1200 _T0MODE	=	0x0099
                           00009E  1201 G$T0PERIOD0$0$0 == 0x009e
                           00009E  1202 _T0PERIOD0	=	0x009e
                           00009F  1203 G$T0PERIOD1$0$0 == 0x009f
                           00009F  1204 _T0PERIOD1	=	0x009f
                           009F9E  1205 G$T0PERIOD$0$0 == 0x9f9e
                           009F9E  1206 _T0PERIOD	=	0x9f9e
                           00009B  1207 G$T0STATUS$0$0 == 0x009b
                           00009B  1208 _T0STATUS	=	0x009b
                           0000A2  1209 G$T1CLKSRC$0$0 == 0x00a2
                           0000A2  1210 _T1CLKSRC	=	0x00a2
                           0000A4  1211 G$T1CNT0$0$0 == 0x00a4
                           0000A4  1212 _T1CNT0	=	0x00a4
                           0000A5  1213 G$T1CNT1$0$0 == 0x00a5
                           0000A5  1214 _T1CNT1	=	0x00a5
                           00A5A4  1215 G$T1CNT$0$0 == 0xa5a4
                           00A5A4  1216 _T1CNT	=	0xa5a4
                           0000A1  1217 G$T1MODE$0$0 == 0x00a1
                           0000A1  1218 _T1MODE	=	0x00a1
                           0000A6  1219 G$T1PERIOD0$0$0 == 0x00a6
                           0000A6  1220 _T1PERIOD0	=	0x00a6
                           0000A7  1221 G$T1PERIOD1$0$0 == 0x00a7
                           0000A7  1222 _T1PERIOD1	=	0x00a7
                           00A7A6  1223 G$T1PERIOD$0$0 == 0xa7a6
                           00A7A6  1224 _T1PERIOD	=	0xa7a6
                           0000A3  1225 G$T1STATUS$0$0 == 0x00a3
                           0000A3  1226 _T1STATUS	=	0x00a3
                           0000AA  1227 G$T2CLKSRC$0$0 == 0x00aa
                           0000AA  1228 _T2CLKSRC	=	0x00aa
                           0000AC  1229 G$T2CNT0$0$0 == 0x00ac
                           0000AC  1230 _T2CNT0	=	0x00ac
                           0000AD  1231 G$T2CNT1$0$0 == 0x00ad
                           0000AD  1232 _T2CNT1	=	0x00ad
                           00ADAC  1233 G$T2CNT$0$0 == 0xadac
                           00ADAC  1234 _T2CNT	=	0xadac
                           0000A9  1235 G$T2MODE$0$0 == 0x00a9
                           0000A9  1236 _T2MODE	=	0x00a9
                           0000AE  1237 G$T2PERIOD0$0$0 == 0x00ae
                           0000AE  1238 _T2PERIOD0	=	0x00ae
                           0000AF  1239 G$T2PERIOD1$0$0 == 0x00af
                           0000AF  1240 _T2PERIOD1	=	0x00af
                           00AFAE  1241 G$T2PERIOD$0$0 == 0xafae
                           00AFAE  1242 _T2PERIOD	=	0xafae
                           0000AB  1243 G$T2STATUS$0$0 == 0x00ab
                           0000AB  1244 _T2STATUS	=	0x00ab
                           0000E4  1245 G$U0CTRL$0$0 == 0x00e4
                           0000E4  1246 _U0CTRL	=	0x00e4
                           0000E7  1247 G$U0MODE$0$0 == 0x00e7
                           0000E7  1248 _U0MODE	=	0x00e7
                           0000E6  1249 G$U0SHREG$0$0 == 0x00e6
                           0000E6  1250 _U0SHREG	=	0x00e6
                           0000E5  1251 G$U0STATUS$0$0 == 0x00e5
                           0000E5  1252 _U0STATUS	=	0x00e5
                           0000EC  1253 G$U1CTRL$0$0 == 0x00ec
                           0000EC  1254 _U1CTRL	=	0x00ec
                           0000EF  1255 G$U1MODE$0$0 == 0x00ef
                           0000EF  1256 _U1MODE	=	0x00ef
                           0000EE  1257 G$U1SHREG$0$0 == 0x00ee
                           0000EE  1258 _U1SHREG	=	0x00ee
                           0000ED  1259 G$U1STATUS$0$0 == 0x00ed
                           0000ED  1260 _U1STATUS	=	0x00ed
                           0000DA  1261 G$WDTCFG$0$0 == 0x00da
                           0000DA  1262 _WDTCFG	=	0x00da
                           0000DB  1263 G$WDTRESET$0$0 == 0x00db
                           0000DB  1264 _WDTRESET	=	0x00db
                           0000F1  1265 G$WTCFGA$0$0 == 0x00f1
                           0000F1  1266 _WTCFGA	=	0x00f1
                           0000F9  1267 G$WTCFGB$0$0 == 0x00f9
                           0000F9  1268 _WTCFGB	=	0x00f9
                           0000F2  1269 G$WTCNTA0$0$0 == 0x00f2
                           0000F2  1270 _WTCNTA0	=	0x00f2
                           0000F3  1271 G$WTCNTA1$0$0 == 0x00f3
                           0000F3  1272 _WTCNTA1	=	0x00f3
                           00F3F2  1273 G$WTCNTA$0$0 == 0xf3f2
                           00F3F2  1274 _WTCNTA	=	0xf3f2
                           0000FA  1275 G$WTCNTB0$0$0 == 0x00fa
                           0000FA  1276 _WTCNTB0	=	0x00fa
                           0000FB  1277 G$WTCNTB1$0$0 == 0x00fb
                           0000FB  1278 _WTCNTB1	=	0x00fb
                           00FBFA  1279 G$WTCNTB$0$0 == 0xfbfa
                           00FBFA  1280 _WTCNTB	=	0xfbfa
                           0000EB  1281 G$WTCNTR1$0$0 == 0x00eb
                           0000EB  1282 _WTCNTR1	=	0x00eb
                           0000F4  1283 G$WTEVTA0$0$0 == 0x00f4
                           0000F4  1284 _WTEVTA0	=	0x00f4
                           0000F5  1285 G$WTEVTA1$0$0 == 0x00f5
                           0000F5  1286 _WTEVTA1	=	0x00f5
                           00F5F4  1287 G$WTEVTA$0$0 == 0xf5f4
                           00F5F4  1288 _WTEVTA	=	0xf5f4
                           0000F6  1289 G$WTEVTB0$0$0 == 0x00f6
                           0000F6  1290 _WTEVTB0	=	0x00f6
                           0000F7  1291 G$WTEVTB1$0$0 == 0x00f7
                           0000F7  1292 _WTEVTB1	=	0x00f7
                           00F7F6  1293 G$WTEVTB$0$0 == 0xf7f6
                           00F7F6  1294 _WTEVTB	=	0xf7f6
                           0000FC  1295 G$WTEVTC0$0$0 == 0x00fc
                           0000FC  1296 _WTEVTC0	=	0x00fc
                           0000FD  1297 G$WTEVTC1$0$0 == 0x00fd
                           0000FD  1298 _WTEVTC1	=	0x00fd
                           00FDFC  1299 G$WTEVTC$0$0 == 0xfdfc
                           00FDFC  1300 _WTEVTC	=	0xfdfc
                           0000FE  1301 G$WTEVTD0$0$0 == 0x00fe
                           0000FE  1302 _WTEVTD0	=	0x00fe
                           0000FF  1303 G$WTEVTD1$0$0 == 0x00ff
                           0000FF  1304 _WTEVTD1	=	0x00ff
                           00FFFE  1305 G$WTEVTD$0$0 == 0xfffe
                           00FFFE  1306 _WTEVTD	=	0xfffe
                           0000E9  1307 G$WTIRQEN$0$0 == 0x00e9
                           0000E9  1308 _WTIRQEN	=	0x00e9
                           0000EA  1309 G$WTSTAT$0$0 == 0x00ea
                           0000EA  1310 _WTSTAT	=	0x00ea
                                   1311 ;--------------------------------------------------------
                                   1312 ; special function bits
                                   1313 ;--------------------------------------------------------
                                   1314 	.area RSEG    (ABS,DATA)
      000000                       1315 	.org 0x0000
                           0000E0  1316 G$ACC_0$0$0 == 0x00e0
                           0000E0  1317 _ACC_0	=	0x00e0
                           0000E1  1318 G$ACC_1$0$0 == 0x00e1
                           0000E1  1319 _ACC_1	=	0x00e1
                           0000E2  1320 G$ACC_2$0$0 == 0x00e2
                           0000E2  1321 _ACC_2	=	0x00e2
                           0000E3  1322 G$ACC_3$0$0 == 0x00e3
                           0000E3  1323 _ACC_3	=	0x00e3
                           0000E4  1324 G$ACC_4$0$0 == 0x00e4
                           0000E4  1325 _ACC_4	=	0x00e4
                           0000E5  1326 G$ACC_5$0$0 == 0x00e5
                           0000E5  1327 _ACC_5	=	0x00e5
                           0000E6  1328 G$ACC_6$0$0 == 0x00e6
                           0000E6  1329 _ACC_6	=	0x00e6
                           0000E7  1330 G$ACC_7$0$0 == 0x00e7
                           0000E7  1331 _ACC_7	=	0x00e7
                           0000F0  1332 G$B_0$0$0 == 0x00f0
                           0000F0  1333 _B_0	=	0x00f0
                           0000F1  1334 G$B_1$0$0 == 0x00f1
                           0000F1  1335 _B_1	=	0x00f1
                           0000F2  1336 G$B_2$0$0 == 0x00f2
                           0000F2  1337 _B_2	=	0x00f2
                           0000F3  1338 G$B_3$0$0 == 0x00f3
                           0000F3  1339 _B_3	=	0x00f3
                           0000F4  1340 G$B_4$0$0 == 0x00f4
                           0000F4  1341 _B_4	=	0x00f4
                           0000F5  1342 G$B_5$0$0 == 0x00f5
                           0000F5  1343 _B_5	=	0x00f5
                           0000F6  1344 G$B_6$0$0 == 0x00f6
                           0000F6  1345 _B_6	=	0x00f6
                           0000F7  1346 G$B_7$0$0 == 0x00f7
                           0000F7  1347 _B_7	=	0x00f7
                           0000A0  1348 G$E2IE_0$0$0 == 0x00a0
                           0000A0  1349 _E2IE_0	=	0x00a0
                           0000A1  1350 G$E2IE_1$0$0 == 0x00a1
                           0000A1  1351 _E2IE_1	=	0x00a1
                           0000A2  1352 G$E2IE_2$0$0 == 0x00a2
                           0000A2  1353 _E2IE_2	=	0x00a2
                           0000A3  1354 G$E2IE_3$0$0 == 0x00a3
                           0000A3  1355 _E2IE_3	=	0x00a3
                           0000A4  1356 G$E2IE_4$0$0 == 0x00a4
                           0000A4  1357 _E2IE_4	=	0x00a4
                           0000A5  1358 G$E2IE_5$0$0 == 0x00a5
                           0000A5  1359 _E2IE_5	=	0x00a5
                           0000A6  1360 G$E2IE_6$0$0 == 0x00a6
                           0000A6  1361 _E2IE_6	=	0x00a6
                           0000A7  1362 G$E2IE_7$0$0 == 0x00a7
                           0000A7  1363 _E2IE_7	=	0x00a7
                           0000C0  1364 G$E2IP_0$0$0 == 0x00c0
                           0000C0  1365 _E2IP_0	=	0x00c0
                           0000C1  1366 G$E2IP_1$0$0 == 0x00c1
                           0000C1  1367 _E2IP_1	=	0x00c1
                           0000C2  1368 G$E2IP_2$0$0 == 0x00c2
                           0000C2  1369 _E2IP_2	=	0x00c2
                           0000C3  1370 G$E2IP_3$0$0 == 0x00c3
                           0000C3  1371 _E2IP_3	=	0x00c3
                           0000C4  1372 G$E2IP_4$0$0 == 0x00c4
                           0000C4  1373 _E2IP_4	=	0x00c4
                           0000C5  1374 G$E2IP_5$0$0 == 0x00c5
                           0000C5  1375 _E2IP_5	=	0x00c5
                           0000C6  1376 G$E2IP_6$0$0 == 0x00c6
                           0000C6  1377 _E2IP_6	=	0x00c6
                           0000C7  1378 G$E2IP_7$0$0 == 0x00c7
                           0000C7  1379 _E2IP_7	=	0x00c7
                           000098  1380 G$EIE_0$0$0 == 0x0098
                           000098  1381 _EIE_0	=	0x0098
                           000099  1382 G$EIE_1$0$0 == 0x0099
                           000099  1383 _EIE_1	=	0x0099
                           00009A  1384 G$EIE_2$0$0 == 0x009a
                           00009A  1385 _EIE_2	=	0x009a
                           00009B  1386 G$EIE_3$0$0 == 0x009b
                           00009B  1387 _EIE_3	=	0x009b
                           00009C  1388 G$EIE_4$0$0 == 0x009c
                           00009C  1389 _EIE_4	=	0x009c
                           00009D  1390 G$EIE_5$0$0 == 0x009d
                           00009D  1391 _EIE_5	=	0x009d
                           00009E  1392 G$EIE_6$0$0 == 0x009e
                           00009E  1393 _EIE_6	=	0x009e
                           00009F  1394 G$EIE_7$0$0 == 0x009f
                           00009F  1395 _EIE_7	=	0x009f
                           0000B0  1396 G$EIP_0$0$0 == 0x00b0
                           0000B0  1397 _EIP_0	=	0x00b0
                           0000B1  1398 G$EIP_1$0$0 == 0x00b1
                           0000B1  1399 _EIP_1	=	0x00b1
                           0000B2  1400 G$EIP_2$0$0 == 0x00b2
                           0000B2  1401 _EIP_2	=	0x00b2
                           0000B3  1402 G$EIP_3$0$0 == 0x00b3
                           0000B3  1403 _EIP_3	=	0x00b3
                           0000B4  1404 G$EIP_4$0$0 == 0x00b4
                           0000B4  1405 _EIP_4	=	0x00b4
                           0000B5  1406 G$EIP_5$0$0 == 0x00b5
                           0000B5  1407 _EIP_5	=	0x00b5
                           0000B6  1408 G$EIP_6$0$0 == 0x00b6
                           0000B6  1409 _EIP_6	=	0x00b6
                           0000B7  1410 G$EIP_7$0$0 == 0x00b7
                           0000B7  1411 _EIP_7	=	0x00b7
                           0000A8  1412 G$IE_0$0$0 == 0x00a8
                           0000A8  1413 _IE_0	=	0x00a8
                           0000A9  1414 G$IE_1$0$0 == 0x00a9
                           0000A9  1415 _IE_1	=	0x00a9
                           0000AA  1416 G$IE_2$0$0 == 0x00aa
                           0000AA  1417 _IE_2	=	0x00aa
                           0000AB  1418 G$IE_3$0$0 == 0x00ab
                           0000AB  1419 _IE_3	=	0x00ab
                           0000AC  1420 G$IE_4$0$0 == 0x00ac
                           0000AC  1421 _IE_4	=	0x00ac
                           0000AD  1422 G$IE_5$0$0 == 0x00ad
                           0000AD  1423 _IE_5	=	0x00ad
                           0000AE  1424 G$IE_6$0$0 == 0x00ae
                           0000AE  1425 _IE_6	=	0x00ae
                           0000AF  1426 G$IE_7$0$0 == 0x00af
                           0000AF  1427 _IE_7	=	0x00af
                           0000AF  1428 G$EA$0$0 == 0x00af
                           0000AF  1429 _EA	=	0x00af
                           0000B8  1430 G$IP_0$0$0 == 0x00b8
                           0000B8  1431 _IP_0	=	0x00b8
                           0000B9  1432 G$IP_1$0$0 == 0x00b9
                           0000B9  1433 _IP_1	=	0x00b9
                           0000BA  1434 G$IP_2$0$0 == 0x00ba
                           0000BA  1435 _IP_2	=	0x00ba
                           0000BB  1436 G$IP_3$0$0 == 0x00bb
                           0000BB  1437 _IP_3	=	0x00bb
                           0000BC  1438 G$IP_4$0$0 == 0x00bc
                           0000BC  1439 _IP_4	=	0x00bc
                           0000BD  1440 G$IP_5$0$0 == 0x00bd
                           0000BD  1441 _IP_5	=	0x00bd
                           0000BE  1442 G$IP_6$0$0 == 0x00be
                           0000BE  1443 _IP_6	=	0x00be
                           0000BF  1444 G$IP_7$0$0 == 0x00bf
                           0000BF  1445 _IP_7	=	0x00bf
                           0000D0  1446 G$P$0$0 == 0x00d0
                           0000D0  1447 _P	=	0x00d0
                           0000D1  1448 G$F1$0$0 == 0x00d1
                           0000D1  1449 _F1	=	0x00d1
                           0000D2  1450 G$OV$0$0 == 0x00d2
                           0000D2  1451 _OV	=	0x00d2
                           0000D3  1452 G$RS0$0$0 == 0x00d3
                           0000D3  1453 _RS0	=	0x00d3
                           0000D4  1454 G$RS1$0$0 == 0x00d4
                           0000D4  1455 _RS1	=	0x00d4
                           0000D5  1456 G$F0$0$0 == 0x00d5
                           0000D5  1457 _F0	=	0x00d5
                           0000D6  1458 G$AC$0$0 == 0x00d6
                           0000D6  1459 _AC	=	0x00d6
                           0000D7  1460 G$CY$0$0 == 0x00d7
                           0000D7  1461 _CY	=	0x00d7
                           0000C8  1462 G$PINA_0$0$0 == 0x00c8
                           0000C8  1463 _PINA_0	=	0x00c8
                           0000C9  1464 G$PINA_1$0$0 == 0x00c9
                           0000C9  1465 _PINA_1	=	0x00c9
                           0000CA  1466 G$PINA_2$0$0 == 0x00ca
                           0000CA  1467 _PINA_2	=	0x00ca
                           0000CB  1468 G$PINA_3$0$0 == 0x00cb
                           0000CB  1469 _PINA_3	=	0x00cb
                           0000CC  1470 G$PINA_4$0$0 == 0x00cc
                           0000CC  1471 _PINA_4	=	0x00cc
                           0000CD  1472 G$PINA_5$0$0 == 0x00cd
                           0000CD  1473 _PINA_5	=	0x00cd
                           0000CE  1474 G$PINA_6$0$0 == 0x00ce
                           0000CE  1475 _PINA_6	=	0x00ce
                           0000CF  1476 G$PINA_7$0$0 == 0x00cf
                           0000CF  1477 _PINA_7	=	0x00cf
                           0000E8  1478 G$PINB_0$0$0 == 0x00e8
                           0000E8  1479 _PINB_0	=	0x00e8
                           0000E9  1480 G$PINB_1$0$0 == 0x00e9
                           0000E9  1481 _PINB_1	=	0x00e9
                           0000EA  1482 G$PINB_2$0$0 == 0x00ea
                           0000EA  1483 _PINB_2	=	0x00ea
                           0000EB  1484 G$PINB_3$0$0 == 0x00eb
                           0000EB  1485 _PINB_3	=	0x00eb
                           0000EC  1486 G$PINB_4$0$0 == 0x00ec
                           0000EC  1487 _PINB_4	=	0x00ec
                           0000ED  1488 G$PINB_5$0$0 == 0x00ed
                           0000ED  1489 _PINB_5	=	0x00ed
                           0000EE  1490 G$PINB_6$0$0 == 0x00ee
                           0000EE  1491 _PINB_6	=	0x00ee
                           0000EF  1492 G$PINB_7$0$0 == 0x00ef
                           0000EF  1493 _PINB_7	=	0x00ef
                           0000F8  1494 G$PINC_0$0$0 == 0x00f8
                           0000F8  1495 _PINC_0	=	0x00f8
                           0000F9  1496 G$PINC_1$0$0 == 0x00f9
                           0000F9  1497 _PINC_1	=	0x00f9
                           0000FA  1498 G$PINC_2$0$0 == 0x00fa
                           0000FA  1499 _PINC_2	=	0x00fa
                           0000FB  1500 G$PINC_3$0$0 == 0x00fb
                           0000FB  1501 _PINC_3	=	0x00fb
                           0000FC  1502 G$PINC_4$0$0 == 0x00fc
                           0000FC  1503 _PINC_4	=	0x00fc
                           0000FD  1504 G$PINC_5$0$0 == 0x00fd
                           0000FD  1505 _PINC_5	=	0x00fd
                           0000FE  1506 G$PINC_6$0$0 == 0x00fe
                           0000FE  1507 _PINC_6	=	0x00fe
                           0000FF  1508 G$PINC_7$0$0 == 0x00ff
                           0000FF  1509 _PINC_7	=	0x00ff
                           000080  1510 G$PORTA_0$0$0 == 0x0080
                           000080  1511 _PORTA_0	=	0x0080
                           000081  1512 G$PORTA_1$0$0 == 0x0081
                           000081  1513 _PORTA_1	=	0x0081
                           000082  1514 G$PORTA_2$0$0 == 0x0082
                           000082  1515 _PORTA_2	=	0x0082
                           000083  1516 G$PORTA_3$0$0 == 0x0083
                           000083  1517 _PORTA_3	=	0x0083
                           000084  1518 G$PORTA_4$0$0 == 0x0084
                           000084  1519 _PORTA_4	=	0x0084
                           000085  1520 G$PORTA_5$0$0 == 0x0085
                           000085  1521 _PORTA_5	=	0x0085
                           000086  1522 G$PORTA_6$0$0 == 0x0086
                           000086  1523 _PORTA_6	=	0x0086
                           000087  1524 G$PORTA_7$0$0 == 0x0087
                           000087  1525 _PORTA_7	=	0x0087
                           000088  1526 G$PORTB_0$0$0 == 0x0088
                           000088  1527 _PORTB_0	=	0x0088
                           000089  1528 G$PORTB_1$0$0 == 0x0089
                           000089  1529 _PORTB_1	=	0x0089
                           00008A  1530 G$PORTB_2$0$0 == 0x008a
                           00008A  1531 _PORTB_2	=	0x008a
                           00008B  1532 G$PORTB_3$0$0 == 0x008b
                           00008B  1533 _PORTB_3	=	0x008b
                           00008C  1534 G$PORTB_4$0$0 == 0x008c
                           00008C  1535 _PORTB_4	=	0x008c
                           00008D  1536 G$PORTB_5$0$0 == 0x008d
                           00008D  1537 _PORTB_5	=	0x008d
                           00008E  1538 G$PORTB_6$0$0 == 0x008e
                           00008E  1539 _PORTB_6	=	0x008e
                           00008F  1540 G$PORTB_7$0$0 == 0x008f
                           00008F  1541 _PORTB_7	=	0x008f
                           000090  1542 G$PORTC_0$0$0 == 0x0090
                           000090  1543 _PORTC_0	=	0x0090
                           000091  1544 G$PORTC_1$0$0 == 0x0091
                           000091  1545 _PORTC_1	=	0x0091
                           000092  1546 G$PORTC_2$0$0 == 0x0092
                           000092  1547 _PORTC_2	=	0x0092
                           000093  1548 G$PORTC_3$0$0 == 0x0093
                           000093  1549 _PORTC_3	=	0x0093
                           000094  1550 G$PORTC_4$0$0 == 0x0094
                           000094  1551 _PORTC_4	=	0x0094
                           000095  1552 G$PORTC_5$0$0 == 0x0095
                           000095  1553 _PORTC_5	=	0x0095
                           000096  1554 G$PORTC_6$0$0 == 0x0096
                           000096  1555 _PORTC_6	=	0x0096
                           000097  1556 G$PORTC_7$0$0 == 0x0097
                           000097  1557 _PORTC_7	=	0x0097
                                   1558 ;--------------------------------------------------------
                                   1559 ; overlayable register banks
                                   1560 ;--------------------------------------------------------
                                   1561 	.area REG_BANK_0	(REL,OVR,DATA)
      000000                       1562 	.ds 8
                                   1563 ;--------------------------------------------------------
                                   1564 ; internal ram data
                                   1565 ;--------------------------------------------------------
                                   1566 	.area DSEG    (DATA)
                                   1567 ;--------------------------------------------------------
                                   1568 ; overlayable items in internal ram 
                                   1569 ;--------------------------------------------------------
                                   1570 ;--------------------------------------------------------
                                   1571 ; indirectly addressable internal ram data
                                   1572 ;--------------------------------------------------------
                                   1573 	.area ISEG    (DATA)
                                   1574 ;--------------------------------------------------------
                                   1575 ; absolute internal ram data
                                   1576 ;--------------------------------------------------------
                                   1577 	.area IABS    (ABS,DATA)
                                   1578 	.area IABS    (ABS,DATA)
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

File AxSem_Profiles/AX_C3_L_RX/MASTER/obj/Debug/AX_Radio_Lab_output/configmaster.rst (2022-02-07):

                                      1 ;--------------------------------------------------------
                                      2 ; File Created by SDCC : free open source ANSI-C Compiler
                                      3 ; Version 3.6.0 #9615 (MINGW64)
                                      4 ;--------------------------------------------------------
                                      5 	.module configmaster
                                      6 	.optsdcc -mmcs51 --model-small
                                      7 	
                                      8 ;--------------------------------------------------------
                                      9 ; Public variables in this module
                                     10 ;--------------------------------------------------------
                                     11 	.globl _lpxosc_settlingtime
                                     12 	.globl _demo_packet
                                     13 	.globl _framing_counter_pos
                                     14 	.globl _framing_insert_counter
                                     15 	.globl _localaddr
                                     16 	.globl _remoteaddr
                                     17 	.globl _PORTC_7
                                     18 	.globl _PORTC_6
                                     19 	.globl _PORTC_5
                                     20 	.globl _PORTC_4
                                     21 	.globl _PORTC_3
                                     22 	.globl _PORTC_2
                                     23 	.globl _PORTC_1
                                     24 	.globl _PORTC_0
                                     25 	.globl _PORTB_7
                                     26 	.globl _PORTB_6
                                     27 	.globl _PORTB_5
                                     28 	.globl _PORTB_4
                                     29 	.globl _PORTB_3
                                     30 	.globl _PORTB_2
                                     31 	.globl _PORTB_1
                                     32 	.globl _PORTB_0
                                     33 	.globl _PORTA_7
                                     34 	.globl _PORTA_6
                                     35 	.globl _PORTA_5
                                     36 	.globl _PORTA_4
                                     37 	.globl _PORTA_3
                                     38 	.globl _PORTA_2
                                     39 	.globl _PORTA_1
                                     40 	.globl _PORTA_0
                                     41 	.globl _PINC_7
                                     42 	.globl _PINC_6
                                     43 	.globl _PINC_5
                                     44 	.globl _PINC_4
                                     45 	.globl _PINC_3
                                     46 	.globl _PINC_2
                                     47 	.globl _PINC_1
                                     48 	.globl _PINC_0
                                     49 	.globl _PINB_7
                                     50 	.globl _PINB_6
                                     51 	.globl _PINB_5
                                     52 	.globl _PINB_4
                                     53 	.globl _PINB_3
                                     54 	.globl _PINB_2
                                     55 	.globl _PINB_1
                                     56 	.globl _PINB_0
                                     57 	.globl _PINA_7
                                     58 	.globl _PINA_6
                                     59 	.globl _PINA_5
                                     60 	.globl _PINA_4
                                     61 	.globl _PINA_3
                                     62 	.globl _PINA_2
                                     63 	.globl _PINA_1
                                     64 	.globl _PINA_0
                                     65 	.globl _CY
                                     66 	.globl _AC
                                     67 	.globl _F0
                                     68 	.globl _RS1
                                     69 	.globl _RS0
                                     70 	.globl _OV
                                     71 	.globl _F1
                                     72 	.globl _P
                                     73 	.globl _IP_7
                                     74 	.globl _IP_6
                                     75 	.globl _IP_5
                                     76 	.globl _IP_4
                                     77 	.globl _IP_3
                                     78 	.globl _IP_2
                                     79 	.globl _IP_1
                                     80 	.globl _IP_0
                                     81 	.globl _EA
                                     82 	.globl _IE_7
                                     83 	.globl _IE_6
                                     84 	.globl _IE_5
                                     85 	.globl _IE_4
                                     86 	.globl _IE_3
                                     87 	.globl _IE_2
                                     88 	.globl _IE_1
                                     89 	.globl _IE_0
                                     90 	.globl _EIP_7
                                     91 	.globl _EIP_6
                                     92 	.globl _EIP_5
                                     93 	.globl _EIP_4
                                     94 	.globl _EIP_3
                                     95 	.globl _EIP_2
                                     96 	.globl _EIP_1
                                     97 	.globl _EIP_0
                                     98 	.globl _EIE_7
                                     99 	.globl _EIE_6
                                    100 	.globl _EIE_5
                                    101 	.globl _EIE_4
                                    102 	.globl _EIE_3
                                    103 	.globl _EIE_2
                                    104 	.globl _EIE_1
                                    105 	.globl _EIE_0
                                    106 	.globl _E2IP_7
                                    107 	.globl _E2IP_6
                                    108 	.globl _E2IP_5
                                    109 	.globl _E2IP_4
                                    110 	.globl _E2IP_3
                                    111 	.globl _E2IP_2
                                    112 	.globl _E2IP_1
                                    113 	.globl _E2IP_0
                                    114 	.globl _E2IE_7
                                    115 	.globl _E2IE_6
                                    116 	.globl _E2IE_5
                                    117 	.globl _E2IE_4
                                    118 	.globl _E2IE_3
                                    119 	.globl _E2IE_2
                                    120 	.globl _E2IE_1
                                    121 	.globl _E2IE_0
                                    122 	.globl _B_7
                                    123 	.globl _B_6
                                    124 	.globl _B_5
                                    125 	.globl _B_4
                                    126 	.globl _B_3
                                    127 	.globl _B_2
                                    128 	.globl _B_1
                                    129 	.globl _B_0
                                    130 	.globl _ACC_7
                                    131 	.globl _ACC_6
                                    132 	.globl _ACC_5
                                    133 	.globl _ACC_4
                                    134 	.globl _ACC_3
                                    135 	.globl _ACC_2
                                    136 	.globl _ACC_1
                                    137 	.globl _ACC_0
                                    138 	.globl _WTSTAT
                                    139 	.globl _WTIRQEN
                                    140 	.globl _WTEVTD
                                    141 	.globl _WTEVTD1
                                    142 	.globl _WTEVTD0
                                    143 	.globl _WTEVTC
                                    144 	.globl _WTEVTC1
                                    145 	.globl _WTEVTC0
                                    146 	.globl _WTEVTB
                                    147 	.globl _WTEVTB1
                                    148 	.globl _WTEVTB0
                                    149 	.globl _WTEVTA
                                    150 	.globl _WTEVTA1
                                    151 	.globl _WTEVTA0
                                    152 	.globl _WTCNTR1
                                    153 	.globl _WTCNTB
                                    154 	.globl _WTCNTB1
                                    155 	.globl _WTCNTB0
                                    156 	.globl _WTCNTA
                                    157 	.globl _WTCNTA1
                                    158 	.globl _WTCNTA0
                                    159 	.globl _WTCFGB
                                    160 	.globl _WTCFGA
                                    161 	.globl _WDTRESET
                                    162 	.globl _WDTCFG
                                    163 	.globl _U1STATUS
                                    164 	.globl _U1SHREG
                                    165 	.globl _U1MODE
                                    166 	.globl _U1CTRL
                                    167 	.globl _U0STATUS
                                    168 	.globl _U0SHREG
                                    169 	.globl _U0MODE
                                    170 	.globl _U0CTRL
                                    171 	.globl _T2STATUS
                                    172 	.globl _T2PERIOD
                                    173 	.globl _T2PERIOD1
                                    174 	.globl _T2PERIOD0
                                    175 	.globl _T2MODE
                                    176 	.globl _T2CNT
                                    177 	.globl _T2CNT1
                                    178 	.globl _T2CNT0
                                    179 	.globl _T2CLKSRC
                                    180 	.globl _T1STATUS
                                    181 	.globl _T1PERIOD
                                    182 	.globl _T1PERIOD1
                                    183 	.globl _T1PERIOD0
                                    184 	.globl _T1MODE
                                    185 	.globl _T1CNT
                                    186 	.globl _T1CNT1
                                    187 	.globl _T1CNT0
                                    188 	.globl _T1CLKSRC
                                    189 	.globl _T0STATUS
                                    190 	.globl _T0PERIOD
                                    191 	.globl _T0PERIOD1
                                    192 	.globl _T0PERIOD0
                                    193 	.globl _T0MODE
                                    194 	.globl _T0CNT
                                    195 	.globl _T0CNT1
                                    196 	.globl _T0CNT0
                                    197 	.globl _T0CLKSRC
                                    198 	.globl _SPSTATUS
                                    199 	.globl _SPSHREG
                                    200 	.globl _SPMODE
                                    201 	.globl _SPCLKSRC
                                    202 	.globl _RADIOSTAT
                                    203 	.globl _RADIOSTAT1
                                    204 	.globl _RADIOSTAT0
                                    205 	.globl _RADIODATA
                                    206 	.globl _RADIODATA3
                                    207 	.globl _RADIODATA2
                                    208 	.globl _RADIODATA1
                                    209 	.globl _RADIODATA0
                                    210 	.globl _RADIOADDR
                                    211 	.globl _RADIOADDR1
                                    212 	.globl _RADIOADDR0
                                    213 	.globl _RADIOACC
                                    214 	.globl _OC1STATUS
                                    215 	.globl _OC1PIN
                                    216 	.globl _OC1MODE
                                    217 	.globl _OC1COMP
                                    218 	.globl _OC1COMP1
                                    219 	.globl _OC1COMP0
                                    220 	.globl _OC0STATUS
                                    221 	.globl _OC0PIN
                                    222 	.globl _OC0MODE
                                    223 	.globl _OC0COMP
                                    224 	.globl _OC0COMP1
                                    225 	.globl _OC0COMP0
                                    226 	.globl _NVSTATUS
                                    227 	.globl _NVKEY
                                    228 	.globl _NVDATA
                                    229 	.globl _NVDATA1
                                    230 	.globl _NVDATA0
                                    231 	.globl _NVADDR
                                    232 	.globl _NVADDR1
                                    233 	.globl _NVADDR0
                                    234 	.globl _IC1STATUS
                                    235 	.globl _IC1MODE
                                    236 	.globl _IC1CAPT
                                    237 	.globl _IC1CAPT1
                                    238 	.globl _IC1CAPT0
                                    239 	.globl _IC0STATUS
                                    240 	.globl _IC0MODE
                                    241 	.globl _IC0CAPT
                                    242 	.globl _IC0CAPT1
                                    243 	.globl _IC0CAPT0
                                    244 	.globl _PORTR
                                    245 	.globl _PORTC
                                    246 	.globl _PORTB
                                    247 	.globl _PORTA
                                    248 	.globl _PINR
                                    249 	.globl _PINC
                                    250 	.globl _PINB
                                    251 	.globl _PINA
                                    252 	.globl _DIRR
                                    253 	.globl _DIRC
                                    254 	.globl _DIRB
                                    255 	.globl _DIRA
                                    256 	.globl _DBGLNKSTAT
                                    257 	.globl _DBGLNKBUF
                                    258 	.globl _CODECONFIG
                                    259 	.globl _CLKSTAT
                                    260 	.globl _CLKCON
                                    261 	.globl _ANALOGCOMP
                                    262 	.globl _ADCCONV
                                    263 	.globl _ADCCLKSRC
                                    264 	.globl _ADCCH3CONFIG
                                    265 	.globl _ADCCH2CONFIG
                                    266 	.globl _ADCCH1CONFIG
                                    267 	.globl _ADCCH0CONFIG
                                    268 	.globl __XPAGE
                                    269 	.globl _XPAGE
                                    270 	.globl _SP
                                    271 	.globl _PSW
                                    272 	.globl _PCON
                                    273 	.globl _IP
                                    274 	.globl _IE
                                    275 	.globl _EIP
                                    276 	.globl _EIE
                                    277 	.globl _E2IP
                                    278 	.globl _E2IE
                                    279 	.globl _DPS
                                    280 	.globl _DPTR1
                                    281 	.globl _DPTR0
                                    282 	.globl _DPL1
                                    283 	.globl _DPL
                                    284 	.globl _DPH1
                                    285 	.globl _DPH
                                    286 	.globl _B
                                    287 	.globl _ACC
                                    288 	.globl _XTALREADY
                                    289 	.globl _XTALOSC
                                    290 	.globl _XTALAMPL
                                    291 	.globl _SILICONREV
                                    292 	.globl _SCRATCH3
                                    293 	.globl _SCRATCH2
                                    294 	.globl _SCRATCH1
                                    295 	.globl _SCRATCH0
                                    296 	.globl _RADIOMUX
                                    297 	.globl _RADIOFSTATADDR
                                    298 	.globl _RADIOFSTATADDR1
                                    299 	.globl _RADIOFSTATADDR0
                                    300 	.globl _RADIOFDATAADDR
                                    301 	.globl _RADIOFDATAADDR1
                                    302 	.globl _RADIOFDATAADDR0
                                    303 	.globl _OSCRUN
                                    304 	.globl _OSCREADY
                                    305 	.globl _OSCFORCERUN
                                    306 	.globl _OSCCALIB
                                    307 	.globl _MISCCTRL
                                    308 	.globl _LPXOSCGM
                                    309 	.globl _LPOSCREF
                                    310 	.globl _LPOSCREF1
                                    311 	.globl _LPOSCREF0
                                    312 	.globl _LPOSCPER
                                    313 	.globl _LPOSCPER1
                                    314 	.globl _LPOSCPER0
                                    315 	.globl _LPOSCKFILT
                                    316 	.globl _LPOSCKFILT1
                                    317 	.globl _LPOSCKFILT0
                                    318 	.globl _LPOSCFREQ
                                    319 	.globl _LPOSCFREQ1
                                    320 	.globl _LPOSCFREQ0
                                    321 	.globl _LPOSCCONFIG
                                    322 	.globl _PINSEL
                                    323 	.globl _PINCHGC
                                    324 	.globl _PINCHGB
                                    325 	.globl _PINCHGA
                                    326 	.globl _PALTRADIO
                                    327 	.globl _PALTC
                                    328 	.globl _PALTB
                                    329 	.globl _PALTA
                                    330 	.globl _INTCHGC
                                    331 	.globl _INTCHGB
                                    332 	.globl _INTCHGA
                                    333 	.globl _EXTIRQ
                                    334 	.globl _GPIOENABLE
                                    335 	.globl _ANALOGA
                                    336 	.globl _FRCOSCREF
                                    337 	.globl _FRCOSCREF1
                                    338 	.globl _FRCOSCREF0
                                    339 	.globl _FRCOSCPER
                                    340 	.globl _FRCOSCPER1
                                    341 	.globl _FRCOSCPER0
                                    342 	.globl _FRCOSCKFILT
                                    343 	.globl _FRCOSCKFILT1
                                    344 	.globl _FRCOSCKFILT0
                                    345 	.globl _FRCOSCFREQ
                                    346 	.globl _FRCOSCFREQ1
                                    347 	.globl _FRCOSCFREQ0
                                    348 	.globl _FRCOSCCTRL
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

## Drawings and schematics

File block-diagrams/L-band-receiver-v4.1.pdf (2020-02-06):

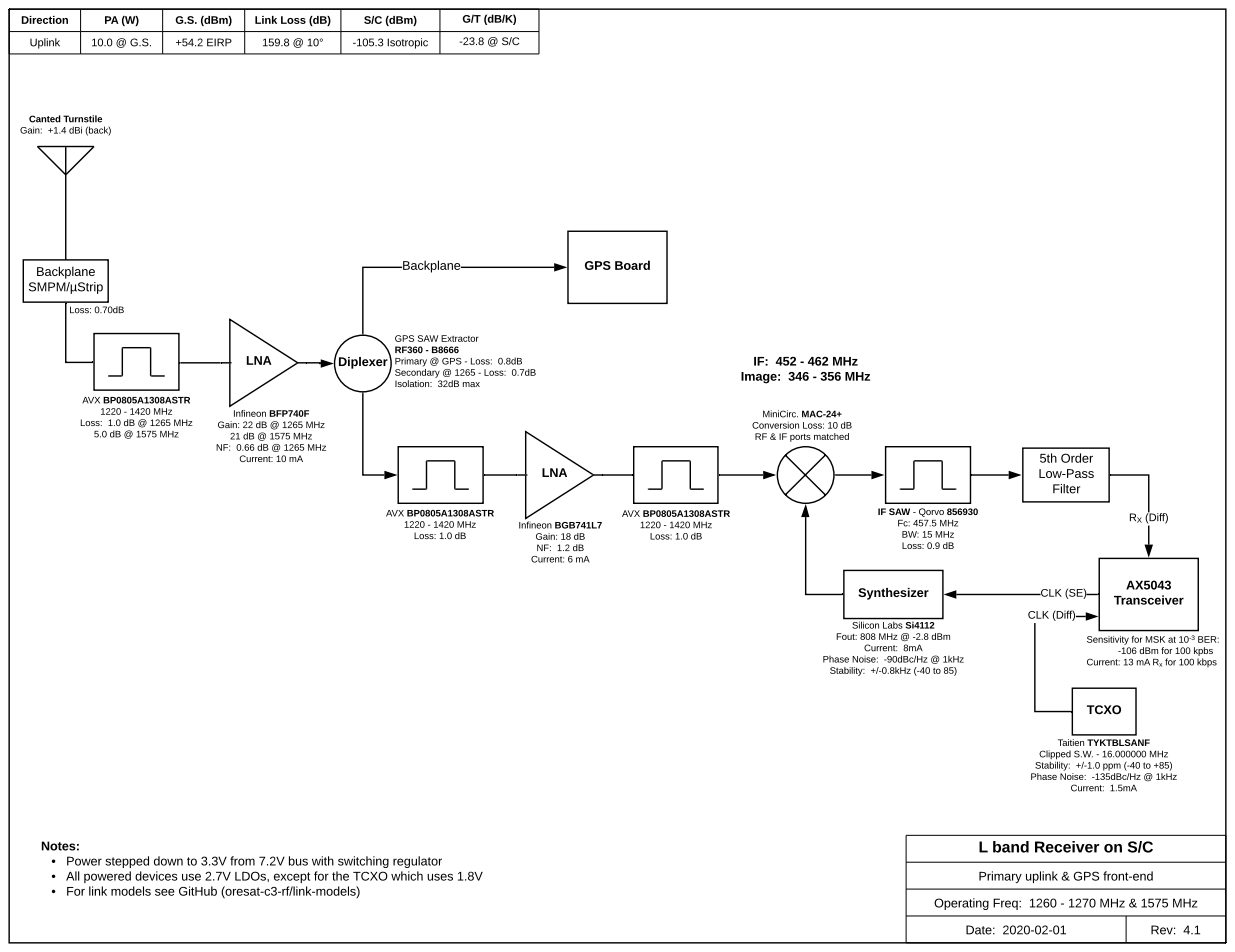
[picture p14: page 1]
Backplane; Synthesizer; Diplexer; LNA; TCXO; RX (Diff); CLK (Diff); CLK (SE); GPS Board; AX5043 Transceiver; IF: 452 - 462 MHz Image: 346 - 356 MHz; AVX BP0805A1308ASTR 1220 - 1420 MHz Loss: 1.0 dB; Backplane SMPM/µStrip; Loss: 0.70dB; Date: 2020-02-01; Rev: 4.1; 5th Order Low-Pass Filter

Direction | PA (W) | G.S. (dBm) | Link Loss (dB) | S/C (dBm) | G/T (dB/K)
Uplink | 10.0 @ G.S. | +54.2 EIRP | 159.8 @ 10° | -105.3 Isotropic | -23.8 @ S/C

Canted Turnstile Gain: +1.4 dBi (back)

GPS SAW Extractor RF360 - B8666

Primary @ GPS - Loss: 0.8dB
Secondary @ 1265 - Loss: 0.7dB
Isolation: 32dB max

AVX BP0805A1308ASTR
1220 - 1420 MHz
Loss: 1.0 dB @ 1265 MHz
5.0 dB @ 1575 MHz

Infineon BFP740F Gain: 22 dB @ 1265 MHz

MiniCirc. MAC-24+ Conversion Loss: 10 dB RF & IF ports matched

21 dB @ 1575 MHz NF: 0.66 dB @ 1265 MHz Current: 10 mA

IF SAW - Qorvo 856930
Fc: 457.5 MHz
BW: 15 MHz
Loss: 0.9 dB

Infineon BGB741L7 Gain: 18 dB NF: 1.2 dB Current: 6 mA

Silicon Labs Si4112
Fout: 808 MHz @ -2.8 dBm
Current: 8mA

Sensitivity for MSK at 10⁻³ BER:
-106 dBm for 100 kpbs Current: 13 mA Rx for 100 kbps

Phase Noise: -90dBc/Hz @ 1kHz
Stability: +/-0.8kHz (-40 to 85)

Taitien TYKTBLSANF Clipped S.W. - 16.000000 MHz

Stability: +/-1.0 ppm (-40 to +85)
Phase Noise: -135dBc/Hz @ 1kHz Current: 1.5mA

Notes:
- Power stepped down to 3.3V from 7.2V bus with switching regulator
- All powered devices use 2.7V LDOs, except for the TCXO which uses 1.8V
- For link models see GitHub (oresat-c3-rf/link-models)

L band Receiver on S/C

Primary uplink & GPS front-end
Operating Freq: 1260 - 1270 MHz & 1575 MHz

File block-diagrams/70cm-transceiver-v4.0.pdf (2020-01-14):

## Log RF Detector

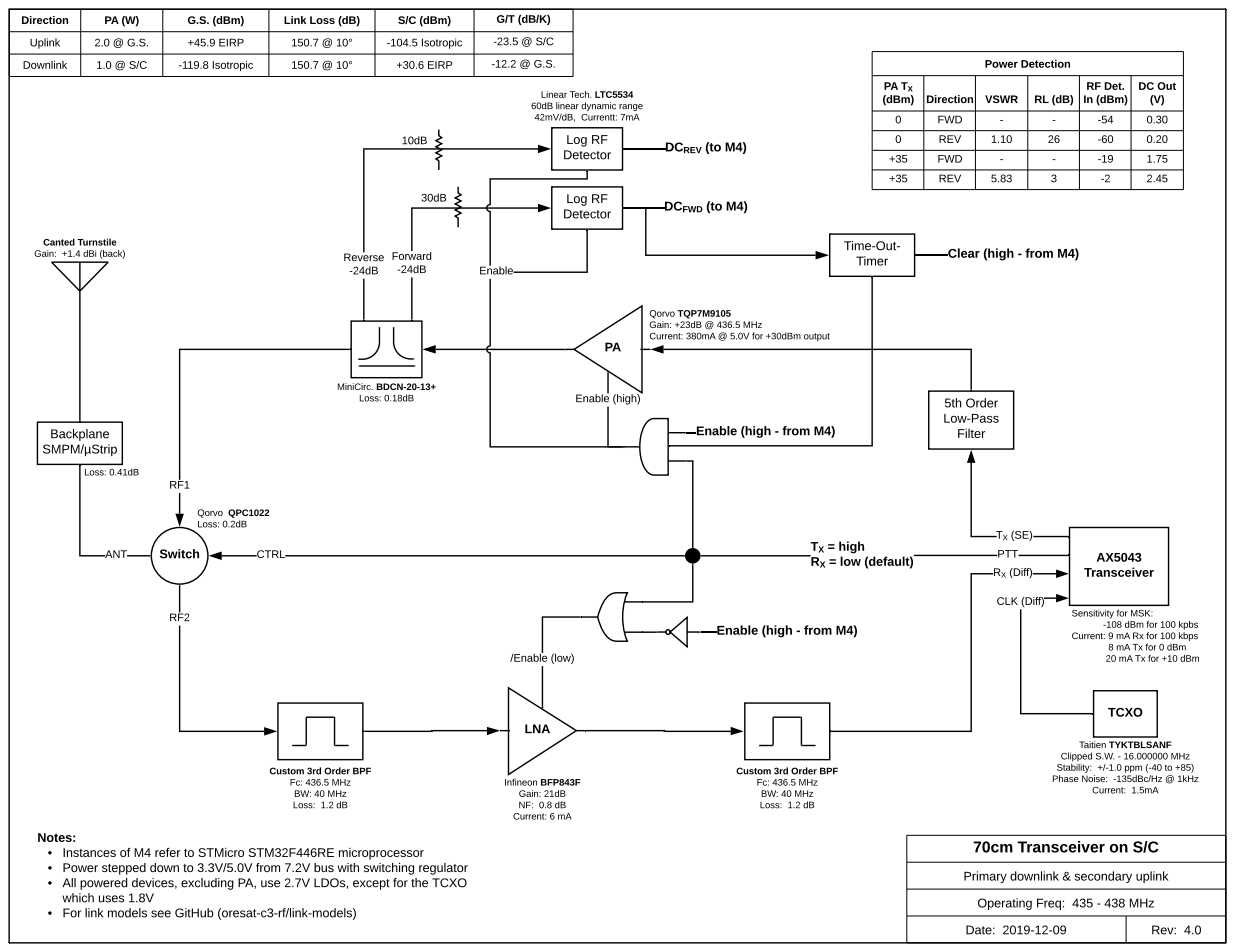
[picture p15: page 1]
ANT; RX (Diff); LNA; TCXO; MiniCirc. BDCN-20-13+ Loss: 0.18dB; Switch; Qorvo QPC1022 Loss: 0.2dB; AX5043 Transceiver; CLK (Diff); Reverse -24dB; DCREV (to M4); CTRL; /Enable (low); Enable (high); TX = high; RX = low (default); PTT; Log RF; Detector; DCFWD (to M4); Forward -24dB; Power Detection; FWD; REV; Enable; Backplane SMPM/µStrip; Loss: 0.41dB; 70cm Transceiver on S/C; Date: 2019-12-09; Rev: 4.0; Downlink; -119.8 Isotropic; +30.6 EIRP; Time-Out-; Timer; Clear (high - from M4)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

Direction | PA (W) | G.S. (dBm) | Link Loss (dB) | S/C (dBm) | G/T (dB/K)
Uplink | 2.0 @ G.S. | +45.9 EIRP | 150.7 @ 10° | -104.5 Isotropic | -23.5 @ S/C

10dB | PA TX (dBm) | Direction | VSWR | RL (dB) | RF Det. In (dBm) | DC Out (V)

Linear Tech. LTC5534
60dB linear dynamic range
42mV/dB, Currentt: 7mA

0 | FWD | - | - | -54 | 0.30
0 | REV | 1.10 | 26 | -60 | 0.20

Canted Turnstile Gain: +1.4 dBi (back)

Qorvo TQP7M9105 Gain: +23dB @ 436.5 MHz Current: 380mA@ 5.0V for +30dBm output

Enable (high - from M4)

Sensitivity for MSK:
-108 dBm for 100 kpbs Current: 9 mA Rx for 100 kbps

8 mA Tx for 0 dBm
20 mA Tx for +10 dBm

Taitien TYKTBLSANF Clipped S.W. - 16.000000 MHz

Custom 3rd Order BPF
Fc: 436.5 MHz
BW: 40 MHz
Loss: 1.2 dB

Stability: +/-1.0 ppm (-40 to +85)
Phase Noise: -135dBc/Hz @ 1kHz Current: 1.5mA

Infineon BFP843F Gain: 21dB NF: 0.8 dB Current: 6 mA

Notes:
- Instances of M4 refer to STMicro STM32F446RE microprocessor
- Power stepped down to 3.3V/5.0V from 7.2V bus with switching regulator
- All powered devices, excluding PA, use 2.7V LDOs, except for the TCXO
which uses 1.8V
- For link models see GitHub (oresat-c3-rf/link-models)

Primary downlink & secondary uplink
Operating Freq: 435 - 438 MHz

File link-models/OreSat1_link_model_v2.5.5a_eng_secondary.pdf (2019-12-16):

OreSat1 - Backup Telecommand | OreSat1 - Primary Telemetry

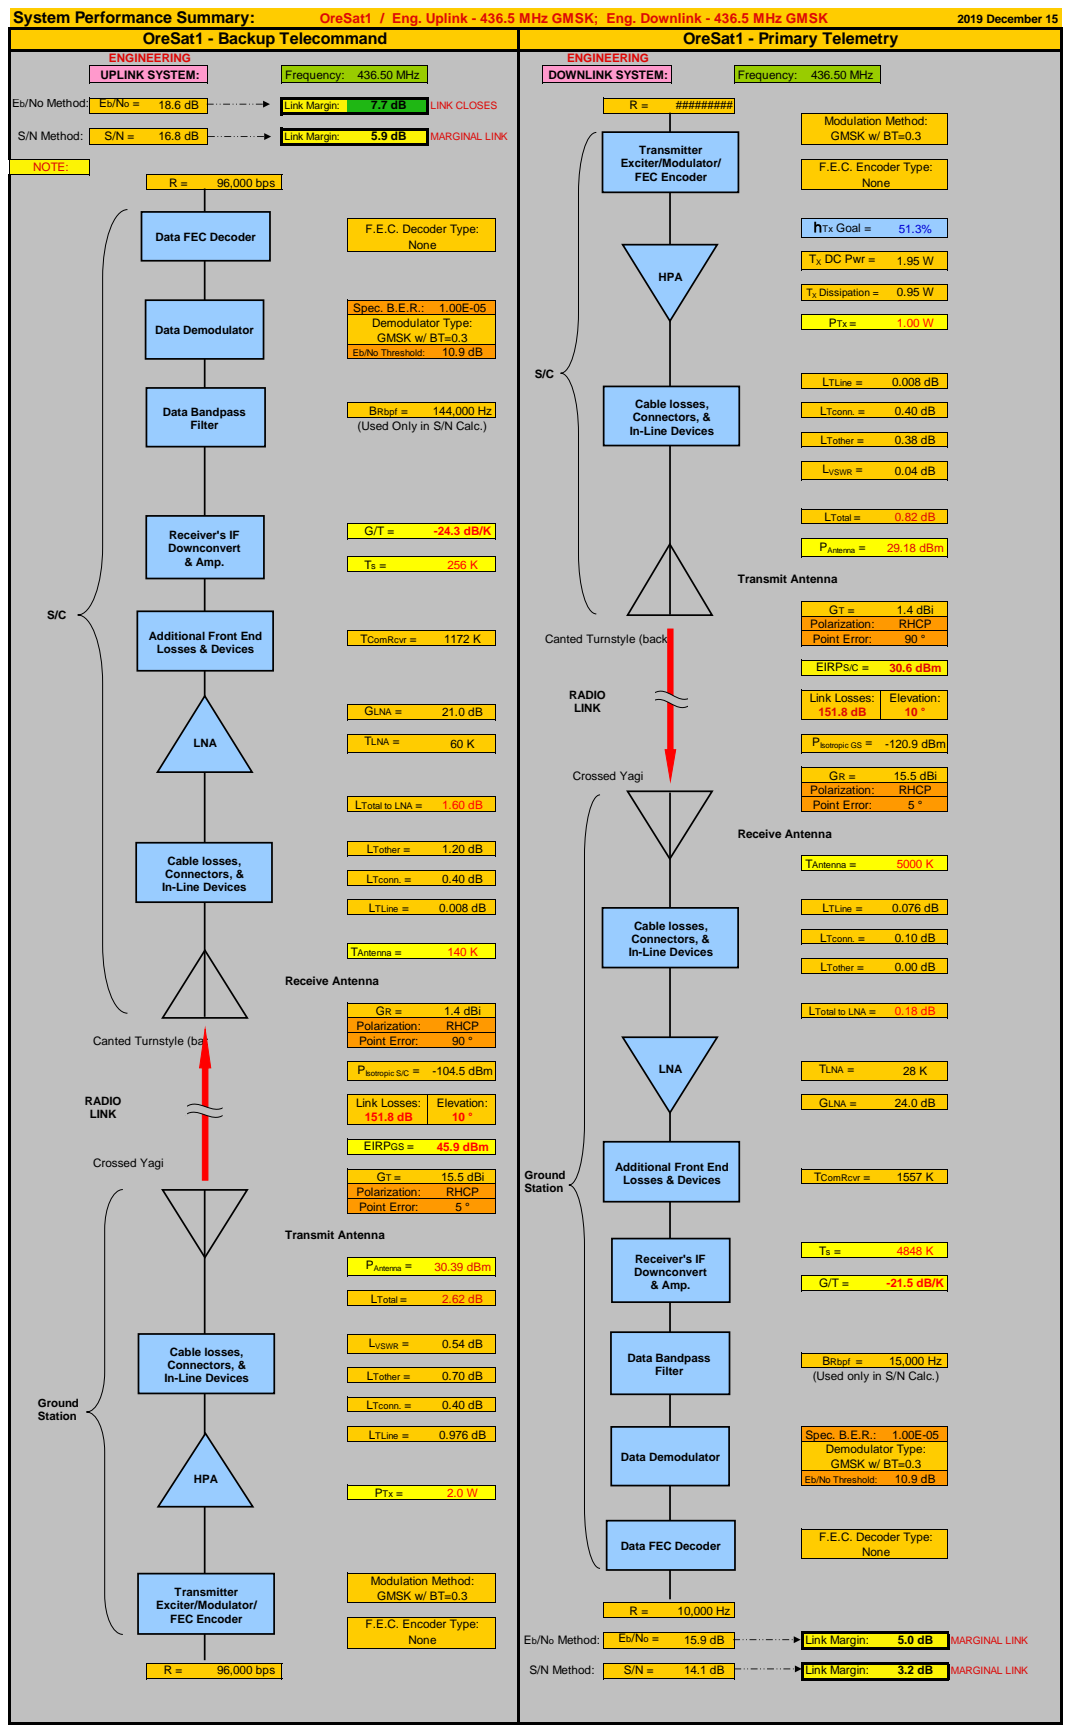
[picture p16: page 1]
System Performance Summary:; OreSat1 / Eng. Uplink - 436.5 MHz GMSK; Eng. Downlink - 436.5 MHz GMSK; 2019 December 15; Frequency: 436.50 MHz; Frequency:; 436.50 MHz; Eb/No Method:; Link Margin:; LINK CLOSES; S/N Method:; MARGINAL LINK; NOTE:; 96,000 bps; hTx Goal =; TX DC Pwr =; TX Dissipation =; Spec. B.E.R.:; PTx =; Eb/No Threshold:; LTLine =; BRbpf =; LTconn. =; LTother =; LVSWR =; LTotal =; PAntenna =; 29.18 dBm; Transmit Antenna; 1.4 dBi; Polarization:; RHCP; TComRcvr =; Point Error: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

ENGINEERING | ENGINEERING

Data FEC Decoder

(Used Only in S/N Calc.)

Additional Front End
Losses & Devices

Canted Turnstyle (back)

(Used only in S/N Calc.)

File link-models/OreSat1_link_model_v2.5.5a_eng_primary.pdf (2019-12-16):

OreSat1 - Primary Telecommand | OreSat1 - Primary Telemetry

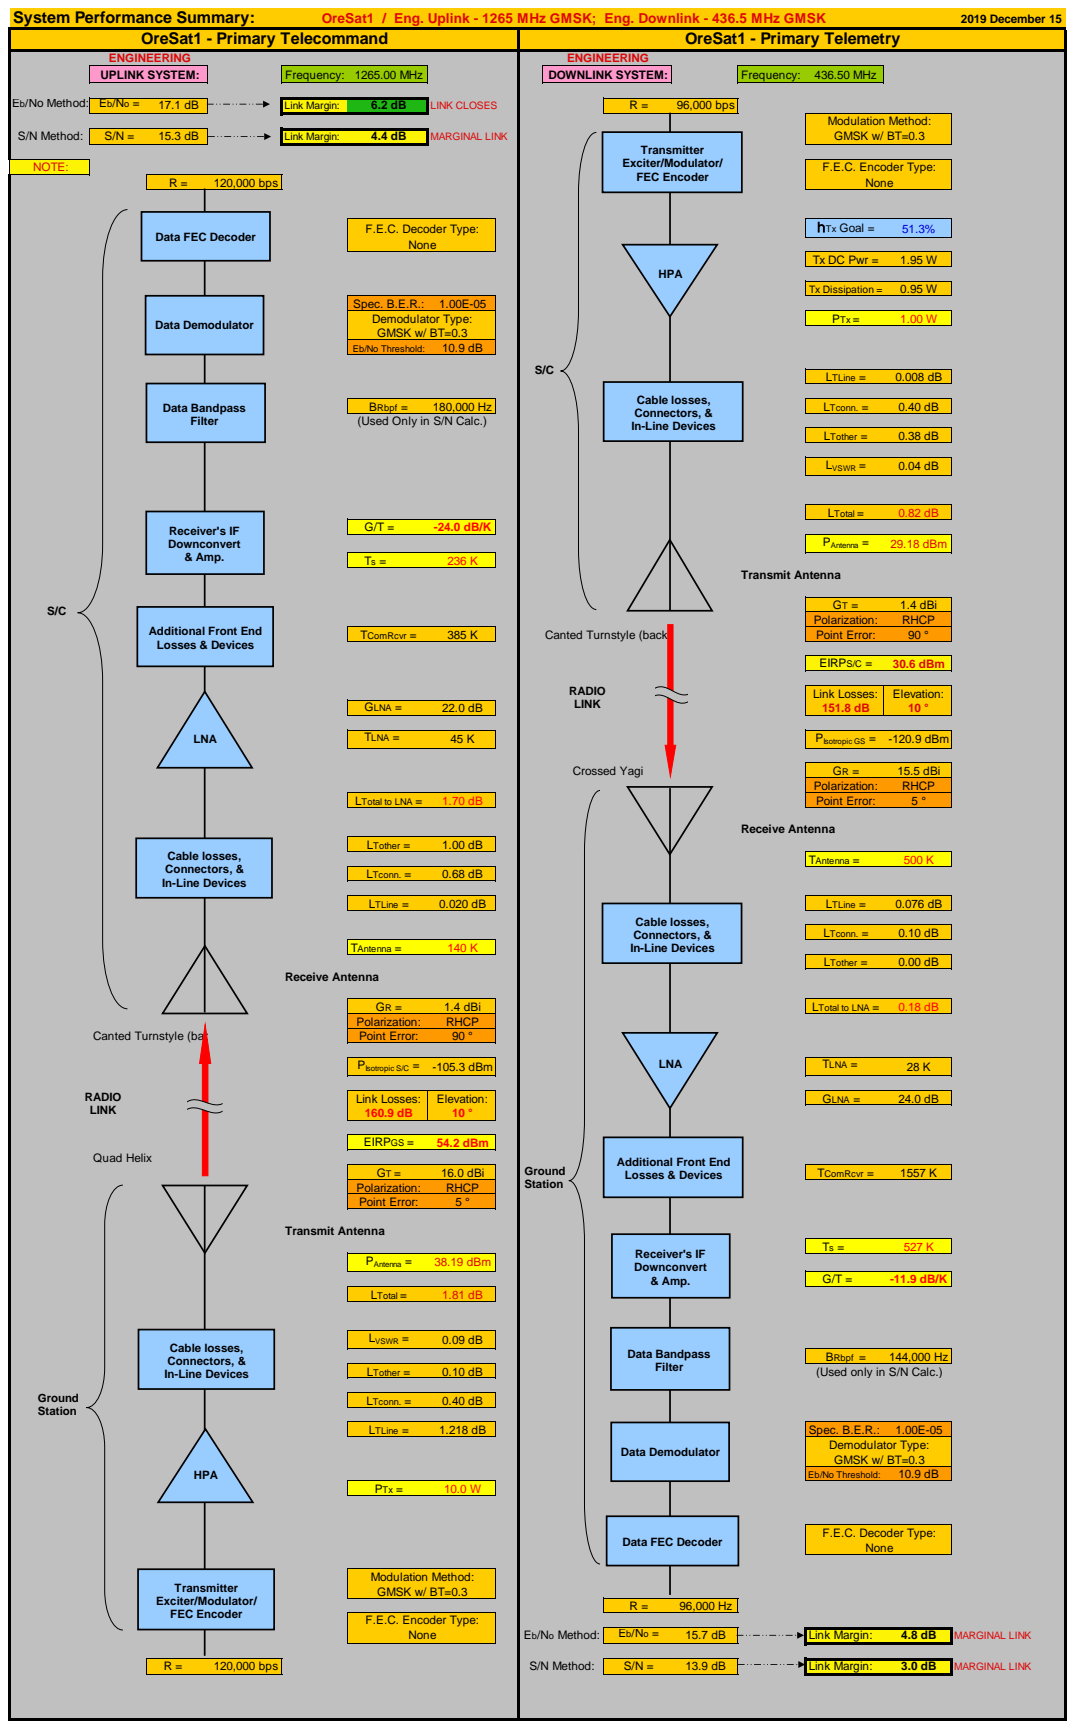
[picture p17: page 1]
System Performance Summary:; OreSat1 / Eng. Uplink - 1265 MHz GMSK; Eng. Downlink - 436.5 MHz GMSK; 2019 December 15; Frequency: 1265.00 MHz; Frequency:; 436.50 MHz; Eb/No Method:; Link Margin:; LINK CLOSES; 96,000 bps; S/N Method:; MARGINAL LINK; NOTE:; 120,000 bps; hTx Goal =; Tx DC Pwr =; Tx Dissipation =; Spec. B.E.R.:; PTx =; Eb/No Threshold:; LTLine =; BRbpf =; LTconn. =; LTother =; LVSWR =; LTotal =; PAntenna =; 29.18 dBm; Transmit Antenna; 1.4 dBi; Polarization:; RHCP; TComRcvr =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

ENGINEERING | ENGINEERING

Data FEC Decoder

(Used Only in S/N Calc.)

Additional Front End
Losses & Devices

Canted Turnstyle (back)

(Used only in S/N Calc.)

Eb/No Method:

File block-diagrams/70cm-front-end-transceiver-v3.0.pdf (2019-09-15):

## Log RF Detector

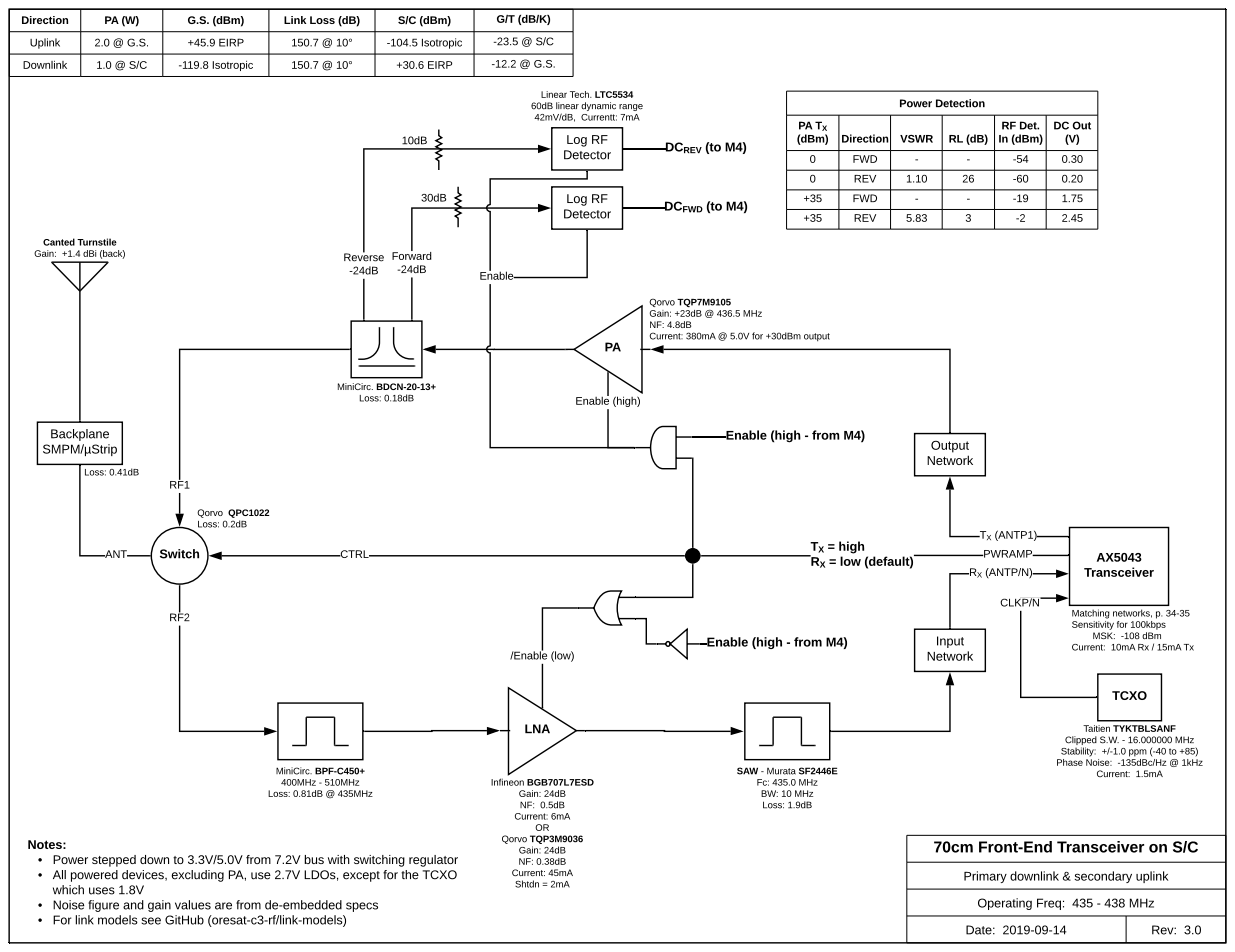
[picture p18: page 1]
ANT; RX (ANTP/N); TX (ANTP1); LNA; Shtdn = 2mA; TCXO; MiniCirc. BDCN-20-13+ Loss: 0.18dB; Switch; Qorvo QPC1022 Loss: 0.2dB; AX5043 Transceiver; SAW - Murata SF2446E Fc: 435.0 MHz BW: 10 MHz Loss: 1.9dB; MiniCirc. BPF-C450+ 400MHz - 510MHz Loss: 0.81dB @ 435MHz; CLKP/N; Reverse -24dB; DCREV (to M4); CTRL; /Enable (low); Enable (high); TX = high; RX = low (default); PWRAMP; Log RF; Detector; DCFWD (to M4); Forward -24dB; Power Detection; (dBm); Direction; VSWR; RF Det. In (dBm); DC Out (V); FWD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

Direction | PA (W) | G.S. (dBm) | Link Loss (dB) | S/C (dBm) | G/T (dB/K)
Uplink | 2.0 @ G.S. | +45.9 EIRP | 150.7 @ 10° | -104.5 Isotropic | -23.5 @ S/C
Downlink | 1.0 @ S/C | -119.8 Isotropic | 150.7 @ 10° | +30.6 EIRP | -12.2 @ G.S.

Linear Tech. LTC5534
60dB linear dynamic range
42mV/dB, Currentt: 7mA

0 | REV | 1.10 | 26 | -60 | 0.20
+35 | FWD | - | - | -19 | 1.75
+35 | REV | 5.83 | 3 | -2 | 2.45

Canted Turnstile Gain: +1.4 dBi (back)

Qorvo TQP7M9105 Gain: +23dB @ 436.5 MHz NF: 4.8dB Current: 380mA@ 5.0V for +30dBm output

Enable (high - from M4)

Matching networks, p. 34-35
Sensitivity for 100kbps MSK: -108 dBm

Current: 10mA Rx / 15mA Tx

Taitien TYKTBLSANF Clipped S.W. - 16.000000 MHz

Stability: +/-1.0 ppm (-40 to +85)
Phase Noise: -135dBc/Hz @ 1kHz Current: 1.5mA

Infineon BGB707L7ESD Gain: 24dB NF: 0.5dB Current: 6mA OR Qorvo TQP3M9036 Gain: 24dB NF: 0.38dB Current: 45mA

Notes:
- Power stepped down to 3.3V/5.0V from 7.2V bus with switching regulator
- All powered devices, excluding PA, use 2.7V LDOs, except for the TCXO
which uses 1.8V
- Noise figure and gain values are from de-embedded specs
- For link models see GitHub (oresat-c3-rf/link-models)

70cm Front-End Transceiver on S/C

Primary downlink & secondary uplink
Operating Freq: 435 - 438 MHz

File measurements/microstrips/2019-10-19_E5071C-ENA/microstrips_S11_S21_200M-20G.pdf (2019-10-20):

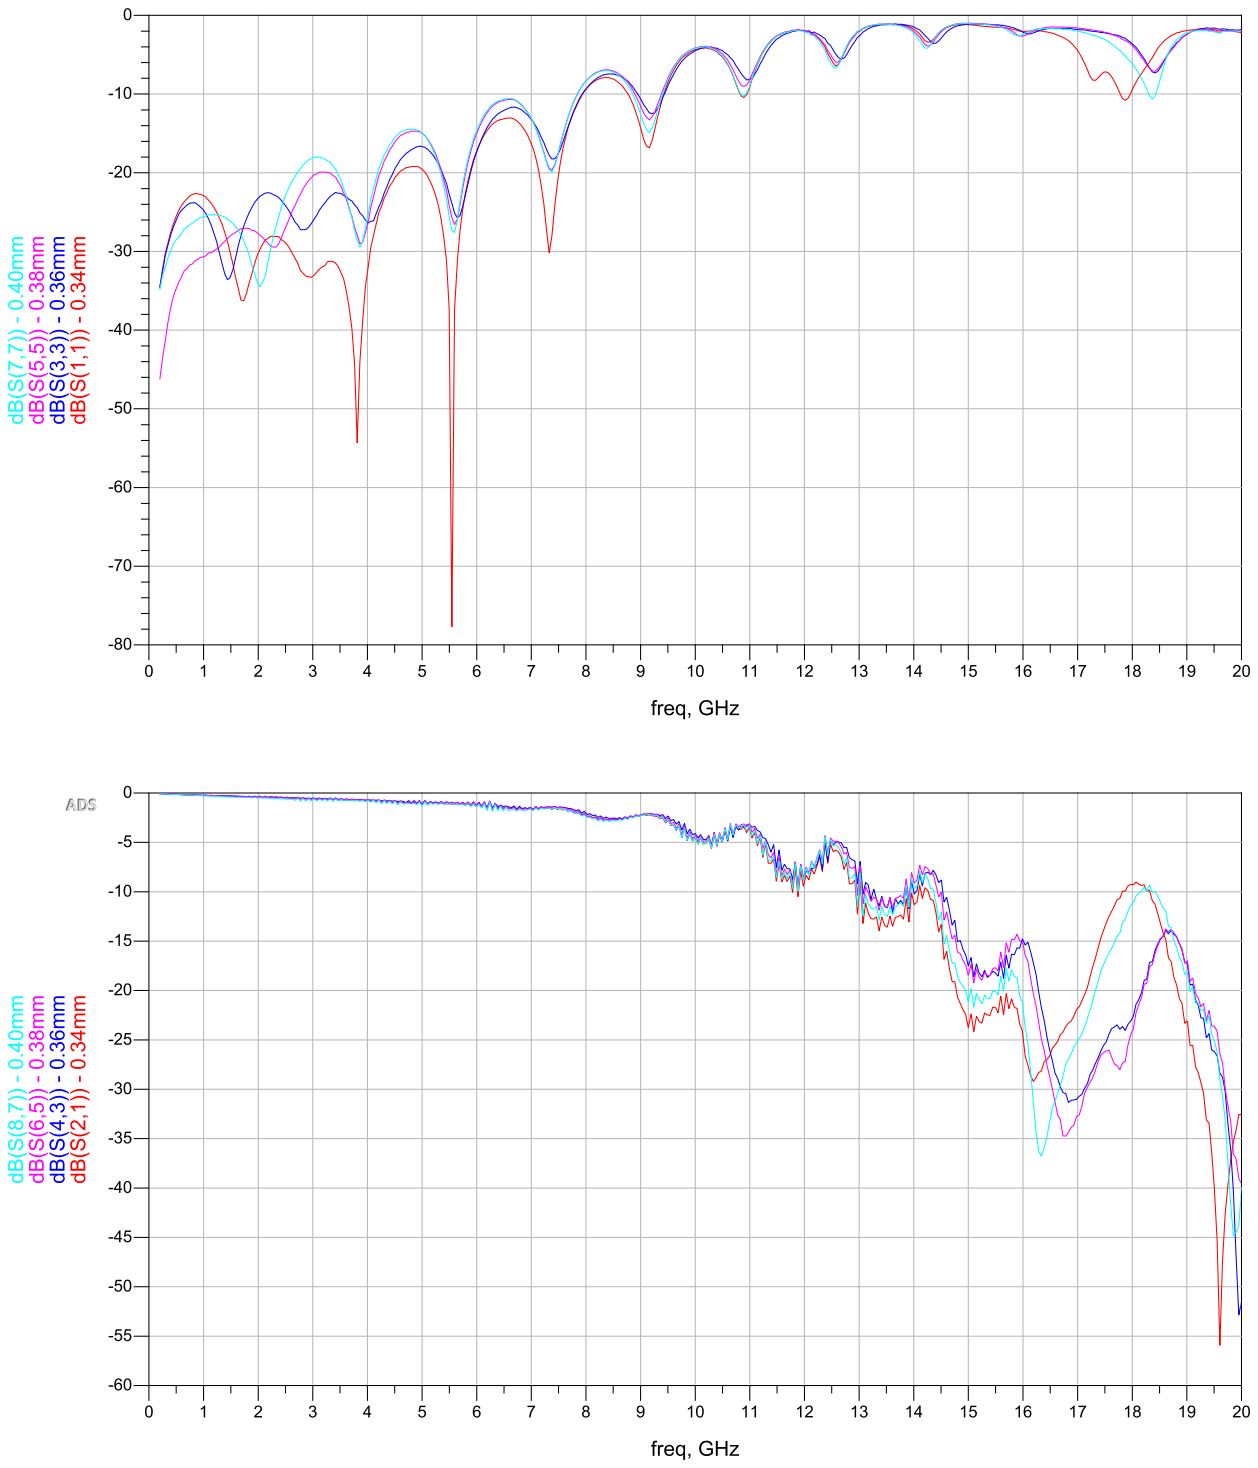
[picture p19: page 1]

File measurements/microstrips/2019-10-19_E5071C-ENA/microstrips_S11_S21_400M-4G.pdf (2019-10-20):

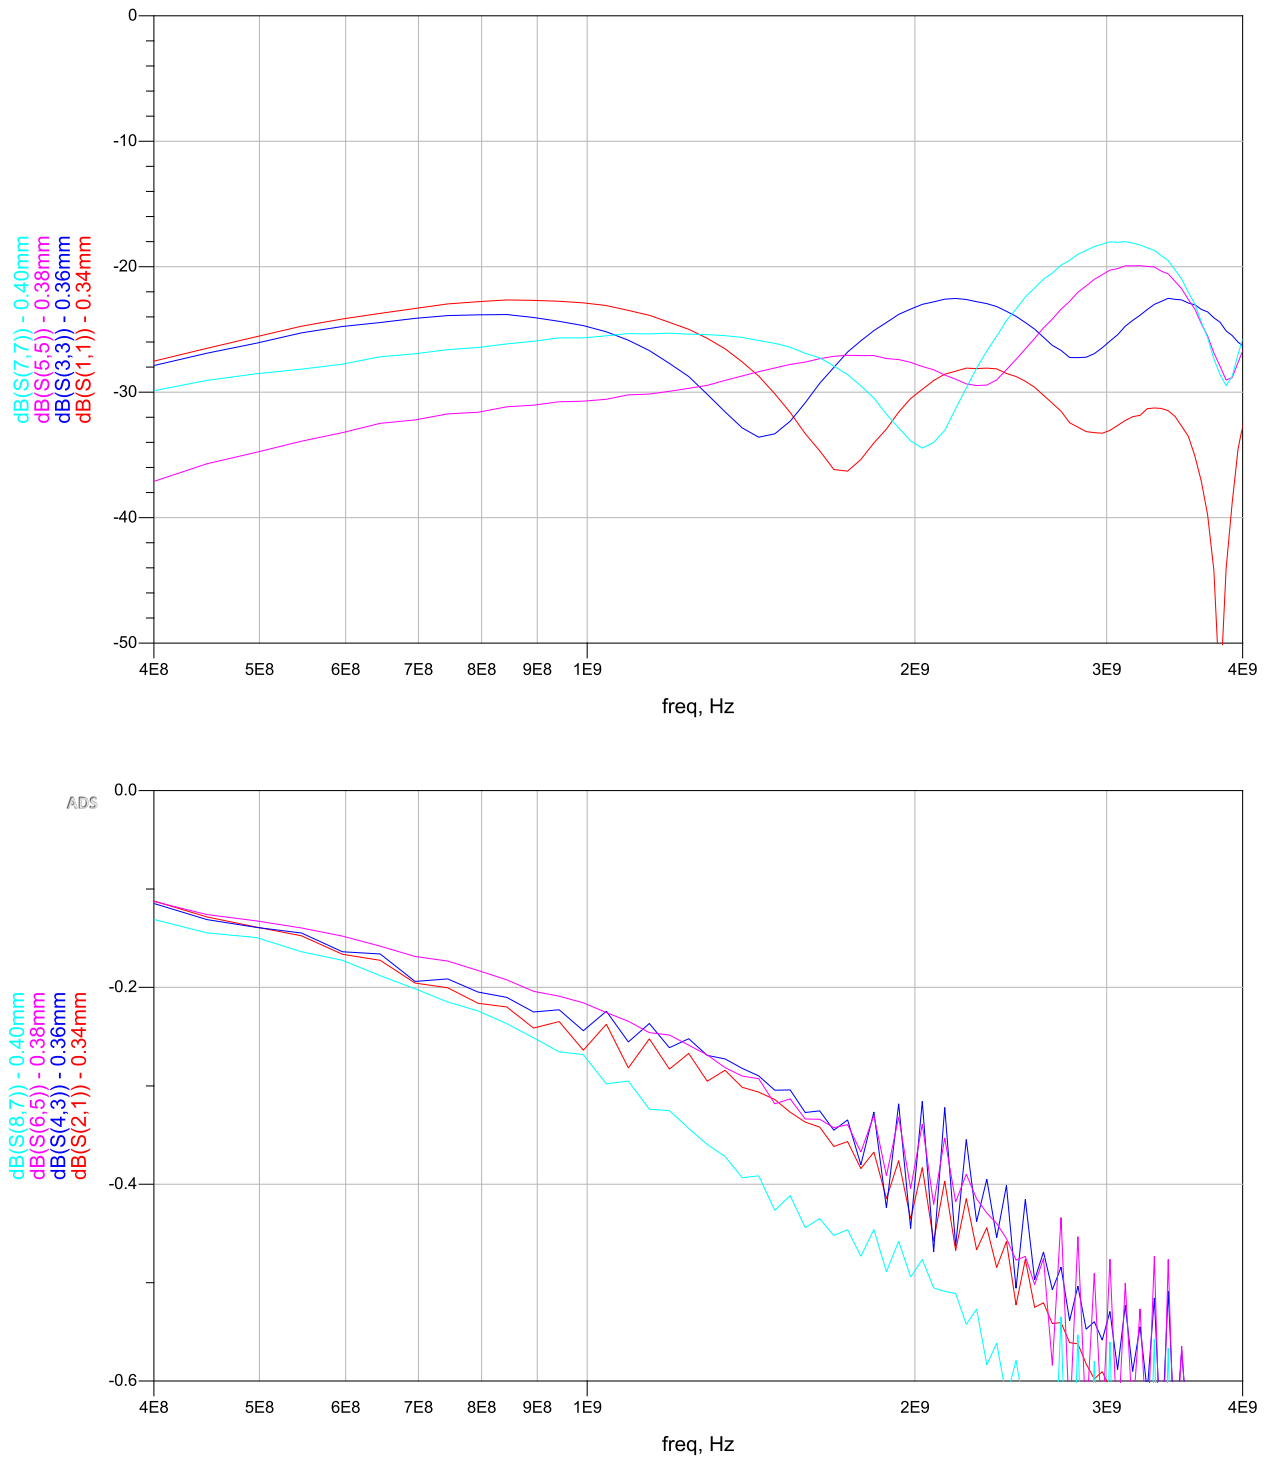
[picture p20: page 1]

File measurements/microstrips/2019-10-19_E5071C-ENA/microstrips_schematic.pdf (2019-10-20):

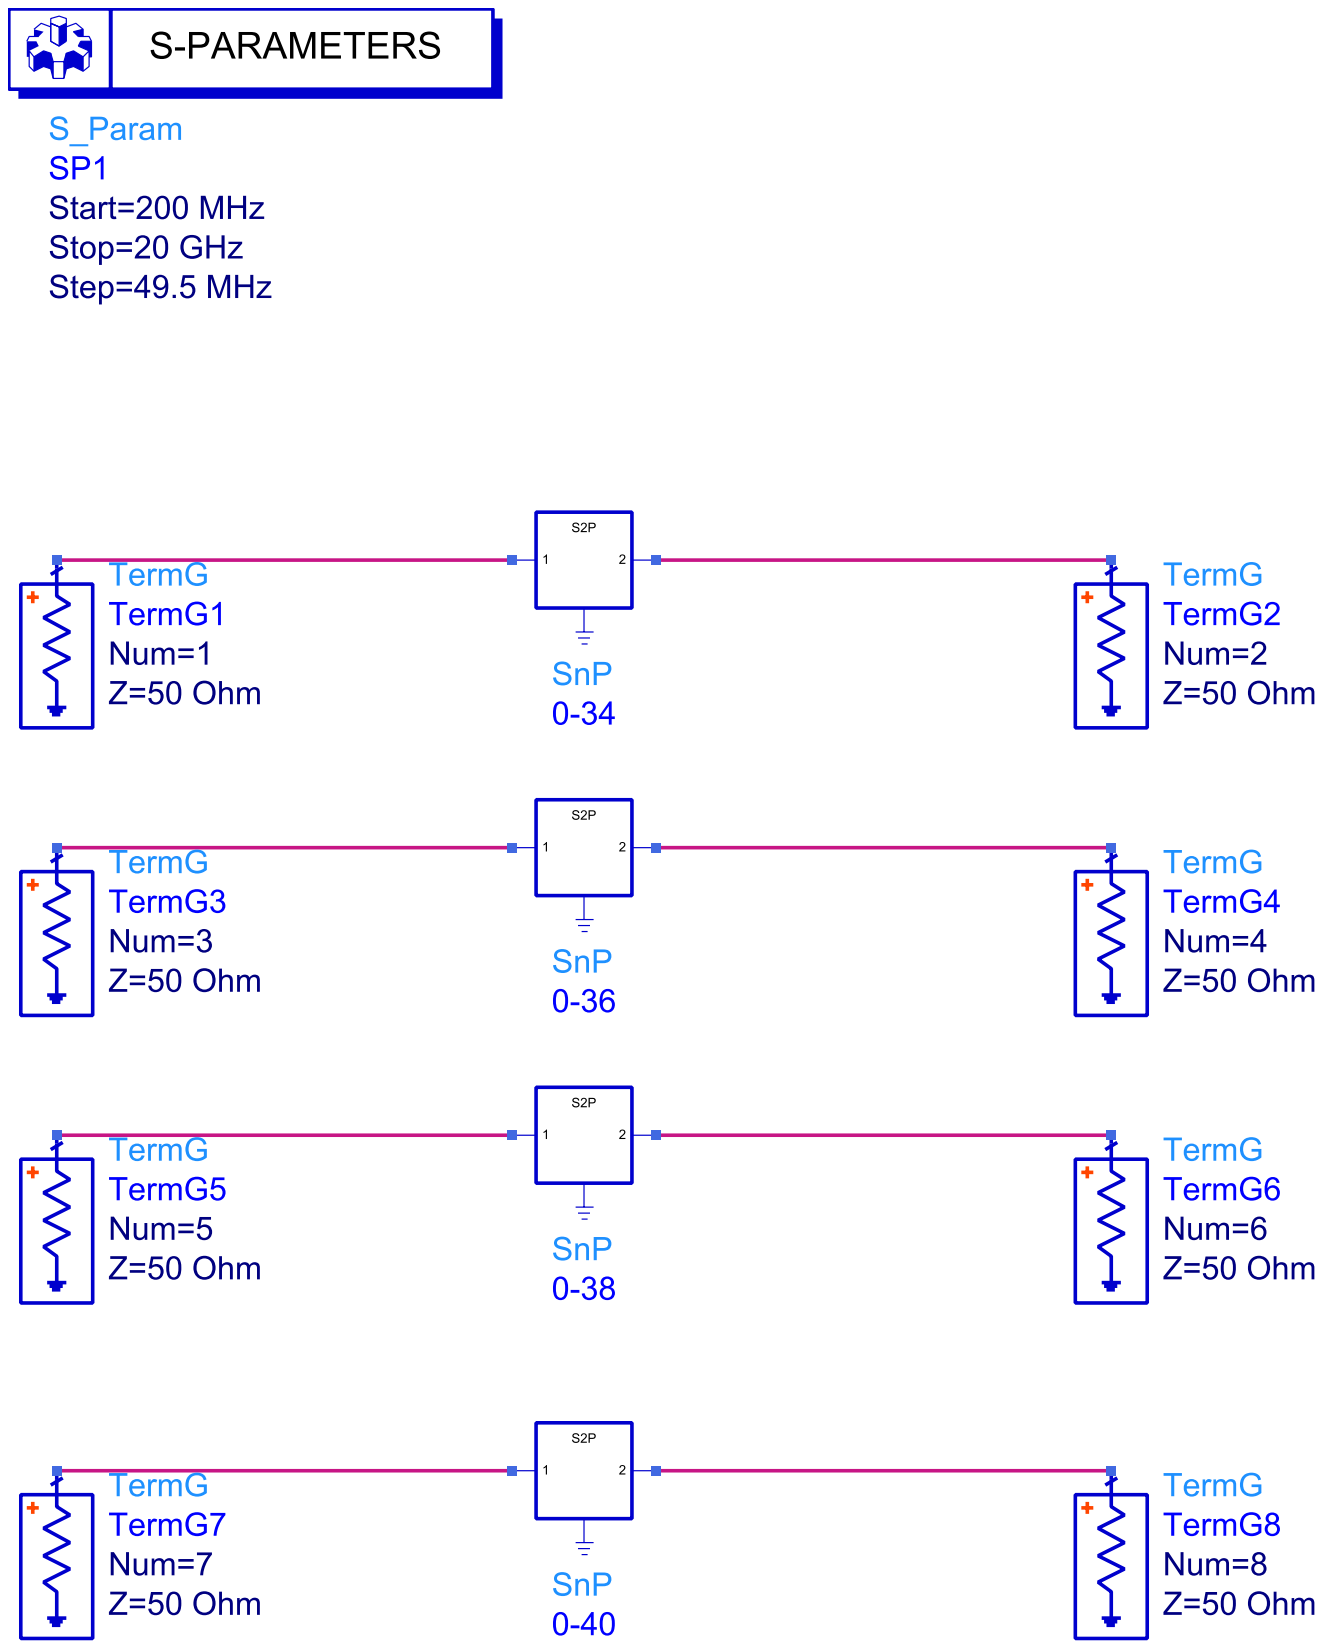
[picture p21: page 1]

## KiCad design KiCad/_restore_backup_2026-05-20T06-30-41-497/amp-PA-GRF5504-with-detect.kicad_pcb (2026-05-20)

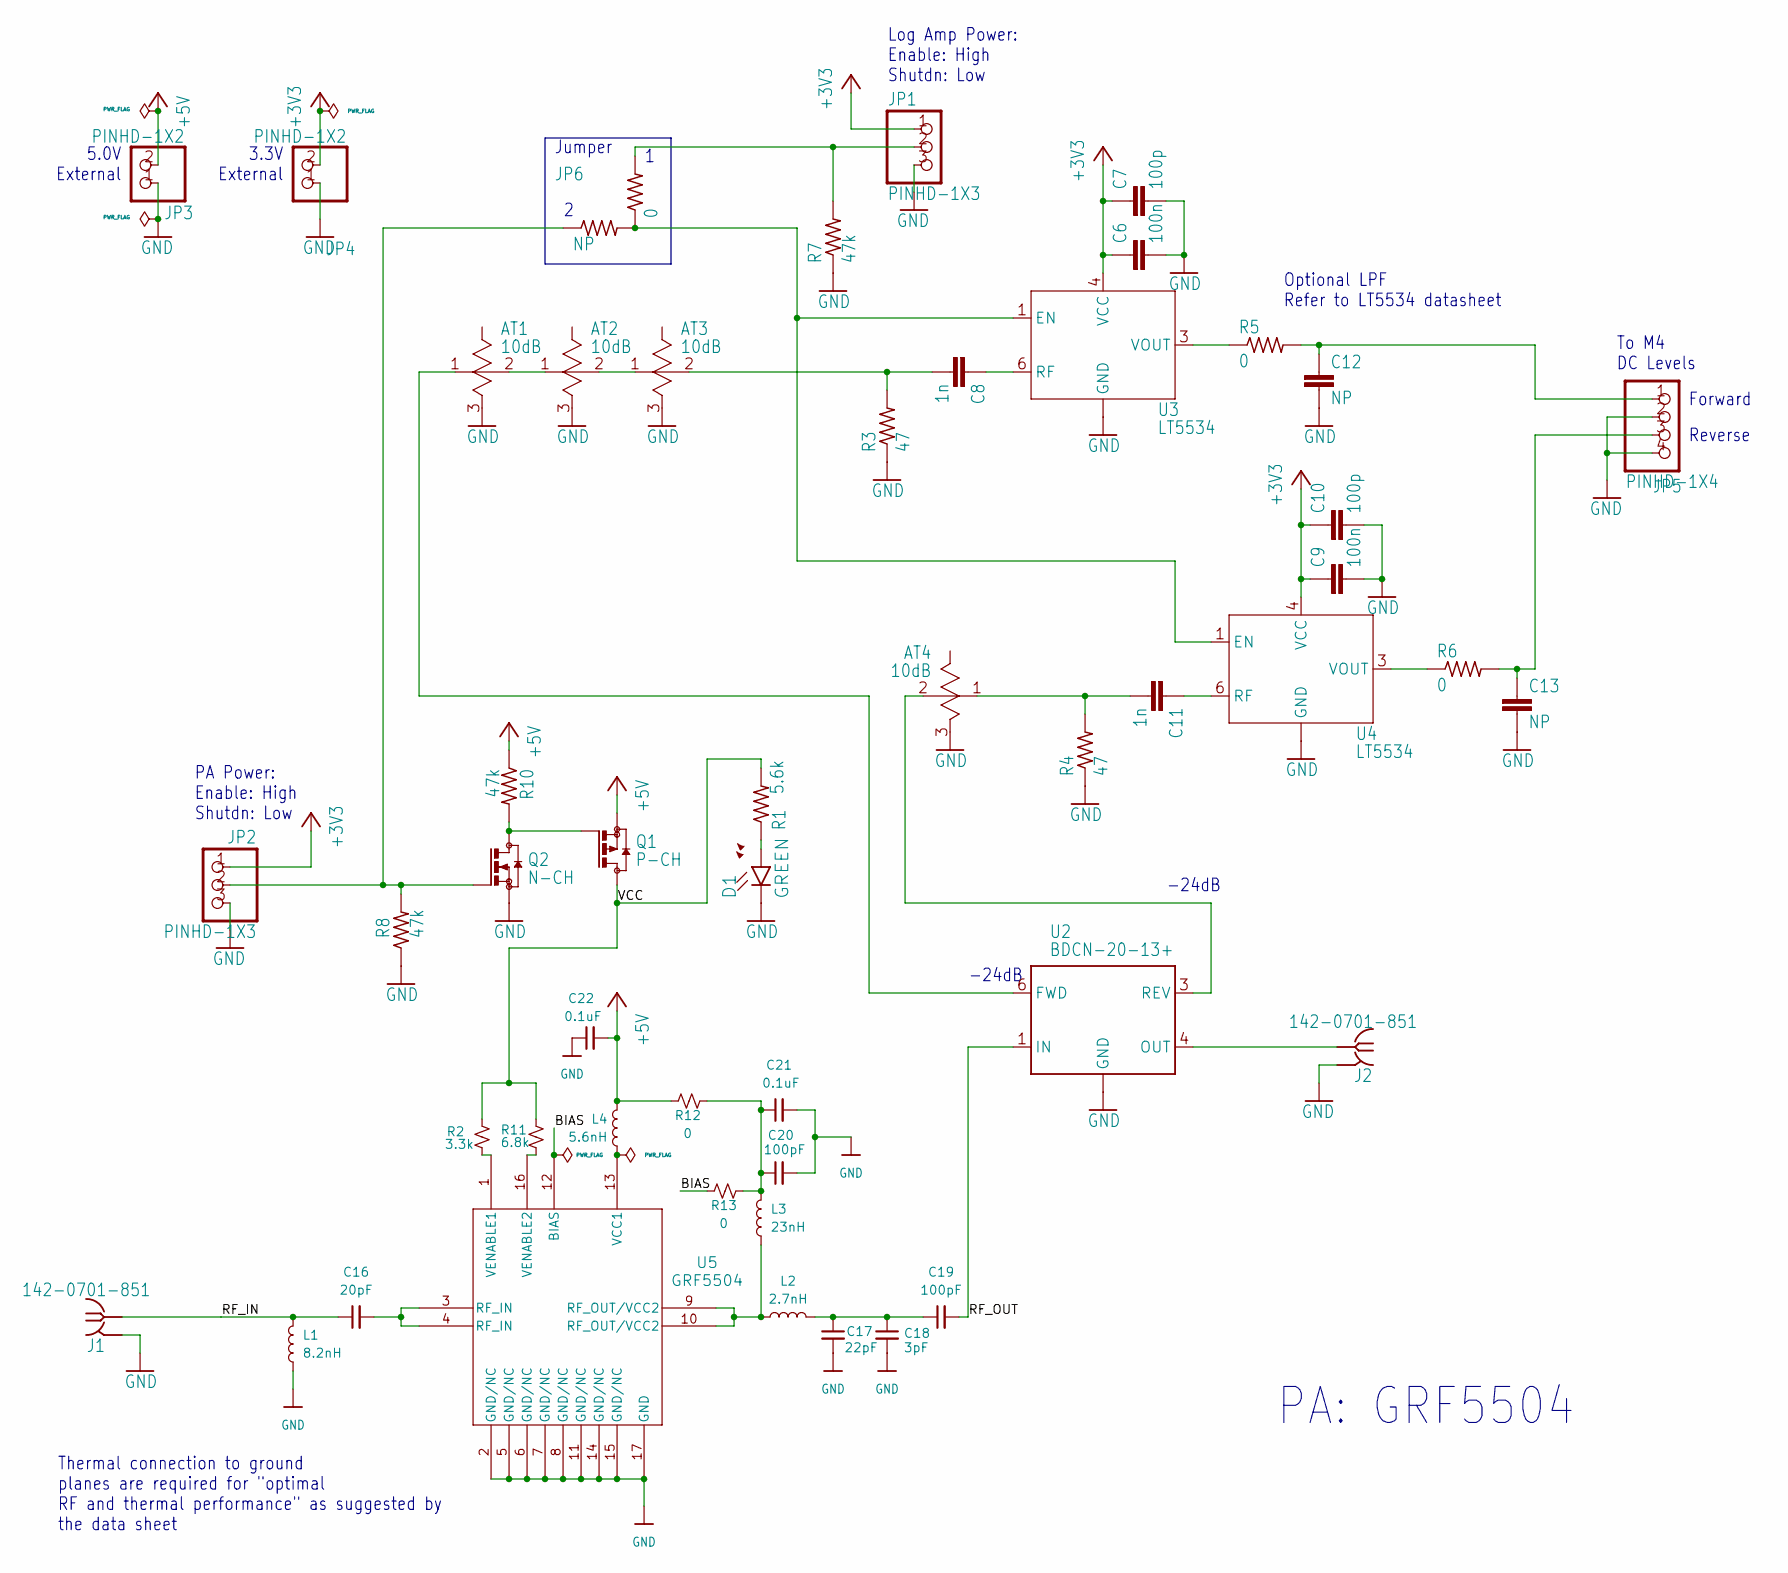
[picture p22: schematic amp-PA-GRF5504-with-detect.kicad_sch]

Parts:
AT1: 10dB; 0805
AT2, AT3, AT4: 10dB; 0603
C6, C9: 100n; .0603-B-NOSILK
C7, C10: 100p; .0603-B-NOSILK
C8, C11: 1n; .0402-C-NOSILK
C12, C13: NP; .0603-B-NOSILK
C16: 20pF; .0402-B-NOSILK-GRJ15-GRM15-MURATA-CAPS
C17: 22pF; .0402-B-NOSILK-GRJ15-GRM15-MURATA-CAPS
C18: 3pF; .0402-B-NOSILK-GRJ15-GRM15-MURATA-CAPS
C19, C20: 100pF; .0402-B-NOSILK-GRJ15-GRM15-MURATA-CAPS
C21, C22: 0.1uF; .0402-B-NOSILK-GRJ15-GRM15-MURATA-CAPS
D1: GREEN; LED-0603
J1, J2: 142-0701-851
JP1, JP2: PINHD-1X3; 1X03_325
JP3, JP4: PINHD-1X2; 1X02_325
JP5: PINHD-1X4; 1X04_325
JP6: NP; .0603-B-NOSILK
L1: 8.2nH; .0402-B-NOSILK-LQG-MURATA-INDUCTOR
L2: 2.7nH; .0603-B-NOSILK-DC-COILCRAFT-INDUCTOR
L3: 23nH; 0908-0908SQ-COILCRAFT-INDUCTOR
L4: 5.6nH; .0402-B-NOSILK-HP-DIGITALELECTRONICS-INDUCTOR
Q1: P-CH; SOT23-6
Q2: N-CH; SOT23-6
R1: 5.6k; .0603-B-NOSILK
R2: 3.3k; .0402-B-NOSILK
R3, R4: 47; .0402-C-NOSILK
R5, R6, R9, R12, R13: 0; .0603-B-NOSILK
R7, R8, R10: 47k; .0402-B-NOSILK
R11: 6.8k; .0402-B-NOSILK
U2: BDCN-20-13+
U3, U4: LT5534; SC70
U5: GRF5504; QFN-16_3MM_GRF

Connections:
+3V3: C6.1, C7.1, C9.1, C10.1, JP1.1, JP2.1, JP4.2, U3.4 (VCC), U4.4 (VCC)
+5V: C22.2, JP3.2, L4.1, Q1.2 (S), R10.1, R12.1
/BIAS: R13.1, U5.12 (BIAS)
/RF_IN: C16.1, J1.RF1 (RF), L1.1
/RF_OUT: C19.2, U2.1 (IN)
/VCC: Q1.3 (D), R1.2, R2.1, R11.1
GND: AT1.3 (GND), AT2.3 (GND), AT3.3 (GND), AT4.3 (GND), C6.2, C7.2, C9.2, C10.2, C12.2, C13.2, C17.2, C18.2, C20.2, C21.2, C22.1, D1.C, J1.GND1 (GND), J1.GND2 (GND), J1.GND3 (GND), J1.GND4 (GND), J2.GND1 (GND), J2.GND2 (GND), J2.GND3 (GND), J2.GND4 (GND), JP1.3, JP2.3, JP3.1, JP4.1, JP5.2, JP5.4, L1.2, Q2.2 (S), R3.1, R4.1, R7.1, R8.1, U2.2 (GND), U2.5 (GND), U3.2 (GND), U3.5 (GND), U4.2 (GND), U4.5 (GND), U5.2 (GND/NC), U5.5 (GND/NC), U5.6 (GND/NC), U5.7 (GND/NC), U5.8 (GND/NC), U5.11 (GND/NC), U5.14 (GND/NC), U5.15 (GND/NC), U5.17 (GND)
unnamed: AT1.2, AT2.1
unnamed: AT2.2, AT3.1
unnamed: AT3.2, C8.2, R3.2
unnamed: AT4.1, C11.2, R4.2
unnamed: C12.1, JP5.1, R5.2
unnamed: C13.1, JP5.3, R6.2
unnamed: C16.2, U5.3 (RF_IN), U5.4 (RF_IN)
unnamed: C17.1, C18.1, C19.1, L2.2
unnamed: C20.1, C21.1, L3.2, R12.2, R13.2
unnamed: D1.A, R1.1
unnamed: J2.RF1 (RF), U2.4 (OUT)
unnamed: JP1.2, R7.2, R9.2
unnamed: L2.1, L3.1, U5.9 (RF_OUT/VCC2), U5.10 (RF_OUT/VCC2)
unnamed: Q1.1 (G), Q2.3 (D), R10.2
unnamed: JP2.2, JP6.1, Q2.1 (G), R8.2
unnamed: AT1.1, U2.6 (FWD)
unnamed: AT4.2, U2.3 (REV)
unnamed: JP6.2, R9.1, U3.1 (EN), U4.1 (EN)
unnamed: C8.1, U3.6 (RF)
unnamed: R5.1, U3.3 (VOUT)
unnamed: C11.1, U4.6 (RF)
unnamed: R6.1, U4.3 (VOUT)
unnamed: L4.2, U5.13 (VCC1)
unnamed: R2.2, U5.1 (VENABLE1)
unnamed: R11.2, U5.16 (VENABLE2)

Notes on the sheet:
PA Power: Enable: High Shutdn: Low
Log Amp Power: Enable: High Shutdn: Low
3.3V External
To M4 DC Levels
-24dB
Jumper
PA: GRF5504
Optional LPF Refer to LT5534 datasheet
Thermal connection to ground planes are required for "optimal RF and thermal performance" as suggested by the data sheet
Forward
5.0V External
Reverse

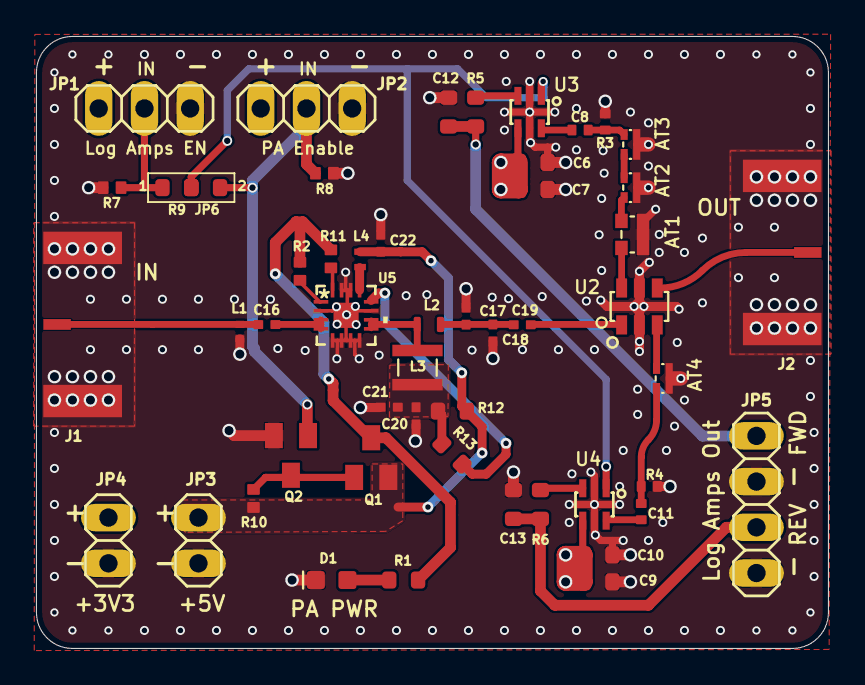
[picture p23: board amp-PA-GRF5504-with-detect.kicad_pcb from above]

Board: 4 copper layers, 44.0 x 34.0 mm, 51 parts (0 on the bottom side), 32 nets.

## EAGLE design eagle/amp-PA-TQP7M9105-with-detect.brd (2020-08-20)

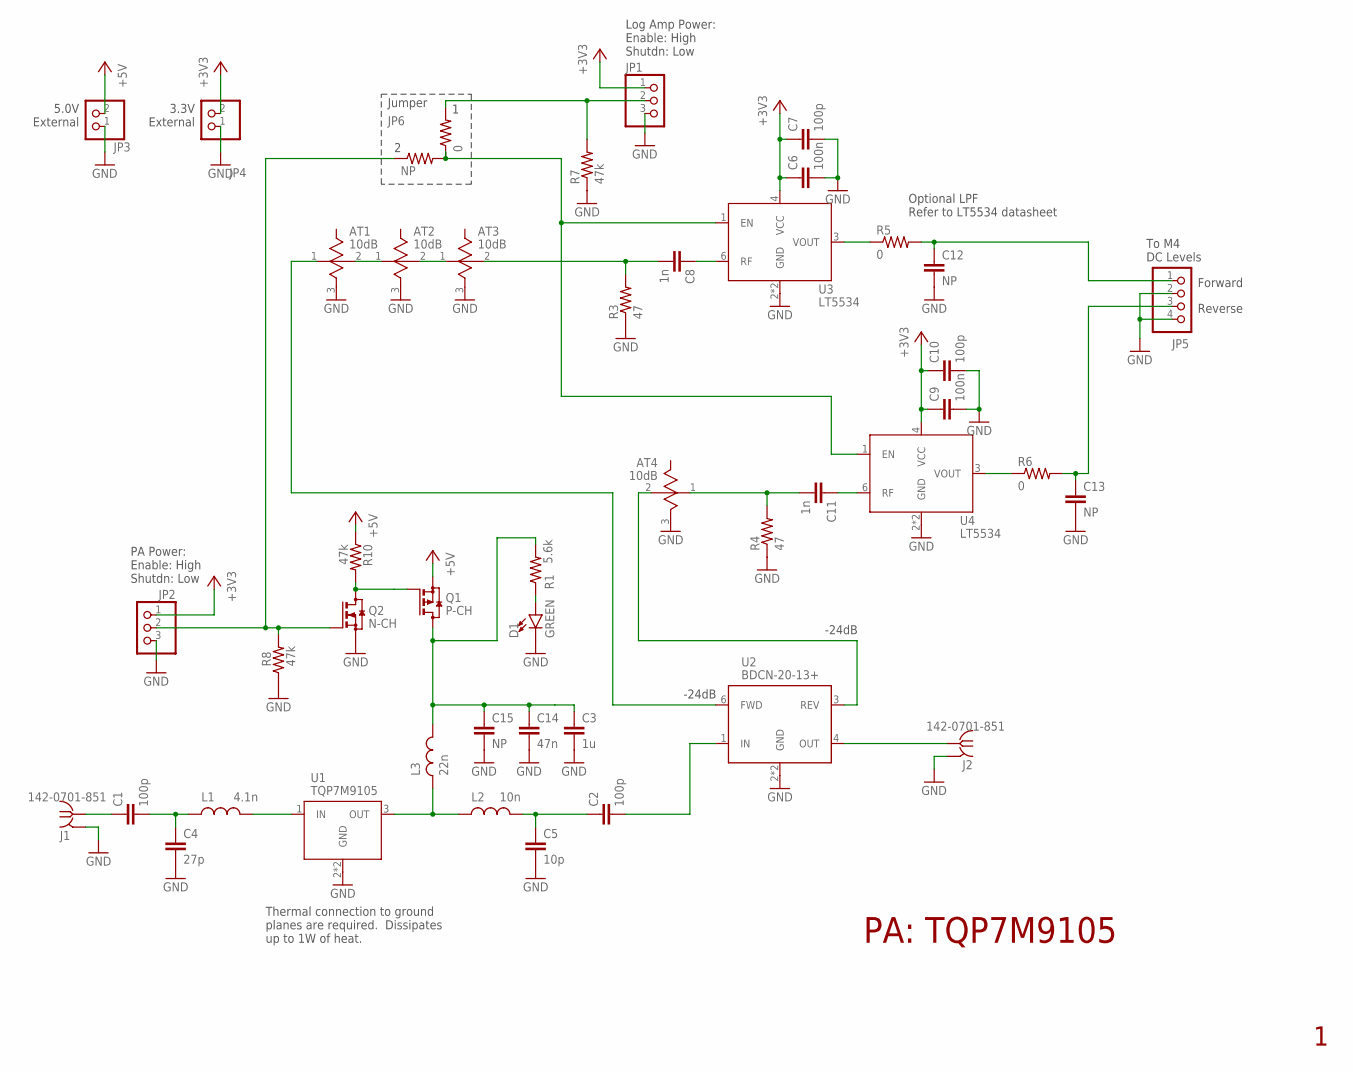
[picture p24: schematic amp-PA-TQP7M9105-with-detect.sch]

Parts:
AT1: 10dB; 0805
AT2, AT3, AT4: 10dB; 0603
C1: 100p; .0402-C-NOSILK
C2: 100p; .0603-C-NOSILK
C3: 1u; .0603-B-NOSILK
C4: 27p; .0402-C-NOSILK
C5: 10p; .0603-C-NOSILK
C6, C9: 100n; .0603-B-NOSILK
C7, C10: 100p; .0603-B-NOSILK
C8, C11: 1n; .0402-C-NOSILK
C12, C13, C15: NP; .0603-B-NOSILK
C14: 47n; .0603-B-NOSILK
D1: GREEN; LED-0603
J1, J2: 142-0701-851
JP1, JP2: PINHD-1X3; 1X03
JP3, JP4: PINHD-1X2; 1X02
JP5: PINHD-1X4; 1X04
JP6: NP; .0603-B-NOSILK
L1: 4.1n; .0402-C-NOSILK
L2: 10n; .0603-C-NOSILK@1
L3: 22n; .0805-C-NOSILK
Q1: P-CH; SOT23
Q2: N-CH; SOT23
R1: 5.6k; .0603-B-NOSILK
R3, R4: 47; .0402-C-NOSILK
R5, R6, R9: 0; .0603-B-NOSILK
R7, R8, R10: 47k; .0402-B-NOSILK
U1: TQP7M9105
U2: BDCN-20-13+
U3, U4: LT5534; SC70

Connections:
+3V3: C6.1, C7.1, C9.1, C10.1, JP1.1, JP2.1, JP4.2, U3.4 (VCC), U4.4 (VCC)
+5V: JP3.2, Q1.2 (S), R10.1
CAPS: C3.1, C14.1, C15.1, L3.2, Q1.3 (D), R1.2
FWD: C12.1, JP5.1, R5.2
GND: AT1.3 (GND), AT2.3 (GND), AT3.3 (GND), AT4.3 (GND), C3.2, C4.2, C5.2, C6.2, C7.2, C9.2, C10.2, C12.2, C13.2, C14.2, C15.2, D1.C, J1.GND1 (GND), J1.GND2 (GND), J1.GND3 (GND), J1.GND4 (GND), J2.GND1 (GND), J2.GND2 (GND), J2.GND3 (GND), J2.GND4 (GND), JP1.3, JP2.3, JP3.1, JP4.1, JP5.2, JP5.4, Q2.2 (S), R3.1, R4.1, R7.1, R8.1, U1.2 (GND), U1.PAD (GND), U2.2 (GND), U2.5 (GND), U3.2 (GND), U3.5 (GND), U4.2 (GND), U4.5 (GND)
unnamed: C1.1, J1.RF1 (RF)
unnamed: C2.2, U2.1 (IN)
unnamed: C1.2, C4.1, L1.1
unnamed: L1.2, U1.1 (IN)
unnamed: L2.1, L3.1, U1.3 (OUT)
unnamed: C2.1, C5.1, L2.2
unnamed: J2.RF1 (RF), U2.4 (OUT)
unnamed: C8.1, U3.6 (RF)
unnamed: AT3.2, C8.2, R3.2
unnamed: JP1.2, R7.2, R9.2
unnamed: C11.1, U4.6 (RF)
unnamed: AT4.1, C11.2, R4.2
unnamed: JP6.2, R9.1, U3.1 (EN), U4.1 (EN)
unnamed: AT1.1, U2.6 (FWD)
unnamed: AT1.2, AT2.1
unnamed: AT2.2, AT3.1
unnamed: R5.1, U3.3 (VOUT)
unnamed: R6.1, U4.3 (VOUT)
unnamed: AT4.2, U2.3 (REV)
unnamed: Q1.1 (G), Q2.3 (D), R10.2
unnamed: JP2.2, JP6.1, Q2.1 (G), R8.2
unnamed: D1.A, R1.1
REV: C13.1, JP5.3, R6.2

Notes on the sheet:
PA: TQP7M9105
Log Amp Power: Enable: High Shutdn: Low
To M4 DC Levels
Forward
Reverse
3.3V External
-24dB
PA Power: Enable: High Shutdn: Low
5.0V External
Optional LPF Refer to LT5534 datasheet
Thermal connection to ground planes are required. Dissipates up to 1W of heat.
Jumper

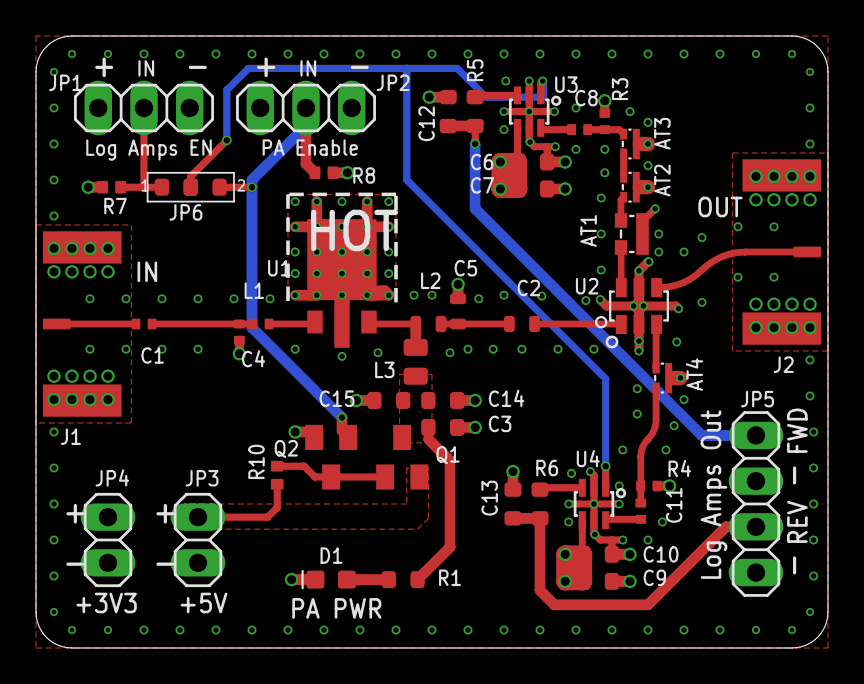
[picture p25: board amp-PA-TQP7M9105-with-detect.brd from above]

Board: 4 copper layers, 44.0 x 34.0 mm, 46 parts (0 on the bottom side), 28 nets.

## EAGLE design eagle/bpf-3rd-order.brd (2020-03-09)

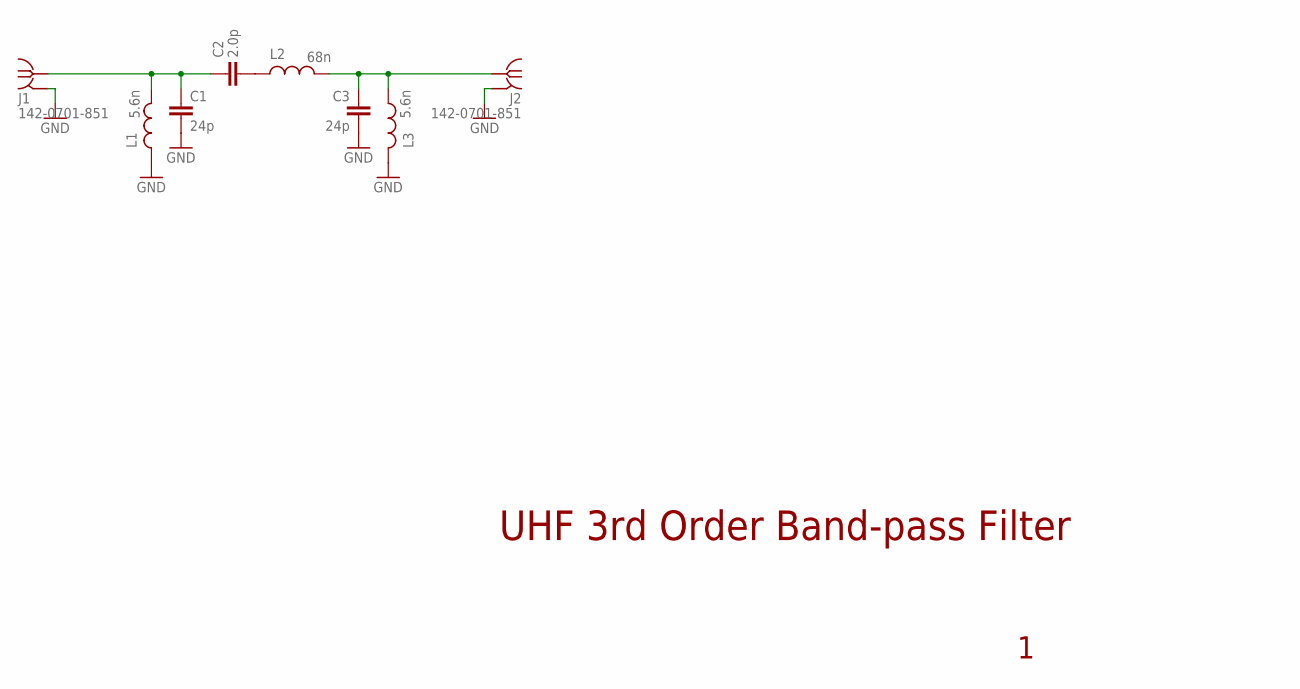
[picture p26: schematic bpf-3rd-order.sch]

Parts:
C1, C3: 24p; .0402-C-NOSILK
C2: 2.0p; .0402-C-NOSILK
J1, J2: 142-0701-851
L1, L3: 5.6n; .0402-C-NOSILK
L2: 68n; .0402-C-NOSILK

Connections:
GND: C1.2, C3.2, J1.GND1 (GND), J1.GND2 (GND), J1.GND3 (GND), J1.GND4 (GND), J2.GND1 (GND), J2.GND2 (GND), J2.GND3 (GND), J2.GND4 (GND), L1.1, L3.1
unnamed: C2.2, L2.1
unnamed: C1.1, C2.1, J1.RF1 (RF), L1.2
unnamed: C3.1, J2.RF1 (RF), L2.2, L3.2

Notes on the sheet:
UHF 3rd Order Band-pass Filter

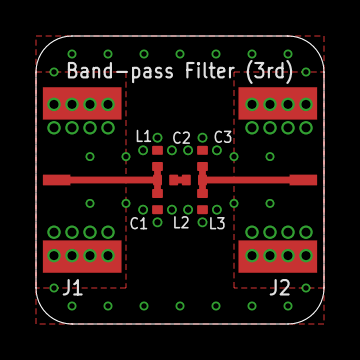
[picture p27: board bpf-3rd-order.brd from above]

Board: 4 copper layers, 16.0 x 16.0 mm, 8 parts (0 on the bottom side), 4 nets.

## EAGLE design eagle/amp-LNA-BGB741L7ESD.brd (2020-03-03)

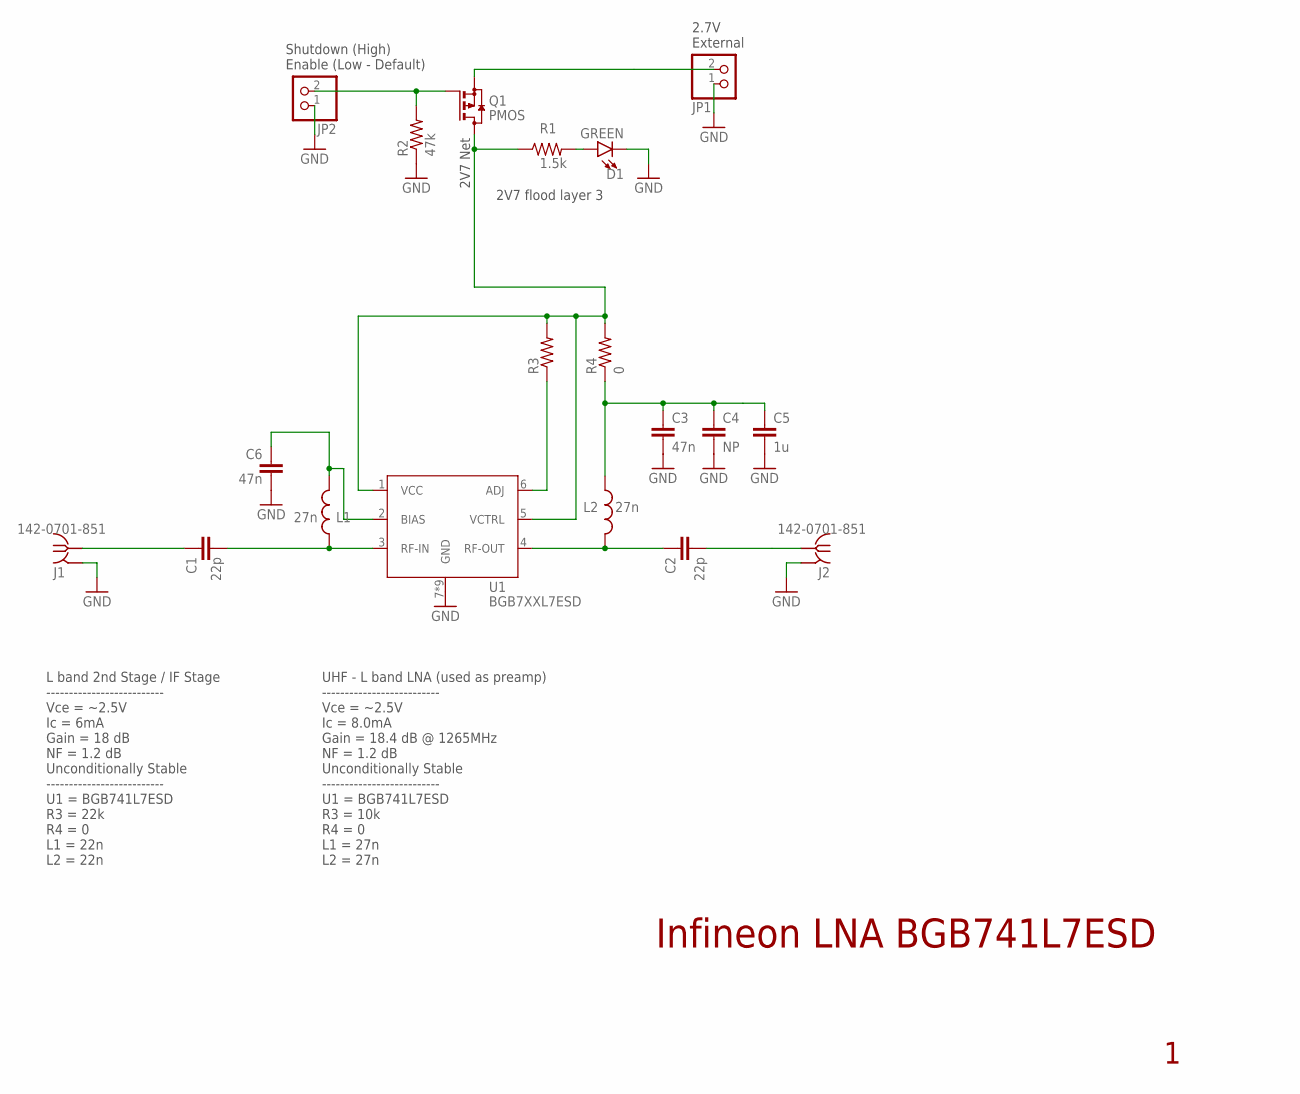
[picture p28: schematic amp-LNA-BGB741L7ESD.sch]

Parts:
C1, C2: 22p; .0402-C-NOSILK
C3, C6: 47n; .0603-B-NOSILK
C4: NP; .0603-B-NOSILK
C5: 1u; .0603-B-NOSILK
D1: GREEN; LED-0603
J1, J2: 142-0701-851
JP1, JP2: PINHD-1X2; 1X02
L1, L2: 27n; .0603-C-NOSILK
Q1: PMOS; SOT23
R1: 1.5k; .0603-B-NOSILK
R2: 47k; .0402-B-NOSILK
R3: 27k / NP; .0603-B-NOSILK
R4: 0; .0603-B-NOSILK
U1: BGB7XXL7ESD

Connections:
2V7: Q1.3 (D), R1.1, R3.2, R4.2, U1.1 (VCC), U1.5 (VCTRL)
GND: C3.2, C4.2, C5.2, C6.2, D1.C, J1.GND1 (GND), J1.GND2 (GND), J1.GND3 (GND), J1.GND4 (GND), J2.GND1 (GND), J2.GND2 (GND), J2.GND3 (GND), J2.GND4 (GND), JP1.1, JP2.1, R2.1, U1.7 (GND), U1.8 (GND), U1.9 (GND), U1.10 (GND), U1.11 (GND), U1.12 (GND), U1.13 (GND), U1.14 (GND), U1.15 (GND)
unnamed: JP2.2, Q1.1 (G), R2.2
unnamed: C3.1, C4.1, C5.1, L2.1, R4.1
unnamed: C2.1, L2.2, U1.4 (RF-OUT)
unnamed: R3.1, U1.6 (ADJ)
unnamed: C6.1, L1.2, U1.2 (BIAS)
unnamed: D1.A, R1.2
unnamed: C1.2, L1.1, U1.3 (RF-IN)
RF-IN: C1.1, J1.RF1 (RF)
RF_OUT: C2.2, J2.RF1 (RF)
VEXT: JP1.2, Q1.2 (S)

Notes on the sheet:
Infineon LNA BGB741L7ESD
2.7V External
Shutdown (High) Enable (Low - Default)
2V7 flood layer 3
2V7 Net
L band 2nd Stage / IF Stage -------------------------- Vce = ~2.5V Ic = 6mA Gain = 18 dB NF = 1.2 dB Unconditionally Stable -------------------------- U1 = BGB741L7ESD R3 = 22k R4 = 0 L1 = 22n L2 = 22n
UHF - L band LNA (used as preamp) -------------------------- Vce = ~2.5V Ic = 8.0mA Gain = 18.4 dB @ 1265MHz NF = 1.2 dB Unconditionally Stable -------------------------- U1 = BGB741L7ESD R3 = 10k R4 = 0 L1 = 27n L2 = 27n

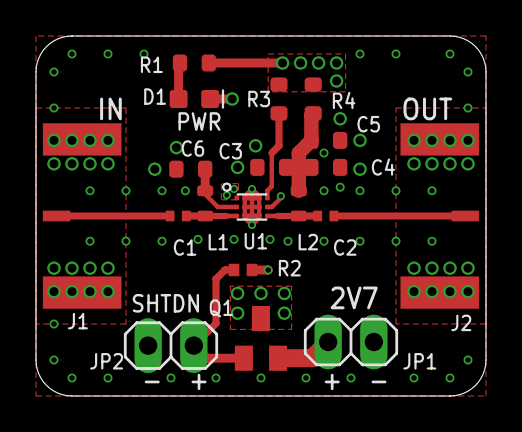
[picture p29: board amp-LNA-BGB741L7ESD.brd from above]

Board: 4 copper layers, 25.0 x 20.0 mm, 19 parts (0 on the bottom side), 12 nets.

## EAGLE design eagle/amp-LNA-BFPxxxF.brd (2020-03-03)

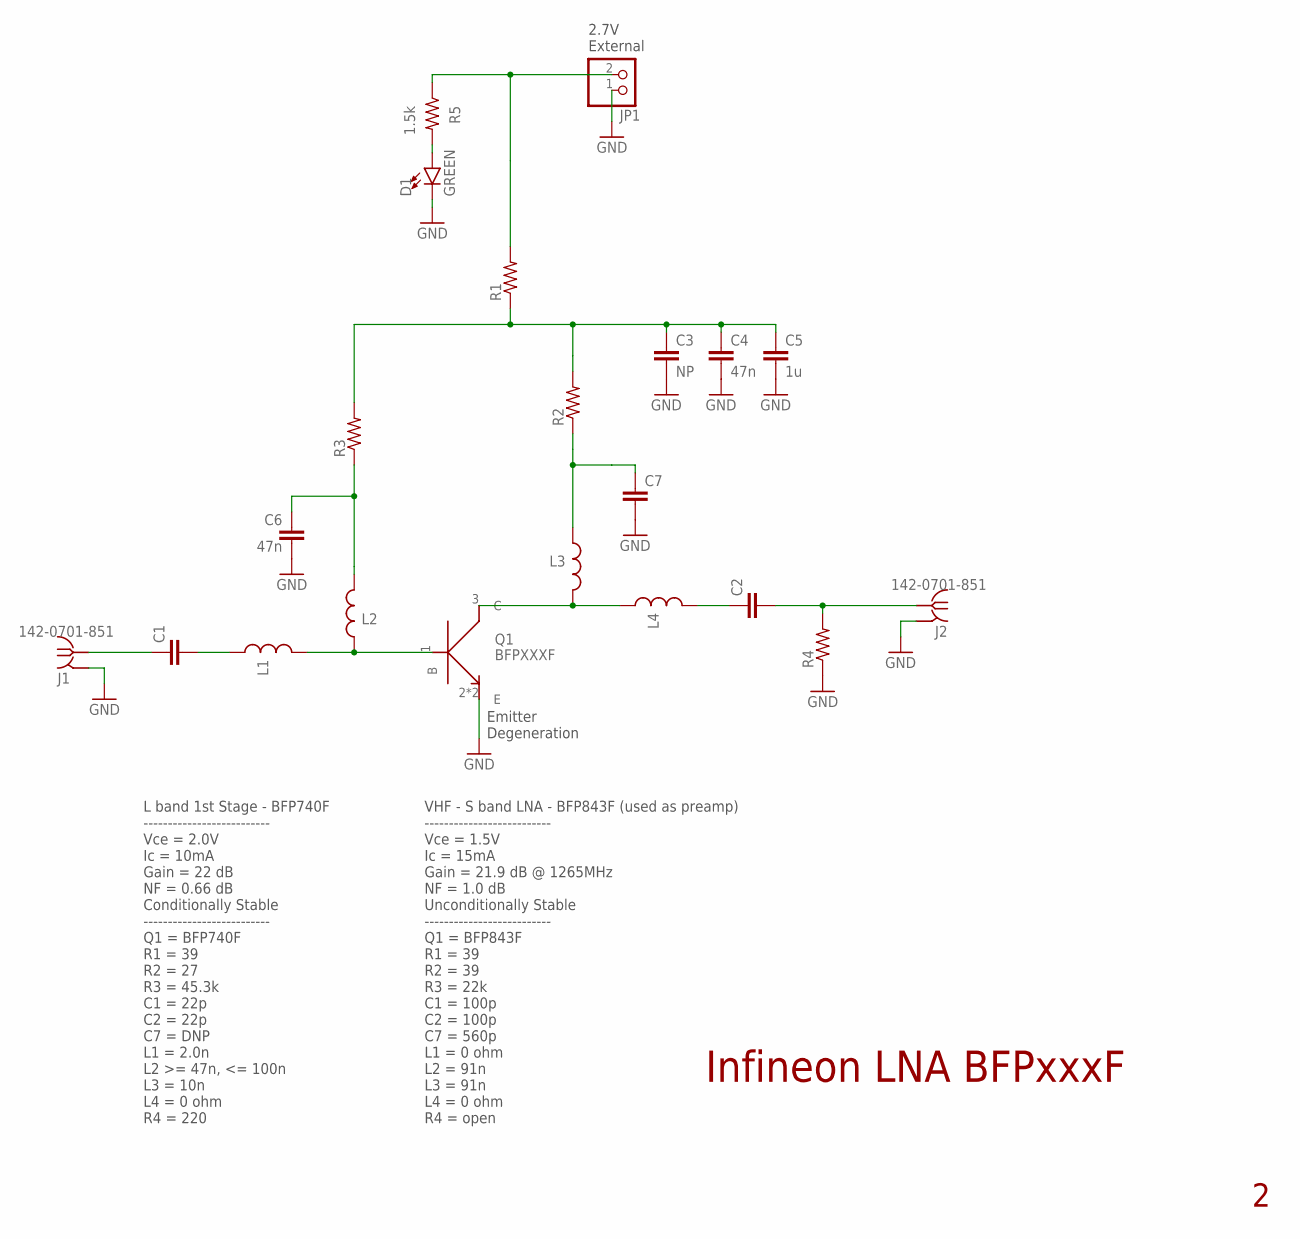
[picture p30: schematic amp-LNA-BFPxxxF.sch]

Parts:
C1, C2: C-EU0402-C-NOSILK; .0402-C-NOSILK
C3: NP; .0603-C-NOSILK
C4, C6: 47n; .0603-C-NOSILK
C5: 1u; .0603-C-NOSILK
C7: C-EU0402-B-NOSILK; .0402-B-NOSILK
D1: GREEN; LED-0603
J1, J2: 142-0701-851
JP1: PINHD-1X2; 1X02
L1, L4: L-US0402-C-NOSILK; .0402-C-NOSILK
L2, L3: L-US0603-C-NOSILK; .0603-C-NOSILK
Q1: BFPXXXF; TSFP4
R1, R2, R3, R4: R-US_0603-C-NOSILK; .0603-C-NOSILK
R5: 1.5k; .0603-C-NOSILK

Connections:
2V7: JP1.2, R1.2, R5.1
B: L1.2, L2.1, Q1.1 (B)
C: L3.2, L4.1, Q1.3 (C)
CAPS: C3.1, C4.1, C5.1, R1.1, R2.2, R3.2
GND: C3.2, C4.2, C5.2, C6.2, C7.2, D1.C, J1.GND1 (GND), J1.GND2 (GND), J1.GND3 (GND), J1.GND4 (GND), J2.GND1 (GND), J2.GND2 (GND), J2.GND3 (GND), J2.GND4 (GND), JP1.1, Q1.2 (E), Q1.4 (E), R4.1
unnamed: C2.1, L4.2
unnamed: C1.2, L1.1
unnamed: C7.1, L3.1, R2.1
unnamed: C6.1, L2.2, R3.1
unnamed: D1.A, R5.2
RF_IN: C1.1, J1.RF1 (RF)
RF_OUT: C2.2, J2.RF1 (RF), R4.2

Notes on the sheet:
Infineon LNA BFPxxxF
2.7V External
L band 1st Stage - BFP740F -------------------------- Vce = 2.0V Ic = 10mA Gain = 22 dB NF = 0.66 dB Conditionally Stable -------------------------- Q1 = BFP740F R1 = 39 R2 = 27 R3 = 45.3k C1 = 22p C2 = 22p C7 = DNP L1 = 2.0n L2 >= 47n, <= 100n L3 = 10n L4 = 0 ohm R4 = 220
Emitter Degeneration
VHF - S band LNA - BFP843F (used as preamp) -------------------------- Vce = 1.5V Ic = 15mA Gain = 21.9 dB @ 1265MHz NF = 1.0 dB Unconditionally Stable -------------------------- Q1 = BFP843F R1 = 39 R2 = 39 R3 = 22k C1 = 100p C2 = 100p C7 = 560p L1 = 0 ohm L2 = 91n L3 = 91n L4 = 0 ohm R4 = open

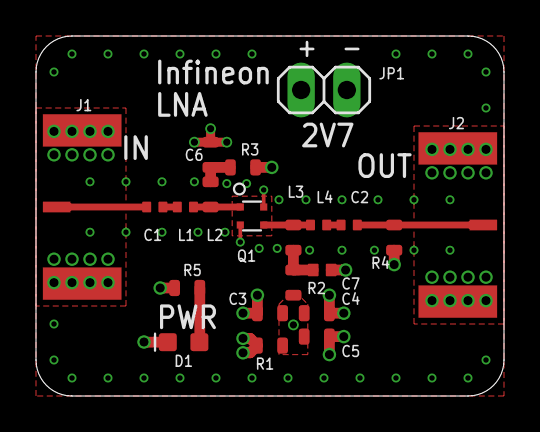
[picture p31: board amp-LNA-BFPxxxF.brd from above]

Board: 4 copper layers, 26.0 x 20.0 mm, 21 parts (0 on the bottom side), 12 nets.

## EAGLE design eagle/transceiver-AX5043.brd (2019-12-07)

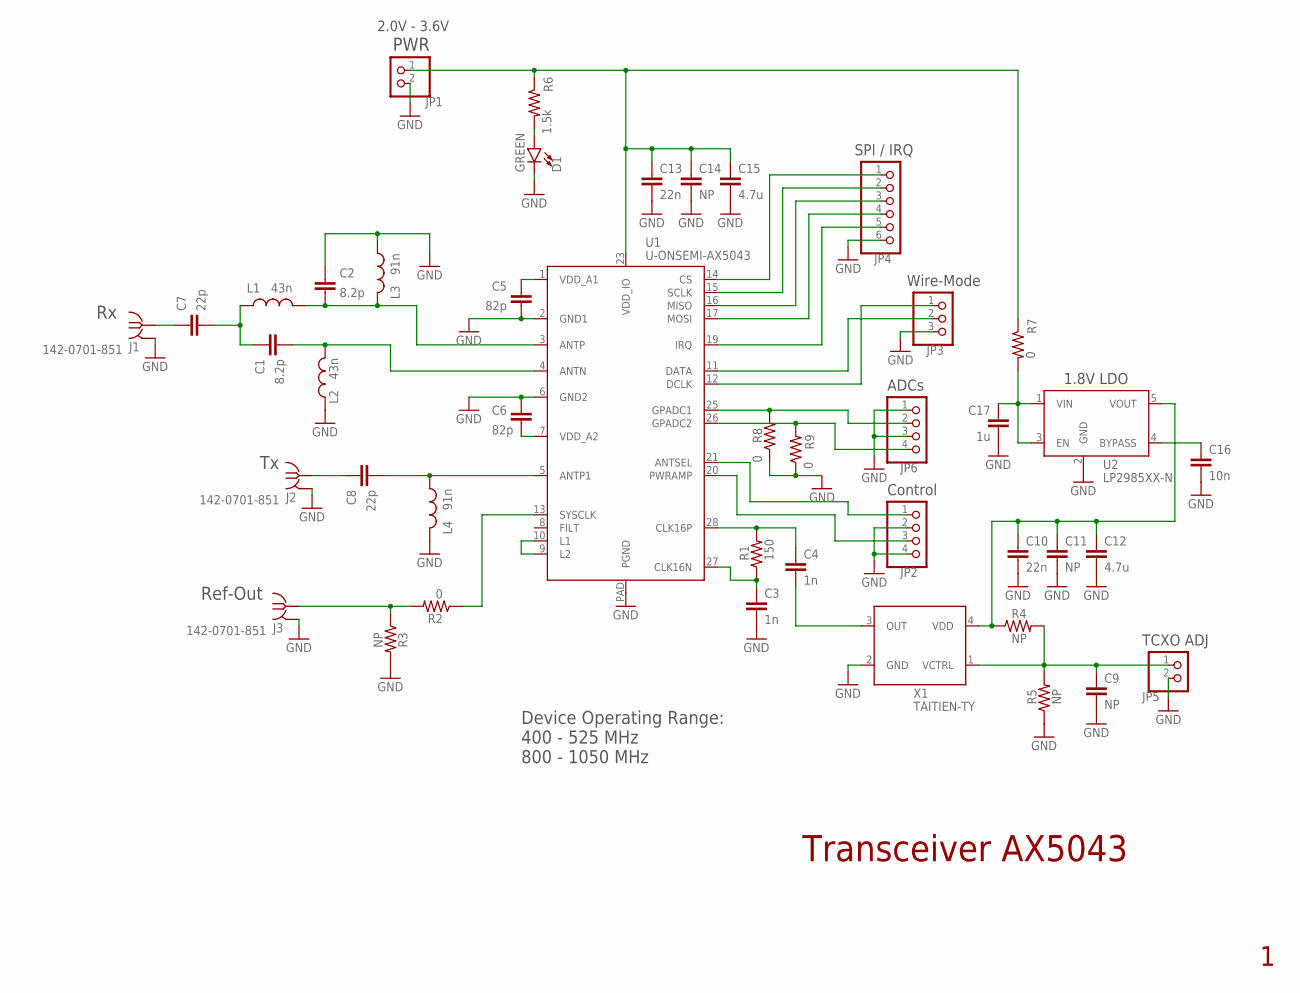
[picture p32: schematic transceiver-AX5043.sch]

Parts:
C1, C2: 8.2p; .0402-C-NOSILK
C3, C4: 1n; .0402-C-NOSILK
C5, C6: 82p; .0402-C-NOSILK
C7, C8: 22p; .0402-C-NOSILK
C9, C11, C14: NP; .0603-C-NOSILK
C10, C13: 22n; .0603-C-NOSILK
C12, C15: 4.7u; .0603-C-NOSILK
C16: 10n; .0603-C-NOSILK
C17: 1u; .0603-C-NOSILK
D1: GREEN; LED-0603
J1, J2, J3: 142-0701-851
JP1, JP5: PINHD-1X2; 1X02
JP2, JP6: PINHD-1X4; 1X04
JP3: PINHD-1X3; 1X03
JP4: PINHD-1X6; 1X06
L1, L2: 43n; .0402-C-NOSILK
L3, L4: 91n; .0603-C-NOSILK
R1: 150; .0402-C-NOSILK
R2, R8, R9: 0; .0402-C-NOSILK
R3: NP; .0402-C-NOSILK
R4, R5: NP; .0603-B-NOSILK
R6: 1.5k; .0603-B-NOSILK
R7: 0; .0603-C-NOSILK
U1: U-ONSEMI-AX5043; QFN28-5X5-WITH-CENTER-PAD
U2: LP2985XX-N; SOT-23
X1: TAITIEN-TY; 2.5X2.0

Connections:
1V8: C10.1, C11.1, C12.1, R4.1, U2.5 (VOUT), X1.4 (VDD)
2V7: C13.1, C14.1, C15.1, JP1.1, R6.1, R7.1, U1.23 (VDD_IO)
ADC1: JP6.2, R8.2, U1.25 (GPADC1)
ADC2: JP6.4, R9.2, U1.26 (GPADC2)
ANTN: C1.2, L2.2, U1.4 (ANTN)
ANTP: C2.2, L1.2, L3.1, U1.3 (ANTP)
ANTP1: C8.2, L4.2, U1.5 (ANTP1)
ANTSEL: JP2.1, U1.21 (ANTSEL)
CLKN: C3.1, R1.1, U1.27 (CLK16N)
CLKP: C4.1, R1.2, U1.28 (CLK16P)
CS: JP4.1, U1.14 (CS)
DATA: JP3.2, U1.11 (DATA)
DCLK: JP3.1, U1.12 (DCLK)
GND: C2.1, C3.2, C5.2, C6.1, C9.2, C10.2, C11.2, C12.2, C13.2, C14.2, C15.2, C16.2, C17.2, D1.C, J1.GND1 (GND), J1.GND2 (GND), J1.GND3 (GND), J1.GND4 (GND), J2.GND1 (GND), J2.GND2 (GND), J2.GND3 (GND), J2.GND4 (GND), J3.GND1 (GND), J3.GND2 (GND), J3.GND3 (GND), J3.GND4 (GND), JP1.2, JP2.2, JP2.4, JP3.3, JP4.6, JP5.2, JP6.1, JP6.3, L2.1, L3.2, L4.1, R3.2, R5.1, R8.1, R9.1, U1.2 (GND1), U1.6 (GND2), U1.PAD (PGND), U2.2 (GND), X1.2 (GND)
IRQ: JP4.5, U1.19 (IRQ)
MISO: JP4.3, U1.16 (MISO)
MOSI: JP4.4, U1.17 (MOSI)
unnamed: C5.1, U1.1 (VDD_A1)
unnamed: C17.1, R7.2, U2.1 (VIN), U2.3 (EN)
unnamed: U1.9 (L2), U1.10 (L1)
unnamed: C4.2, X1.3 (OUT)
unnamed: C1.1, C7.2, L1.1
unnamed: C9.1, JP5.1, R4.2, R5.2, X1.1 (VCTRL)
unnamed: D1.A, R6.2
unnamed: C16.1, U2.4 (BYPASS)
unnamed: C6.2, U1.7 (VDD_A2)
PWRAMP: JP2.3, U1.20 (PWRAMP)
REF-OUT: J3.RF1 (RF), R2.2, R3.1
RX: C7.1, J1.RF1 (RF)
SCLK: JP4.2, U1.15 (SCLK)
SYSCLK: R2.1, U1.13 (SYSCLK)
TX: C8.1, J2.RF1 (RF)

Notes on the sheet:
Transceiver AX5043
Ref-Out
PWR
SPI / IRQ
Wire-Mode
Control
TCXO ADJ
1.8V LDO
ADCs
Device Operating Range: 400 - 525 MHz 800 - 1050 MHz
2.0V - 3.6V

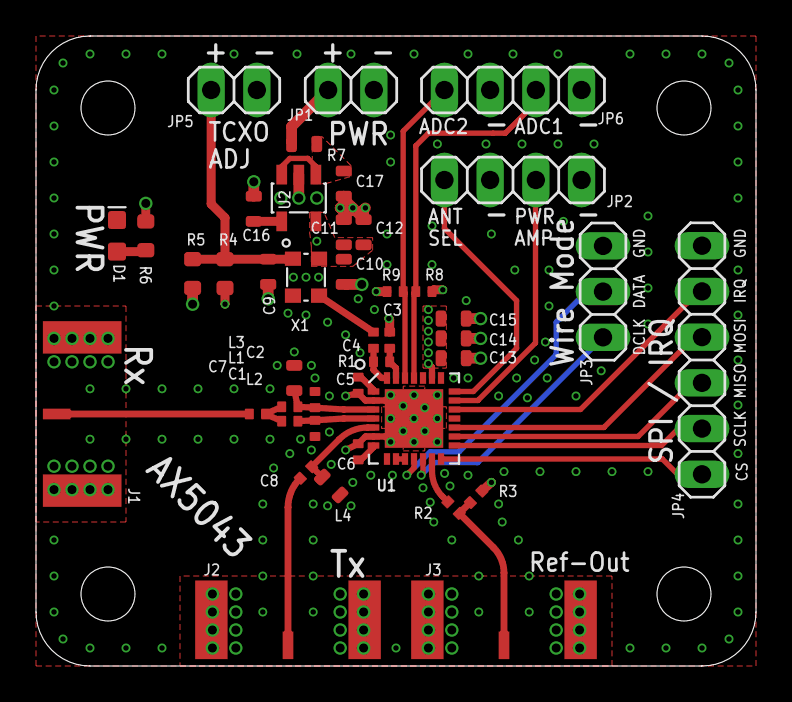
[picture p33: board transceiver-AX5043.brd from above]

Board: 4 copper layers, 40.0 x 35.0 mm, 43 parts (0 on the bottom side), 32 nets.

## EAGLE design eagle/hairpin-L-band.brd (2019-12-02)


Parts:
J1, J2: 142-0701-851_TEST
U$1, U$2, U$3, U$4, U$5, U$6: PAD_0.6; 0.6MM
U$7, U$8, U$9, U$10, U$11, U$12: PAD_0.6_B; 0.6MM_B

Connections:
BLEFT: J2.RF2, U$11.END, U$12.END
BMID: U$9.END, U$10.END
BRIGHT: J1.RF2, U$7.END, U$8.END
GND: J1.GND1 (GND), J1.GND2 (GND), J1.GND3 (GND), J1.GND4 (GND), J2.GND1 (GND), J2.GND2 (GND), J2.GND3 (GND), J2.GND4 (GND)
TLEFT: J2.RF1, U$5.END, U$6.END
TMID: U$3.END, U$4.END
TRIGHT: J1.RF1, U$1.END, U$2.END

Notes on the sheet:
L band Hairpin Filters
Top layer Center: 1265 MHz BW3dB: BW30dB:
Bottom Layer Center: 1205 MHz BW3dB: BW30dB:


Board: 4 copper layers, 27.0 x 41.0 mm, 14 parts (0 on the bottom side), 7 nets.

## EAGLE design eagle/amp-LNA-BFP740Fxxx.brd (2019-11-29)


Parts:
C1, C2: 22p; .0402-C-NOSILK
C3: NP; .0603-C-NOSILK
C4, C8: 47n; .0603-C-NOSILK
C5: 1u; .0603-C-NOSILK
C6: NP; .0402-B-NOSILK
D1: GREEN; LED-0603
J1, J2: 142-0701-851
JP1, JP2: PINHD-1X2; 1X02
L1: 47n; .0603-C-NOSILK
L2: 10n; .0603-C-NOSILK
L3: 1.8n; .0402-C-NOSILK
Q1: PMOS; SOT23
Q2: BFP740F; TSFP4
R1: 1.5k; .0603-C-NOSILK
R2: 45.3k; .0603-C-NOSILK
R3: 47k; .0402-B-NOSILK
R4: 39; .0603-C-NOSILK
R5: 27; .0603-C-NOSILK
R6: 220; .0603-C-NOSILK

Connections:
2V7: Q1.3 (D), R1.1, R4.2
B: L1.1, L3.2, Q2.1 (B)
C: C2.1, L2.2, Q2.3 (C)
CAPS: C3.1, C4.1, C5.1, R2.2, R4.1, R5.2
GND: C3.2, C4.2, C5.2, C6.2, C8.2, D1.C, J1.GND1 (GND), J1.GND2 (GND), J1.GND3 (GND), J1.GND4 (GND), J2.GND1 (GND), J2.GND2 (GND), J2.GND3 (GND), J2.GND4 (GND), JP1.1, JP2.1, Q2.2 (E), Q2.4 (E), R3.1, R6.1
unnamed: JP2.2, Q1.1 (G), R3.2
unnamed: C1.2, L3.1
unnamed: C6.1, L2.1, R5.1
unnamed: C8.1, L1.2, R2.1
unnamed: D1.A, R1.2
RF_IN: C1.1, J1.RF1 (RF)
RF_OUT: C2.2, J2.RF1 (RF), R6.2
VEXT: JP1.2, Q1.2 (S)

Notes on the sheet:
L band LNA BFP740F
2.7V External
Shutdown (High) Enable (Low - Default)
2V7 Net
Notes ------------ Vce=2.0V, Ic=10mA, for NFmin R4 = 39 R2 = 45.3k - Layout ideal for min NF or max G_T


Board: 4 copper layers, 26.0 x 20.0 mm, 23 parts (0 on the bottom side), 13 nets.

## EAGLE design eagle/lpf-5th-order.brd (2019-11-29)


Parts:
C1, C2, C3: C-EU0402-C-NOSILK; .0402-C-NOSILK
J1, J2: 142-0701-851
L1, L2: L-US0402-C-NOSILK; .0402-C-NOSILK

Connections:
GND: C1.2, C2.2, C3.2, J1.GND1 (GND), J1.GND2 (GND), J1.GND3 (GND), J1.GND4 (GND), J2.GND1 (GND), J2.GND2 (GND), J2.GND3 (GND), J2.GND4 (GND)
unnamed: C2.1, L1.2, L2.1
RF-IN: C1.1, J1.RF1 (RF), L1.1
RF-OUT: C3.1, J2.RF1 (RF), L2.2

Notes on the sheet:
5th Order Low-pass Filter


Board: 4 copper layers, 16.0 x 16.0 mm, 7 parts (0 on the bottom side), 4 nets.

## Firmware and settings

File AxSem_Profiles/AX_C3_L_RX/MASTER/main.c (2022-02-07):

/**
*******************************************************************************************************
* @file MASTER\main.c
* @brief Code skeleton for MASTER module, illustrating periodic or on-demand transmission of packets.
*        The packet format is determined by AX-RadioLAB_output\config.c, produced by the AX-RadioLab GUI
* @internal
* @author   Thomas Sailer, Janani Chellappan, Srinivasan Tamilarasan, Pradeep Kumar GR
* $Rev: $
* $Date: $
********************************************************************************************************
* Copyright 2016 Semiconductor Components Industries LLC (d/b/a “ON Semiconductor”).
* All rights reserved.  This software and/or documentation is licensed by ON Semiconductor
* under limited terms and conditions.  The terms and conditions pertaining to the software
* and/or documentation are available at http://www.onsemi.com/site/pdf/ONSEMI_T&C.pdf
* (“ON Semiconductor Standard Terms and Conditions of Sale, Section 8 Software”) and
* if applicable the software license agreement.  Do not use this software and/or
* documentation unless you have carefully read and you agree to the limited terms and
* conditions.  By using this software and/or documentation, you agree to the limited
* terms and conditions.
*
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
* @ingroup TEMPLATE_FIRMWARE_504x
*
* @details
*/

#include "../AX_Radio_Lab_output/configmaster.h"
/* axm0_uart req for both; remove warnings */
#include <ax8052.h>
#include <libmftypes.h>
#include <libmfradio.h>
#include <libmfflash.h>
#include <libmfwtimer.h>
#include "libmfosc.h"
#ifdef USE_COM0
#include <libmfuart0.h>
#endif /* USE_COM0 */
#ifdef USE_LCD
#include <libaxlcd2.h>
#endif /* USE_LCD */
#ifdef USE_DBGLINK
#include <libmfdbglink.h>
#include <libmfuart.h>
#include <libmfuart0.h>
#include <libmfuart1.h>
#endif /* USE_DBGLINK */
#if defined(USE_LCD) || defined(USE_COM0)
#define USE_DISPLAY
#endif /* defined(USE_LCD) || defined(USE_COM0) */
#include "../COMMON/display_com0.h"
#include <libdvk2leds.h>
#define BUTTON_INTCHG INTCHGB
#define BUTTON_PIN    PINB
#define BUTTON_MASK   0x04
#include <string.h>
#include "../COMMON/misc.h"
#include "../COMMON/configcommon.h"

extern uint8_t _start__stack[];
uint16_t __data pkt_counter = 0;
uint8_t __data coldstart = 1; /* caution: initialization with 1 is necessary! Variables are initialized upon _sdcc_external_startup returning 0 -> the coldstart value returned from _sdcc_external startup does not survive in the coldstart case */
#ifdef TX_ON_DEMAND
__bit deglitch_busy = 0;
#endif

struct wtimer_desc __xdata wakeup_desc;

static void pwrmgmt_irq(void) __interrupt(INT_POWERMGMT)
{
    uint8_t pc = PCON;

    if (!(pc & 0x80))
        return;

    GPIOENABLE = 0;
    IE = EIE = E2IE = 0;

    for (;;)
        PCON |= 0x01;
}

static void transmit_packet(void)
{
    static uint8_t __xdata demo_packet_[sizeof(demo_packet)];

    ++pkt_counter;
    memcpy(demo_packet_, demo_packet, sizeof(demo_packet));

    if (framing_insert_counter)
    {
        demo_packet_[framing_counter_pos] = pkt_counter & 0xFF ;
        demo_packet_[framing_counter_pos+1] = (pkt_counter>>8) & 0xFF;
    }

    axradio_transmit(&remoteaddr, demo_packet_, sizeof(demo_packet));
}

static void display_transmit_packet(void)
{
    if (pkt_counter == 1)
    {
        display_setpos(0x40);
        display_writestr("TX    ");
#ifdef USE_DBGLINK

        if (DBGLNKSTAT & 0x10)
            dbglink_writestr("TX : \n");

#endif /* USE_DBGLINK */
    }

    display_setpos(0x4c);
    display_writehex16(pkt_counter, 4, WRNUM_PADZERO);
#ifdef USE_DBGLINK

    if (DBGLNKSTAT & 0x10)
    {
        dbglink_writehex16(pkt_counter, 4, WRNUM_PADZERO);
        dbglink_tx('\n');
    }

#endif /* USE_DBGLINK */
}

void axradio_statuschange(struct axradio_status __xdata *st)
{
#if defined(USE_DBGLINK) && defined(DEBUGMSG)
    if (DBGLNKSTAT & 0x10)
    {
        dbglink_writestr("ST: 0x");
        dbglink_writehex16(st->status, 2, WRNUM_PADZERO);
        dbglink_writestr(" ERR: 0x");
        dbglink_writehex16(st->error, 2, WRNUM_PADZERO);
        dbglink_tx('\n');
    }

#endif
    switch (st->status)
    {
    case AXRADIO_STAT_TRANSMITSTART:
        led0_on();

        if (st->error == AXRADIO_ERR_RETRANSMISSION)
            led2_on();

#ifdef TX_ON_DEMAND

        if( st->error = AXRADIO_ERR_TIMEOUT )
            deglitch_busy = 0;

#endif
#if RADIO_MODE == AXRADIO_MODE_SYNC_MASTER || RADIO_MODE == AXRADIO_MODE_SYNC_ACK_MASTER
        display_transmit_packet();
#endif
        break;

    case AXRADIO_STAT_TRANSMITEND:
        led0_off();

        if (st->error == AXRADIO_ERR_NOERROR)
        {
            led2_off();
#ifdef TX_ON_DEMAND
            deglitch_busy = 0;
#endif
#if RADIO_MODE == AXRADIO_MODE_ACK_TRANSMIT || RADIO_MODE == AXRADIO_MODE_WOR_ACK_TRANSMIT || RADIO_MODE == AXRADIO_MODE_SYNC_ACK_MASTER
            display_setpos(0x0d);
            display_writestr(":-)");
#ifdef USE_DBGLINK

            if (DBGLNKSTAT & 0x10)
                dbglink_writestr(":-)\n");

#endif /* USE_DBGLINK */
#endif /* RADIO_MODE */
        }
        else if (st->error == AXRADIO_ERR_TIMEOUT)
        {
            led2_on();
#if RADIO_MODE == AXRADIO_MODE_ACK_TRANSMIT || RADIO_MODE == AXRADIO_MODE_WOR_ACK_TRANSMIT || RADIO_MODE == AXRADIO_MODE_SYNC_ACK_MASTER
            display_setpos(0x0d);
            display_writestr(":-(");
#ifdef USE_DBGLINK

            if (DBGLNKSTAT & 0x10)
                dbglink_writestr(":-(\n");

#endif /* USE_DBGLINK */
#endif /* RADIO_MODE */
        }

        if (st->error == AXRADIO_ERR_BUSY)
            led3_on();
        else
            led3_off();

        break;
#if RADIO_MODE == AXRADIO_MODE_SYNC_MASTER || RADIO_MODE == AXRADIO_MODE_SYNC_ACK_MASTER

    case AXRADIO_STAT_TRANSMITDATA:
        /* in SYNC_MASTER mode, transmit data may be prepared between the call to TRANSMITEND until the call to TRANSMITSTART */
        /* TRANSMITDATA is called when the crystal oscillator is enabled, approximately 1ms before transmission */
        transmit_packet();
        break;
#endif

    case AXRADIO_STAT_CHANNELSTATE:
        if (st->u.cs.busy)
            led3_on();
        else
            led3_off();

        break;

    default:
        break;
    }
}

void enable_radio_interrupt_in_mcu_pin(void)
{
	IE_4 = 1;
}

void disable_radio_interrupt_in_mcu_pin(void)
{
	IE_4 = 0;
}

static void wakeup_callback(struct wtimer_desc __xdata *desc)
{
    desc;
#if defined(WTIMER0_PERIOD)
    wakeup_desc.time += wtimer0_correctinterval(WTIMER0_PERIOD);
    wtimer0_addabsolute(&wakeup_desc);
    transmit_packet();
    display_transmit_packet();
#endif
}

uint8_t _sdcc_external_startup(void)
{
    LPXOSCGM = 0x8A;
    wtimer0_setclksrc(WTIMER0_CLKSRC, WTIMER0_PRESCALER);
    wtimer1_setclksrc(CLKSRC_FRCOSC, 7);

    LPOSCCONFIG = 0x09; /* Slow, PRESC /1, no cal. Does NOT enable LPOSC. LPOSC is enabled upon configuring WTCFGA (MODE_TX_PERIODIC and receive_ack() ) */

    coldstart = !(PCON & 0x40);

    ANALOGA = 0x18; /* PA[3,4] LPXOSC, other PA are used as digital pins */
    PORTA = 0xC0 | (PINA & 0x25); 	/* pull-up for PA[6,7] which are not bonded, no pull up for PA[3,4] (LPXOSC). Output 0 in PA[0,1,2,5] to prevent current consumption in all DIP switch states */
    /* init LEDs to previous (frozen) state */
    PORTB = 0xFE; /*PB[0,1]  (LCD RS, LCD RST) are overwritten by lcd2_portinit(), enable pull-ups for PB[2..7]  (PB[2,3] for buttons, PB[4..7] unused) */
    PORTC = 0xF3 | (PINC & 0x08); 	/* set PC0 = 1 (LCD SEL), PC1 = 1 (LCD SCK), PC2 = 0 (LCD MOSI), PC3 =0 (LED), enable pull-ups for PC[4..7] which are not bonded Mind: PORTC[0:1] is set to 0x3 by lcd2_portinit() */
    /* init LEDs to previous (frozen) state */
    PORTR = 0xCB; /* overwritten by ax504x_reset, ax504x_comminit() */

    DIRA = 0x27; /* output 0 on PA[0,1,2,5] to prevent current consumption in all DIP switch states. Other PA are inputs, PA[3,4] (LPXOSC) must have disabled digital output drivers */
    DIRB = 0x03; /* PB[0,1] are outputs (LCD RS, LCD RST), PB[2..7] are inputs (PB[2,3] for buttons,  PB[4..7]  unused) */
    DIRC = 0x0F; /* PC[0..3] are outputs (LCD SEL, LCD,SCK, LCD MOSI, LED), PC[4..7] are inputs (not bonded). */
    DIRR = 0x15; /* overwritten by ax504x_reset, ax504x_comminit() */
    axradio_setup_pincfg1();
    DPS = 0;
    IE = 0x40;
    EIE = 0x00;
    E2IE = 0x00;

    display_portinit();
    GPIOENABLE = 1; /* unfreeze GPIO */
    return !coldstart; /* coldstart -> return 0 -> var initialization; start from sleep -> return 1 -> no var initialization */
}

int main(void)
{
    uint8_t i;
    static uint8_t __data saved_button_state = 0xFF;
    __asm
    G$_start__stack$0$0 = __start__stack
                          .globl G$_start__stack$0$0
                          __endasm;
#ifdef USE_DBGLINK
    dbglink_init();
#endif
    __enable_irq();
    flash_apply_calibration();
    CLKCON = 0x00;
    wtimer_init();

    if (coldstart)
    {
        led0_off();
        led1_off();
        led2_off();
        led3_off();

        wakeup_desc.handler = wakeup_callback;
#ifdef TX_ON_DEMAND
        BUTTON_INTCHG |= BUTTON_MASK;   /*interrupt on button changed (button SW5 on DVK-2) for wake on button pressed */
#endif /* TX_ON_DEMAND */
        display_init();
        display_setpos(0);
        i = axradio_init();

        if (i != AXRADIO_ERR_NOERROR)
        {
            if (i == AXRADIO_ERR_NOCHIP)
            {
                display_writestr(radio_not_found_lcd_display);
#ifdef USE_DBGLINK

                if(DBGLNKSTAT & 0x10)
                    dbglink_writestr(radio_not_found_lcd_display);

#endif /* USE_DBGLINK */
                goto terminate_error;
            }

            goto terminate_radio_error;
        }

        display_writestr(radio_lcd_display);
#ifdef USE_DBGLINK

        if (DBGLNKSTAT & 0x10)
            dbglink_writestr(radio_lcd_display);

#endif /* USE_DBGLINK */
        axradio_set_local_address(&localaddr);
        axradio_set_default_remote_address(&remoteaddr);
#if RADIO_MODE == AXRADIO_MODE_SYNC_MASTER || RADIO_MODE == AXRADIO_MODE_SYNC_ACK_MASTER || RADIO_MODE == AXRADIO_MODE_SYNC_SLAVE || RADIO_MODE == AXRADIO_MODE_SYNC_ACK_SLAVE
        display_writestr("settle LPXOSC");
#ifdef USE_DBGLINK

        if (DBGLNKSTAT & 0x10)
            dbglink_writestr("settle LPXOSC\n");

#endif /* USE_DBGLINK */
        delay_ms(lpxosc_settlingtime);
        display_clear(0x40, 16);
        display_setpos(0x40);
#endif  /* RADIO_MODE */
#ifdef USE_DISPLAY
        display_writestr("RNG=");
        display_writenum16(axradio_get_pllrange(), 2, 0);
        {
            uint8_t x = axradio_get_pllvcoi();

            if (x & 0x80)
            {
                display_writestr(" VCOI=");
                display_writehex16(x, 2, 0);
            }
        }
        delay_ms(1000); /* just to show PLL RNG */
        display_clear(0, 16);
        display_clear(0x40, 16);
        display_setpos(0);
        display_writestr("MASTER");
#endif /* USE_DISPLAY */
#ifdef USE_DBGLINK

        if (DBGLNKSTAT & 0x10)
        {
            dbglink_writestr("RNG = ");
            dbglink_writenum16(axradio_get_pllrange(), 2, 0);
            {
                uint8_t x = axradio_get_pllvcoi();

                if (x & 0x80)
                {
                    dbglink_writestr("\nVCOI = ");
                    dbglink_writehex16(x, 2, 0);
                }
            }
            dbglink_writestr("\n\nMASTER\n");
        }

#endif /* USE_DBGLINK */
        i = axradio_set_mode(RADIO_MODE);

        if (i != AXRADIO_ERR_NOERROR)
            goto terminate_radio_error;

#if defined(WTIMER0_PERIOD)
        wakeup_desc.time = wtimer0_correctinterval(WTIMER0_PERIOD);
        wtimer0_addrelative(&wakeup_desc);
#endif
    }
    else
    {
        /*  Warm Start */
        axradio_commsleepexit();
        IE_4 = 1; /* enable radio interrupt */
    }

    axradio_setup_pincfg2();
#ifdef TX_ON_DEMAND
    BUTTON_INTCHG |= BUTTON_MASK; /*interrupt on button changed (button SW5 on DVK-2) for wake on button pressed */
#endif /* TX_ON_DEMAND */

    for(;;)
    {
        wtimer_runcallbacks();
        __disable_irq();
#ifdef TX_ON_DEMAND
        {
            uint8_t buttonedge;
            {
                uint8_t p;
                p = BUTTON_PIN;
                buttonedge = saved_button_state & ~p;
                saved_button_state = p;
            }

            if (buttonedge & BUTTON_MASK)
            {
                __enable_irq();

                if( !deglitch_busy )
                {
                    deglitch_busy = 1;
                    transmit_packet();
                    display_transmit_packet();
                }

                continue;
            }
        }
        IE_3 = 1;
#endif  /* TX_ON_DEMAND */
        {
            uint8_t flg = WTFLAG_CANSTANDBY;
#ifdef MCU_SLEEP

            if (axradio_cansleep()
#ifdef USE_DBGLINK
                    && dbglink_txidle()
#endif
                    && display_txidle())
                flg |= WTFLAG_CANSLEEP;
#endif /* MCU_SLEEP */
            wtimer_idle(flg);
        }
        IE_3 = 0; /* no ISR! */
        __enable_irq();
    }

terminate_radio_error:
    display_radio_error(i);
#ifdef USE_DBGLINK
    dbglink_display_radio_error(i);
#endif /* USE_DBGLINK */
terminate_error:

    for (;;)
    {
        wtimer_runcallbacks();
        {
            uint8_t flg = WTFLAG_CANSTANDBY;
#ifdef MCU_SLEEP

            if (axradio_cansleep()
#ifdef USE_DBGLINK
                    && dbglink_txidle()
#endif
                    && display_txidle())
                flg |= WTFLAG_CANSLEEP;
#endif
            wtimer_idle(flg);
        }
    }
}

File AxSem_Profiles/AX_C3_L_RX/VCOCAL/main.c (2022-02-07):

/**
*************************************************************************************************************
* @file TESTS\main.c
* @brief Code for VCOCAL module, for calibration of the VCOI.*
* @internal
* @author   Thomas Sailer, Janani Chellappan, Srinivasan Tamilarasan, Pradeep Kumar GR
* $Rev: $
* $Date: $
*************************************************************************************************************
* Copyright 2016 Semiconductor Components Industries LLC (d/b/a “ON Semiconductor”).
* All rights reserved.  This software and/or documentation is licensed by ON Semiconductor
* under limited terms and conditions.  The terms and conditions pertaining to the software
* and/or documentation are available at http://www.onsemi.com/site/pdf/ONSEMI_T&C.pdf
* (“ON Semiconductor Standard Terms and Conditions of Sale, Section 8 Software”) and
* if applicable the software license agreement.  Do not use this software and/or
* documentation unless you have carefully read and you agree to the limited terms and
* conditions.  By using this software and/or documentation, you agree to the limited
* terms and conditions.
*
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
* @ingroup TEMPLATE_FIRMWARE_504x
*
* @details
*/

#include "../AX_Radio_Lab_output/configslave.h"

#if defined __ARMEL__ || defined __ARMEB__
#ifdef __AXM0
#include <axm0f143.h>
#include "axm0_config.h"
#include "axm0_xbar.h"
#include "axm0.h"
#include <stdbool.h>
#elif defined __AXM0F2
#include <axm0f243.h>
#include "axm0_config.h"
#include "axm0f2_pin.h"
#include "axm0f2.h"
#include <stdbool.h>
#endif // __AXM0
#else
#include <ax8052.h>
#endif //__ARMEL__ || defined __ARMEB__
#include <libmftypes.h>
#include <libmfradio.h>
#include <libmfflash.h>
#include <libmfwtimer.h>
#include <libmfdbglink.h>

#include "../COMMON/display_com0.h"

#ifdef MINI_KIT
#include <libminikitleds.h>
#else
#include <libdvk2leds.h>
#endif // MINI_KIT

#if !(defined __ARMEL__ || defined __ARMEB__)
#include <stdlib.h>
#endif

#include "../COMMON/misc.h"
#include "../COMMON/configcommon.h"
#include "../COMMON/easyax5043.h" /* TODO */

#include "../COMMON/display_com0.h"

#if defined(SDCC)
extern uint8_t _start__stack[];
#endif

uint8_t __data coldstart = 1; // caution: initialization with 1 is necessary! Variables are initialized upon _sdcc_external_startup returning 0 -> the coldstart value returned from _sdcc_external startup does not survive in the coldstart case
volatile axradio_trxstate_t __data axradio_trxstate = trxstate_off;
uint16_t __xdata vtune[64];
uint8_t __data range[2];

extern const uint32_t __code freqinc;
extern const uint32_t __code freqincmhz;
extern const uint32_t __code freqstart;
extern const uint32_t __code freqend;
uint32_t __data freq;

//#define MEMIO

#if defined(SDCC)
    static __xdata uint8_t __at(0x605) number_lines;
    static __xdata uint8_t __at(0x606) lines[50][133];
#elif defined __CX51__ || defined __C51__
    static uint8_t xdata number_lines _at_ 0x605;
    static uint8_t xdata lines[50][133] _at_ 0x606;
#elif defined __ICC8051__
    static __xdata __no_init uint8_t number_lines @ 0x605;
    static __xdata __no_init uint8_t lines[50][133] @ 0x606;
#elif defined __ARMEL__ || defined __ARMEB_
//    static uint8_t __xdata number_lines __attribute__((section(".ARM.__at_0x20000600")));
//    static uint8_t __xdata lines[50][100] __attribute__((section(".ARM.__at_0x20000604")));
    static uint8_t __xdata number_lines ;
    static uint8_t __xdata lines[50][100];
#endif

// Debug Link Configuration
#if defined __ARMEL__ || defined __ARMEB__
    #if defined USE_DBGLINK
        void debuglink_init_axm0(void)
        {
            #ifdef __AXM0
            axm0_xbar_dbglink_config(UART0_TX, UART0_RX_2, AXM0_XBAR_PIN_NOT_REQUIRED, AXM0_XBAR_PIN_NOT_REQUIRED); // tx_pin, rx_pin, UARTx_CLK pin, TxOUT pin
			#endif /* __AXM0 */
            dbglink_timer0_baud(0, 9600, AXM0XX_HFCLK_CLOCK_FREQ);  // HS OSC, Baud rate, Clock
            dbglink_init(0, 8, 1);
        }
    #endif // USE_DBGLINK
#endif // defined


#if defined __ARMEL__ || defined __ARMEB__
#ifdef __AXM0
void GPIO_Handler (void)
{

    // IRQ on PB3
    #ifdef TX_ON_DEMAND

        #ifndef MINI_KIT
            if(GPIO->INT_STS & BUTTON_MASK)
            {
                NVIC_ClearPendingIRQ;
                GPIO->INT_STS = BUTTON_MASK;
                // RIRQ on PR5
                if(GPIO->INT_STS & 0x20000000)                  // IRQ_PIN
                {
                    GPIO->INT_STS = 0x20000000;                 // IRQ_PIN
                    RADIO_IRQ();
                }
                else
                {
                    if(!deglitch_busy)
                    {
                        button_pressed = 1;
                    }
                }
            }
        #else
            if(GPIO->INT_STS & 0x20000000)                  // IRQ_PIN
            {
                NVIC_ClearPendingIRQ;
                GPIO->INT_STS = 0x20000000;                 // IRQ_PIN
                RADIO_IRQ();
            }

            if(GPIO->INT_STS & BUTTON_MASK)
            {
                NVIC_ClearPendingIRQ;
                GPIO->INT_STS = BUTTON_MASK;
                if(!deglitch_busy)
                    {
                        button_pressed = 1;
                    }
            }

        #endif // MINI_KIT
    #else
        // RIRQ on PR5
        if(GPIO->INT_STS & 0x20000000)                      // IRQ_PIN
        {
            NVIC_ClearPendingIRQ;
            GPIO->INT_STS = 0x20000000;                     // IRQ_PIN
            RADIO_IRQ();
        }
    #endif // TX_ON_DEMAND
}
#endif // __AXM0
#ifdef __AXM0F2
// IRQ on PB3 (0.2) or PR5 (2.4)
#ifdef TX_ON_DEMAND
#ifndef MINI_KIT
void GPIOPort0_Handler()
{
    NVIC_ClearPendingIRQ(GPIOPort0_IRQn);

    /* Serve INTR at 0.2 (PB3) */
    if(GPIO_PRT0->INTR & 0x04)
    {
        if(!deglitch_busy)
        {
            button_pressed = 1;
        }
    }

    /* clear PB3 0.2 interrupt */
    GPIO_PRT0->INTR |= 1<<2;
}
#else
void GPIOPort3_Handler()
{
    NVIC_ClearPendingIRQ(GPIOPort3_IRQn);

    /* Serve INTR at 3.6 (PB3) */
    if(GPIO_PRT3->INTR & 0x40)
    {
        if(!deglitch_busy)
        {
            button_pressed = 1;
        }
    }

    /* clear PC4 3.6 interrupt */
    GPIO_PRT3->INTR |= 1<<6;
}
#endif // MINI_KIT
#endif // TX_ON_DEMAND

#endif /* __AXM0F2 */
#endif /* defined __ARMEL__ || defined __ARMEB__ */



#if defined SDCC || defined __ICC8051__
static void pwrmgmt_irq(void) __interrupt(INT_POWERMGMT)
{
    uint8_t pc = PCON;
    if (!(pc & 0x80))
        return;
    GPIOENABLE = 0;
    IE = EIE = E2IE = 0;
    for (;;)
        PCON |= 0x01;
}
#endif // defined
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

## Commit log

2018-10-12 Generic card as a starting point.
    [l-band-frontend.brd, l-band-frontend.sch]
2018-10-19 Initial link model for primary uplink & downlink
    [AMSAT-IARU_Link_Model_Rev2.5.5_mod_PDX_CS0_primary.xlsx]
2018-10-19 Fix initial downlink receiver
    [AMSAT-IARU_Link_Model_Rev2.5.5_mod_PDX_CS0_primary.xlsx]
2019-01-31 Added noise temp. calculator for post LNA field on receivers page.
    [AMSAT-IARU_Link_Model_Rev2.5.5_mod_PDX_CS0_primary.xlsx, l-band-frontend.brd, l-band-frontend.sch]
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2019-04-14 Update to match L band v2.1 block diagram and minor fixes
    [AMSAT-IARU_Link_Model_Rev2.5.5_mod_PDX_CS0_primary.xlsx]
2019-04-14 Initial secondary uplink (UHF), uplink Tx and antenna need update
    [AMSAT-IARU_Link_Model_Rev2.5.5_mod_PDX_CS0_secondary.xlsx]
2019-04-15 Add Friis noise temp calculators
    [Friis_noise_temp_calculators.xlsx]
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2019-04-16 Update G.S. feed and BPF
    [AMSAT-IARU_Link_Model_Rev2.5.5_mod_PDX_CS0_primary.xlsx]
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2019-04-24 Update G.S. and modulations
    [AMSAT-IARU_Link_Model_Rev2.5.5_mod_PDX_CS0_primary.xlsx, AMSAT-IARU_Link_Model_Rev2.5.5_mod_PDX_CS0_secondary.xlsx]
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2019-05-05 Diagrams on Tx/Rx sheets, reduce Tx level, notes
    [AMSAT-IARU_Link_Model_PDX_CS0_v1_primary.xlsx, AMSAT-IARU_Link_Model_PDX_CS0_v1_secondary.xlsx]
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2019-05-06 Customize and fix summary sheet
    [AMSAT-IARU_Link_Model_PDX_CS0_v1_primary.xlsx, AMSAT-IARU_Link_Model_PDX_CS0_v1_secondary.xlsx]
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2019-05-17 Add UHF G.S. switch. Fix S/C point loss. Adjust Tx power.
    [AMSAT-IARU_Link_Model_PDX_CS0_v1_engineering_primary.xlsx, AMSAT-IARU_Link_Model_PDX_CS0_v1_engineering_secondary.xlsx]
2019-05-31 Initial Eagle dev boards
    [amp-LNA-TQP3M9036.sch, amp-LO-QPA4463A.sch, amp-PA-UHF-TQP7M9106.sch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]
2019-05-31 Gnd fix
    [mixer-MAC-24+.sch]
2019-06-04 Update backplane losses, S/C ant, & PA levels
    [AMSAT-IARU_Link_Model_PDX_CS0_v1_engineering_primary.xlsx, AMSAT-IARU_Link_Model_PDX_CS0_v1_engineering_secondary.xlsx]
2019-06-21 Add SMPM barrel. Update SC VSWR. Update SNR method.
    [AMSAT-IARU_Link_Model_PDX_CS0_v1_engineering_primary.xlsx, AMSAT-IARU_Link_Model_PDX_CS0_v1_engineering_secondary.xlsx]
2019-07-15 Microstrip 4-layer test board
    [microstrip-test-4-layer-sma-v1.brd, microstrip-test-4-layer-sma-v1.sch]
2019-07-15 Rcvd Infineon LNA and IF SAW
    [front-end-bom.xlsx]
2019-07-19 Revise passives, add TCXO options
    [synthesizer-RF-Si4123.sch]
2019-07-19 Add LDO, LED on auxout
    [synthesizer-RF-Si4123.sch]
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2019-07-25 Add 0ohm to TCXO, & minor tweaks.
    [synthesizer-RF-Si4123.brd, synthesizer-RF-Si4123.sch]
2019-07-25 Fix fonts
    [synthesizer-RF-Si4123.brd]
2019-07-25 Change resistor sizes. Add tstop to L1/2 traces.
    [synthesizer-RF-Si4123.brd, synthesizer-RF-Si4123.sch]
2019-07-25 Flip batt header
    [synthesizer-RF-Si4123.brd]
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2019-07-31 Adding parts for synthesizer-RF-Si4123
    [front-end-bom.xlsx]
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2019-08-06 Added lost breakout board for the AX5043 development modules we purchased.
    [DVK2C-breakout.brd, DVK2C-breakout.sch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]
2019-08-07 added silkscreen and some ground plane stitching for funsies
    [DVK2C-breakout.brd]
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2019-08-10 New boms and inventory
    [inventory.xlsx, synthesizers.xlsx, test-boards.xlsx]
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2019-08-13 Add features and minor fixes
    [amp-LNA-TQP3M9036.sch]
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2019-08-13 Add TQP3M903x initial layout
    [amp-LNA-TQP3M903x.brd]
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2019-08-17 Add parts to inventory
    [inventory.xlsx, synthesizers.xlsx]
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2019-08-17 Minor fixes
    [amp-LNA-TQP3M903x.brd, amp-LNA-TQP3M903x.sch]
2019-08-17 Add optional center bottom coax gnd pad
    [amp-LNA-TQP3M903x.brd]
2019-08-17 Adjust S band matching and add RF component MFG PNs
    [amp-LNA-TQP3M903x.brd, amp-LNA-TQP3M903x.sch]
2019-08-17 Add optional choke, and organize
    [amp-LNA-TQP3M903x.brd, amp-LNA-TQP3M903x.sch]
2019-08-21 Add separate UHF, L, and S band LNA evals with TQP3M9036/7
    [amp-LNA-L-band-TQP3M9037.brd, amp-LNA-L-band-TQP3M9037.sch, amp-LNA-S-band-TQP3M9037.brd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]
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2019-08-21 Change SMA via sizes
    [amp-LNA-L-band-TQP3M9037.brd, amp-LNA-S-band-TQP3M9037.brd, amp-LNA-UHF-TQP3M9036.brd]
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2019-08-22 Add stitching and finalize
    [mixer-MAC-24+.brd, mixer-MAC-24+.sch]
2019-08-23 Increase IF bend radius
    [mixer-MAC-24+.brd]
2019-08-23 Adjust RF clearance
    [mixer-MAC-24+.brd, mixer-MAC-24+.sch]
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2019-08-24 Assembled 1x dual-synthesizer board
    [inventory.xlsx, synthesizers.xlsx]
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2019-08-31 Initial LO amp schematic
    [amp-LO-TSY-1XXLNB+.sch]
2019-08-31 Fix RF clearance
    [mixer-MAC-24+.brd, mixer-MAC-24+.sch]
2019-08-31 Added enable control, and sync options for switching
    [power-linear-LP38692.sch, power-switching-TPS6211x.sch]
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2019-09-08 Add adjust for LP38692
    [power-linear-LP38692.brd, power-linear-LP38692.sch]
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2019-09-09 Add adj and power bad LED for TPS6211x
    [power-switching-TPS6211x.brd, power-switching-TPS6211x.sch]
2019-09-09 Change res sizes for LP38692
    [power-linear-LP38692.brd, power-linear-LP38692.sch]
2019-09-09 Updated S/C receiver LNAs with Infineon
    [AMSAT-IARU_Link_Model_PDX_CS0_v1_engineering_primary.xlsx, AMSAT-IARU_Link_Model_PDX_CS0_v1_engineering_secondary.xlsx]
2019-09-09 Add public downlink model
    [AMSAT-IARU_Link_Model_PDX_CS0_v1_public.xlsx]
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2019-09-09 Add boards inventory sheet
    [inventory.xlsx]
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2019-09-10 Minor fix TPS6211x
    [power-switching-TPS6211x.brd, power-switching-TPS6211x.sch]
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2019-09-12 Si4123 minor fix
    [synthesizer-RF-Si4123.brd]
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2019-09-13 Si4112, fix shutdown control and add bkup power down battery option
    [synthesizer-IF-Si4112.brd, synthesizer-IF-Si4112.sch]
2019-09-14 Si4112 fix note
    [synthesizer-IF-Si4112.brd, synthesizer-IF-Si4112.sch]
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2019-09-15 PA TQP7M9206, some updates, desgin will most likely use TQP7M9205
    [amp-PA-UHF-TQP7M9106.sch]
2019-09-15 LO amp TSY-1XXLNB+, minor updates, ready for initial layout
    [amp-LO-TSY-1XXLNB+.sch]
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2019-09-21 BP0805 & diplexer minor fix
    [bpf-L-band-BP0805.brd, diplexer-GPS-RF360-B8666.brd]
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2019-09-25 L band BPFs minor fixes
    [bpf-L-band-BPF-A1340+.brd, bpf-L-band-BPF-A1340+.sch, bpf-L-band-BPF-F1250+.brd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]
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2019-09-25 L band BP0805 minor fix
    [bpf-L-band-BP0805.brd]
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2019-09-26 BOM updates - add IF synth, filters, mixer
    [filter-misc.xlsx, inventory.xlsx, synthesizers.xlsx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]
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2019-09-29 Changed MiniCirc BPFs to 2-layer and adjusted for CBCPW
    [bpf-L-band-BPF-A1340+.brd, bpf-L-band-BPF-A1340+.sch, bpf-L-band-BPF-F1250+.brd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]
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2019-09-30 Archive v1 L, S, UHF Qorvo boards. Create wide band TQP3M9037 and optimize for NF
    [amp-LNA-L-band-TQP3M9037.brd, amp-LNA-L-band-TQP3M9037.sch, amp-LNA-S-band-TQP3M9037.brd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]
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2019-09-30 Inventory - add pwr brd bom variations, add LNA boms, update board inv.
    [amps.xlsx, inventory.xlsx, power.xlsx]
2019-10-02 Mixer - fix tCream for MAC-24+
    [mixer-MAC-24+.brd, mixer-MAC-24+.sch]
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2019-10-02 Update inventory and BOMs for parts received and add TPS62112 bom
    [inventory.xlsx, power.xlsx, synthesizers.xlsx]
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2019-10-19 LNA BFP740F fix layout bug
    [amp-LNA-BFP740Fxxx.brd]
2019-10-19 TRL kit fix layout bug
    [TRL-calibration-thru-reflect-match.brd]
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2019-11-05 Update mixer, minor fix
    [mixer-MAC-24+.brd]
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2019-11-19 Fix tCream on BFP740F
    [amp-LNA-BFP740Fxxx.brd, amp-LNA-BFP740Fxxx.sch]
2019-11-19 Update TRM kit, add more stop mask around match
    [calibration-thru-reflect-match-sma.brd]
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2019-11-29 Update 740F LNA, minor polygon fix
    [amp-LNA-BFP740Fxxx.brd]
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2020-07-22 Phase velocity correction
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2026-02-23 Swapped TQP7M9105 chip for GRF5504
    [amp-PA-GRF5504-with-detect.kicad_pcb, amp-PA-GRF5504-with-detect.kicad_sch]
2026-02-23 cleared some of the DRC errors
    [amp-PA-GRF5504-with-detect.kicad_pcb]
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2026-02-25 Excluded remaining DRC errors
    [amp-PA-GRF5504-with-detect.kicad_pcb]
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

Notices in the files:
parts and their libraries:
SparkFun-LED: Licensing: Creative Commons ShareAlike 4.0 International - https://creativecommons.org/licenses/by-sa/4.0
